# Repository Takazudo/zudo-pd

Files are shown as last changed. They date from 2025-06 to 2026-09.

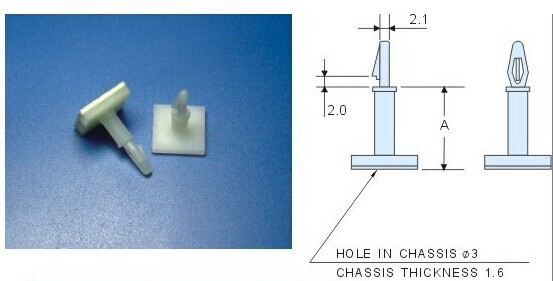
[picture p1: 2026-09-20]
manufacturing/releases/corner-support-review/mechanical/supports/hc11-tayda-drawing.jpg

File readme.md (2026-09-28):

# zudo-pd

A USB-C PD power-supply design for modular synthesizers, with a separate input board
and a synth conversion board for +12 V, −12 V and +5 V.

This is development hardware. The rail budgets are +12 V / 1.2 A, −12 V / 0.8 A and
+5 V / 0.5 A; they are targets, not measured capabilities. The renewed conversion
circuit uses AP63201, LT1963A and adjustable LT3015 parts with explicit headroom and thermal
qualification conditions.

Board B's screw-terminal revision is 110 × 85 mm, with two copper layers and
2 oz copper. Two top-side WJ500V-5.08-2P / C8465 blocks replace the four Fastons;
the wire entries face left. The board returns to a plain left edge and needs no
printed terminal guard. In the installed device, Board B stands on legs with its
front/component face downward. J5 is on that same front face, mating to the
face-down 27 × 40 mm Board P above B in CAD coordinates and below B when installed.
Front voltage labels remain, with normally readable duplicates on the back.
The PD module moves down to free an independent top-left support hole. All four
Ø3.0 mm corner-hole centers are 4 mm from the adjacent edges; the three Ø3.2 mm
PD mounting holes remain separate. P1 and TP3/TP4/TP5 move right together,
retaining seven top-edge contacts on 2.54 mm pitch.

See the [manufacturing guide](manufacturing/README.md) and
[corner-support review destination](manufacturing/releases/corner-support-review/) for prototype
fabrication and assembly review. The PCB is implemented and its native layout
and power-path checks pass; use the package reports for CAD and export status.
The previous front-stack package records the earlier geometry.

**HC-11's 11 mm support height does not clear this front-down assembly over a flat
floor:** the PD substrate reaches 12.7 mm and the terminal drawing maximum is
14.2 mm. The [printed adhesive leg](3dp-files/adhesive-leg/README.md) provides an
18 mm support height, a straight Ø7 mm pole and a 4.5 mm blind screw hole for
M3 × 5 mm screws through the nominal 1.6 mm PCB. See the
[support evidence](boards/board-b/supports/README.md). Physical wire fit, tightening
torque, adhesive retention, connector seating and full-load performance remain unmeasured.

**Board P requires verified 15 V-only operation.** Its new SMAJ16A / C74561
TVS has a 16 V standoff; factory 20 V negotiation is unsafe. First power and program
P from a current-limited 5 V-only source with B disconnected. Read back the NVM,
confirm all 20 V requests are disabled, and verify the configuration after a power
cycle before 15 V use. See the [Board P procedure](doc/src/content/docs/architecture/board-p.md).
The 26 V clamp test point and new 60 V D3 improve the conditioned stress screen;
actual surge, hot behavior and overshoot still require qualification.

## Start with the current design

- [Project brief](doc/src/content/docs/project/project-brief.md)
- [Board roles and interface](doc/src/content/docs/architecture/board-contract.md)
- [Component catalog](doc/src/content/docs/components/catalog/index.mdx)
- [Component-first workflow](doc/src/content/docs/project/component-first-design.md)
- [Release readiness](doc/src/content/docs/architecture/release-readiness.md)
- [Historical design archive](doc/src/content/docs/archive/index.mdx)

The renewal reuses a separate Board P input module and replaces the previous synth
headers and custom printed guards with DEALON DW254P-2X8-L0 / C4749189. Exact part
records, pin maps and source evidence live in `.claude/skills/` and generate the
human-readable component catalog.

## Documentation

The [documentation site](https://pd.takazudomodular.com) uses zudo-doc, MDX and Preact.

Run from the repository root after a frozen workspace install:

```sh
pnpm install --frozen-lockfile
pnpm dev
```

Open `http://localhost:4321`. `pnpm build` prepares the selected models and
component pages before the site build; `pnpm b4push` runs the complete guarded
repository check.

## Design files

`boards/` holds independent board projects. `scripts/schgen/` owns generated schematic
specs and checks. `symbols/` and `footprints/kicad/` hold canonical KiCad assets.
Read [boards/README.md](boards/README.md) before editing or regenerating a board.
The [portable assembly preview](boards/board-b/assembly-preview/preview.kicad_pcb)
opens the P/B stack in KiCad for mechanical review.

**Never use Git LFS.** Large assembled STEP previews are ignored local generated
files. Their [path and hash inventory](manufacturing/local-only-assembly-previews.json)
records exactly what is omitted from Git. The combined KiCad preview, individual
component models, standalone leg STEP, printable STLs and fabrication files remain
in ordinary Git.

A fresh clone does not contain those large review assemblies. Full prototype
checksum checks and the leg's whole-assembly verification require the original
local STEP bytes; they must fail if those bytes are missing or different. See the
[manufacturing guide](manufacturing/README.md#local-assembly-previews) for generating
a new assembly review with its own source and output hashes.

The root `zudo-pd.kicad_*` project and `jlcpcb-order-snapshots/` preserve the old
combined-board orders and their evidence. The [printed accessories](3dp-files/README.md)
contain the current adhesive legs. Only the latest renewal PCB, prototype outputs
and leg design are maintained; no renewal hardware has been released or ordered.

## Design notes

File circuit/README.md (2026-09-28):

# Circuit documentation runtime

This directory holds the zudo-pd-specific configuration, publication choices,
generation checks and project tests for the installed
`@takazudo/zudo-circuit-doc` package. Read [ARCHITECTURE.md](./ARCHITECTURE.md)
before changing the evidence-to-documentation contract.

The root `circuit.config.ts` maps the real evidence bundles, the three schematic
generator specs, KiCad assets and generated site paths into the package. The
package owns the generic validator, projection, renderer, UI and CLI. Project
publication policy and project-specific regressions stay here. Canonical hardware
and evidence rules remain in root [`CLAUDE.md`](../CLAUDE.md) and
[`WORKFLOW.md`](./WORKFLOW.md).

Run commands from the repository root. `pnpm circuit:check` validates the strict
project evidence and the package contract. `pnpm circuit:generate` regenerates the
component pages and preflight report. `pnpm check` checks output, CAD/model parity
and site types. After a build, `pnpm check:site` checks publication, links and
built output. The complete local gate is `pnpm b4push`; it uses one outer heavy
guard and leaves browser smoke as a separately guarded run.

The generated catalog is committed under `doc/src/content/docs/components/` and
must never be hand-edited. The package preflight report is
`circuit/generated/preflight.json`; selected preview assets are generated under
`doc/public/assets/component-previews/`.

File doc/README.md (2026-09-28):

# zudo-pd documentation

A component-first zudo-doc site built with zfb, MDX and Preact. Layout and navigation
come from the framework; this directory owns project content and the reviewed
component publication pipeline.

Install dependencies from the repository root with `pnpm install --frozen-lockfile`.
From the root, `pnpm dev` starts the site on port 4321, history on 4322, and the
package-owned component watcher. `pnpm build` prepares selected models and pages
before building the site. `pnpm b4push` runs the complete guarded repository gate.

The current reading path is **Getting Started → Architecture → Components → How-To**.
The Archive groups previous overview, diagnosis and learning pages at their stable
URLs. Old claims never override the current inventory or schematic.

`src/content/docs/components/` is generated by the installed circuit documentation
package from repo-root `.claude/skills/` evidence and `circuit.config.ts`. Edit exact
records, schematic bindings or publication policy, then prepare from the repository
root; do not hand-edit generated pages, SVG previews or model manifests. See
[CLAUDE.md](CLAUDE.md) and the root [circuit workflow](../circuit/WORKFLOW.md) for
authoring and validation details.

`zfb.config.ts` owns site settings and navigation. `pages/` contains package route
stubs. `src/chrome-bindings.tsx` registers the component previews. `public/` contains
reviewed static assets; deployment configuration remains in `wrangler.toml`.

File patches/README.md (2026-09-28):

# Circuit-doc 0.1.0 compatibility

Removal tracker: [zudo-pd #210](https://github.com/Takazudo/zudo-pd/issues/210).
The runtime request is `^0.1.0`; the root lock resolves the npm 0.1.0 tarball with
its registry integrity and its circuit-package patch hash. This patch edits the **shipped**
`lib/*.js`, their matching `.d.ts`, Python modules and packaged contract schema.
It does not import the upstream TypeScript source or the project validator.
Source review pin: `Takazudo/zudo-circuit-doc@5d0e2b630776489d394be341586b889dfe0d1cb8`.

Every hunk belongs to these linked contract groups (also linked in module headers):

| Upstream report | Shipped modules and changes |
| --- | --- |
| [#103](https://github.com/Takazudo/zudo-circuit-doc/issues/103) | `config/{define,schema,resolve,map}`, `validate/resolved-config`, Python `inventory/{common,led_generator_v1}`, `provider/v1/{evidence,index}`, `core/view-model`, `core/render/{shared,catalog,record}`: contained board/spec declarations; finite value-field MPN configuration; placement DNP and mixed state, with legacy line clients retained. |
| [#104](https://github.com/Takazudo/zudo-circuit-doc/issues/104) | `contract/schema.json`, config and resolved transport, Python `aggregate/orchestrator`, `provider/v1/{paths,evidence,index,canaries}`: candidate identity/owner validation, all owner bundles, unique global evidence IDs, explicit cross-partition rejection, and publication of inventory records only. |
| [#105](https://github.com/Takazudo/zudo-circuit-doc/issues/105) | `config/map`, `core/{publication,reference-descriptor,view-model}`, `provider/v1/{references,index,model-assets}`, `core/render/record`, `ui/component-references`, `scan/built-references`: disjoint selections/exceptions, independently unavailable cards, strict declared local files, nullable types and built-site assertions. |
| [#106](https://github.com/Takazudo/zudo-circuit-doc/issues/106) | `provider/v1/{index,integration,canaries}`, `core/view-model`, scanner positive controls and CLI scanner: nullable denied owners/package membership and matrix-aware denied owner canaries. |
| [#107](https://github.com/Takazudo/zudo-circuit-doc/issues/107) | `scan/artifacts`: configured generated-root exclusion; extra public files scanned; only reviewed canonical footprint hash fields excused in SITE manifests after recomputation and full path/symlink proof. OWNED canaries and other manifest fields remain strict. |

`circuit/publication/` retains the complete selection (59 documents and one honest
exception), 99 field decisions, the unchanged dated document audit and project
glosses. `assets.json` is the scaffold bootstrap allowlist; final site publication
and deliberate existing public assets are reconciled in #207.

`pnpm circuit:prepare` and `pnpm circuit:check` run the project's strict validator
and strict forward tests before invoking package operations. The installed CLI's
validator remains an additional contract gate. `circuit:doctor` is diagnostic.
The root workspace lock resolves both the repository and `doc/` to the same
patched installed modules. The circuit runtime patch and scaffold heading-extractor
patch are separate package boundaries; the old `doc/component-docs/` implementation
was retired in [zudo-pd #208](https://github.com/Takazudo/zudo-pd/issues/208). Root
runtime peers remain pinned to the scaffold versions for meaningful SSR tests.

## Zudo-doc 5.27.0 heading parity

The separate `@takazudo/zudo-doc` 5.27.0 patch is tracked for removal by
[zudo-pd #211](https://github.com/Takazudo/zudo-pd/issues/211). Its source behavior
is reviewed in [zudolab/zudo-doc #4428](https://github.com/zudolab/zudo-doc/issues/4428).
It aligns the built heading extractor with the zfb/CommonMark headings used by this
site, including inline code, character references and the depth window. The retained
strict source-link, built-fragment and redirect checks exercise the installed
scaffold behavior. Do not replace these checks with an allowlist or a looser link
warning rule.

The circuit package patch is temporary compatibility work tracked by
[zudo-pd #210](https://github.com/Takazudo/zudo-pd/issues/210). The scaffold removal
tracker is #211. Follow-up package work covers foreground Chrome scheduling
([#108](https://github.com/Takazudo/zudo-circuit-doc/issues/108)) and responsive
reference-card layout ([#109](https://github.com/Takazudo/zudo-circuit-doc/issues/109)).
The package's enlarged-media contract deliberately uses an empty image alt when the
dialog supplies the full accessible label; the project browser smoke asserts that
contract under [#110](https://github.com/Takazudo/zudo-circuit-doc/issues/110). This
is not a local #110 patch. Keep the project regressions enabled until released
upstream versions supply the contracts owned by each package.

`pnpm test:compatibility` exercises installed package files, never a source clone:
real CLI doctor/validate/generate/check/models/footprints, idempotency, exact corpus
identities/counts, 313 canonical evidence/spec file hashes, negative candidate
source/fact/pin-map mutations, mixed DNP, both finite MPN exceptions, old explicit
evidence anchors, independent SSR/descriptor cards, nullable-model CLI workflow,
missing/corrupt/ambiguous local models, denied owners, generated-root subtraction,
planted MDX/search/dist/public leaks and malformed/unproved/symlinked hash proofs.
The TypeScript consumer smoke checks the shipped declarations in strict mode;
`skipLibCheck` avoids checking unrelated dependency implementation declarations.

The canonical hash fixture is a closed migration baseline, **not** a regeneration
workflow. Changes require an independently reviewed evidence diff with every
changed field identified. Its `files` map is the exact list of hash-covered paths.
The candidate-only evidence stays on disk and under both validators; it is never
silently treated as inventory or as an independent reason to suppress a leak.

The root command surface owns strict project checks, generation, CAD/model parity,
site publication/link checks and guarded b4push. The retained project browser smoke
covers the document-gap record, resolved cards, model and footprint dialogs,
keyboard/focus/no-JS states, the illustrative inductor note and all 12 named
representatives. The PR workflow keeps the Cloudflare preview alias; the production
workflow keeps its guarded domain deployment. Neither workflow deploys from a local
build. Canonical evidence, hardware designs and generated component pages remain
owned by their existing project workflows and contracts.

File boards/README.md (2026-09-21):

# Board projects

The renewed design separates the USB-PD input module from synth conversion.

| Project | Role | Source ownership |
| --- | --- | --- |
| `board-p/` | Reusable USB-PD input module | Schematic generated from `scripts/schgen/board_p_spec.py`; routed PCB and `mechanical.json` own the geometry |
| `board-a/` | Previous USB-PD input-board design | Generated from `scripts/schgen/board_a_spec.py` |
| `board-b/` | Synth conversion, protection and output connectors | Schematic generated from `scripts/schgen/board_b_spec.py`; PCB has separate layout ownership |

The root combined-board KiCad files remain the historical v0.4.0 reference.
Use the [current architecture](../doc/src/content/docs/architecture/board-contract.md)
for interface roles and the [release gates](../doc/src/content/docs/architecture/release-readiness.md)
before exporting an order package.

Board B's screw-terminal revision is 110 × 85 mm with two copper layers,
2 oz outer copper and 76 schematic components. Two top-side WJ500V-5.08-2P / C8465 blocks have wire entries
facing left. J6 carries GND/−12 V and J7 carries +5 V/+12 V. J8/J9 are retired.
The active board has a plain left edge and requires no printed terminal guard.

Board B is installed on legs with its front/component face down. J5 now sits on
F.Cu with the other components. Board P faces that front surface: its component
face points down in CAD, with its front plane nominally at Z=+11.1 mm relative to
B's front plane. This places P physically below B in the installed orientation.
The mapping `pd_to_board_b(x, y) = (y−0.5, x+12)` transforms P's three mounting holes and
all six J5 mating pads together. Board P's own PCB is unchanged. Placement and
transform ownership is `scripts/pcb/board_b_layout.py`.
The P projection is x=−0.5–39.5 mm, y=12–39 mm, leaving B's top-left corner free.
J5 is at (37.2,24.9), 270°. PD holes H1/H2/H3 are Ø3.2 mm at (3.5,16),
(3.5,35) and (32.1,24.8).

The independent HC-11 corner holes H4/H5/H6/H7 are Ø3.0 mm NPTH at (106,4),
(4,81), (106,81) and (4,4), respectively. All four centers are 4 mm from the
adjacent edges. These are board-only holes; supports are separately procured
mechanical accessories, excluded from the electrical BOM and placement output.
The [support evidence](board-b/supports/README.md) retains the exact drawing and
its missing head/base envelopes. HC-11's 11 mm support height does not clear the
front-down assembly above a flat floor: P's substrate reaches 12.7 mm and the
terminal drawing maximum is 14.2 mm. The selected
[18 mm printed-leg prototype](../3dp-files/adhesive-leg/README.md) addresses that
nominal height conflict with separate CAD verification. It leaves the PCB and
JLCPCB package unchanged. Check actual M3 passage through the existing Ø3.0 mm
holes, printed fit, screw retention and adhesive loading. Its four bases require
a 116 × 91 mm adhesive footprint. The HC-11 evidence describes that earlier
support option, not physical testing of the printed leg.

Both front and back carry the screw-terminal voltage labels. Back labels use
B.SilkS mirroring so they read normally when viewed from the back. Validate them
against the same four electrical pins; changing the viewing side does not change
the pin assignments. Select leg and stack spacing from the populated assembly.

P1 plus TP3/TP4/TP5 retains a seven-contact top-edge row on 2.54 mm pitch at y=1.8 mm,
shifted 20 mm right to x=56.19–71.43 mm. Its voltage legend is centered at (88,2).
P1.3 is the shared probe ground; P1.4 remains NC. See the
[board contract](../doc/src/content/docs/architecture/board-contract.md) for exact pins.
The [corner-support review destination](../manufacturing/releases/corner-support-review/)
and [manufacturing guide](../manufacturing/README.md) track the current prototype.
The PCB is implemented and native layout and power-path checks pass; package
reports determine CAD and export status. Physical wire fit, tightening
torque, support clearance and retention, connector seating and full-load behavior
remain unmeasured. Active board files are authoritative; maintain only the latest
renewal PCB and prototype outputs. No renewal hardware has been released or ordered.
The current [printed accessory](../3dp-files/README.md) is the adhesive leg;
the plain-edge screw-terminal board requires no printed connector guard.

Board P D5 is now Littelfuse SMAJ16A / C74561, with a 16 V standoff. **20 V
negotiation is unsafe.** First power and program P at 5 V only with B disconnected;
read back the NVM, disable every 20 V request and verify the 15 V-only policy after
a power cycle before connecting a higher-voltage-capable PD source. Follow the
[Board P procedure](../doc/src/content/docs/architecture/board-p.md).
Board B D3 is SDT5A60SA-13 / C3024223, rated 60 V reverse. The conditioned 26 V / 25 °C
clamp screen clears the former table-point mismatch; installed surge and thermal
performance remain open.

## Generated schematics

Edit the spec, then regenerate the schematic; do not hand-edit generated output:

```sh
python3 scripts/schgen/gen_schematic.py board_p_spec
python3 scripts/schgen/gen_schematic.py board_a_spec
python3 scripts/schgen/gen_schematic.py board_b_spec
```

See `scripts/schgen/README.md` for baseline, decision and ERC verification. The
component audit must remain in parity with the exact generated MPN/LCSC/footprint
placements. A PCB change must be checked against that final schematic.

## Libraries resolve from each board directory

For projects two levels below the repository root, shared library references use:

```text
${KIPRJMOD}/../../symbols/zudo-pd.kicad_sym
${KIPRJMOD}/../../footprints/kicad/zudo-power.pretty
```

Open the paired `.kicad_pro` project in its board directory. Active 3D model paths
use `${KIPRJMOD}/../../footprints/kicad/zudo-pd.3dshapes/`; no global KiCad model
path setup is required. Export snapshots use rebased paths for their deeper
`source/` directory, which must not be copied back into the active board. Verify
both active boards with `scripts/pcb/check-model-paths.py` before exporting.
The [STEP datum audit](../footprints/kicad/step-datum-verification.json) checks
the reviewed active STEP/WRL pairs. Re-run it with `uv run scripts/pcb/verify-step-datums.py`;
its sampled surface comparison establishes model consistency, not physical fit.
L1's visible model is an illustrative maximum-body envelope, not an exact
manufacturer model; see the [manufacturing guide](../manufacturing/README.md).
The [portable P/B assembly preview](board-b/assembly-preview/preview.kicad_pcb)
shows the complete stack with local model files. It is a review copy, not the
manufacturing PCB; retain its verification report when sharing it.

Check a project's own library tables when importing a reusable module. Package names,
pad numbers, model paths and connector pin assignments must resolve in this repository.

## Connector and mounting changes

Board B J10/J11 use DEALON DW254P-2X8-L0 / C4749189 with the conventional synth power
pin map (pins 1–2 = −12 V). The shroud replaces custom printed guards. Derive edge
clearances from the actual connector body and mating cable; do not inherit the old
printed-part contour. Board P's mounting geometry belongs to its PCB source and
mechanical record, not to assumptions about the previous Board A design.

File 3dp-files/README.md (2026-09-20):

# Printed accessories

The current [adhesive-leg prototype](adhesive-leg/README.md) supports Board B at
its four existing corner holes. Each leg has an 18 mm PCB seating height, a
14 × 14 × 2 mm adhesive base and a straight Ø7 mm pole. A screw
enters from the PCB back into the user's proven, untapped M3 aperture: the exact
27-vertex profile forms a 4.5 mm blind bore. There is no taper or larger lower
cavity. Start with an M3 × 5 mm screw: through the 1.6 mm PCB it inserts 3.4 mm,
leaving a nominal 1.1 mm gap to the blind floor. The previous M3 × 8 mm
recommendation does not apply to this shorter bore.

This taller prototype addresses the nominal height conflict of the earlier 11 mm
HC-11 support. Printing, adhesive strength, M3 passage and retention still require
physical checks. The existing PCB corner holes remain nominally 3.0 mm, giving
zero nominal diametral clearance for an M3 screw. The accessory does not change
the PCB or the current JLCPCB prototype package. See its README and verification artifacts
for the prototype's scope and limits.

The current 110 × 85 mm Board B uses two top-side WJ500V-5.08-2P / C8465 screw-terminal
blocks and shrouded DEALON synth headers. It requires no printed connector guard.
Only the current adhesive-leg design is maintained here. Current prototype
manufacturing outputs are in `manufacturing/releases/corner-support-review/`;
no renewal hardware has been released or ordered.

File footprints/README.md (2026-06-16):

# PCB Footprints and Package Specifications

This directory contains PCB footprint diagrams and package specifications for all components used in the USB-PD modular synthesizer power supply project.

## Footprint Images

| Component | File | Package | JLCPCB Part | Mount Type |
|---|---|---|---|---|
| **CH224D** | `CH224D.png` | QFN-20 (3×3mm) | C347423 | SMD |
| **LM2596S-ADJ** | `LM2596S-ADJ.png` | TO-263-5 | C347423 | SMD |
| **L7812CV** | `L7812CV.png` | TO-220 | C86206 | Through-hole |
| **L7805ABD2T** | `L7805ABD2T.png` | TO-263-2 (D2PAK) | C2914 | SMD |
| **CJ7912** | `CJ7912.png` | TO-252-2L (DPAK) | C94173 | SMD |
| **SMAJ15A** | `SMAJ15A.png` | SMA (DO-214AC) | C571368 | SMD |
| **PRTR5V0U2X** | `PRTR5V0U2X.png` | SOT-143 | C5199240 | SMD |
| **USB-TYPE-C-009** | `USB-TYPE-C-009.png` | 6-pin Type-C | C456012 | SMD |

## Package Documentation (PDFs)

Reference documents for standard package types:

### Component-Specific Datasheets
- `CH224D-datasheet.pdf` - WCH CH224D USB PD controller full datasheet
- `LM2596S-datasheet.pdf` - LM2596S-ADJ DC-DC converter datasheet
- `SMAJ-datasheet.pdf` - SMAJ series TVS diode specifications

### Generic Package Specifications
- `D2PAK-package.pdf` - TO-263-2 package dimensions (L7805ABD2T)
- `DPAK-package.pdf` - TO-252 package dimensions (CJ7912)
- `SMA-package.pdf` - DO-214AC package dimensions (SMAJ15A)
- `SMA-DO214AC.pdf` - Alternate SMA package specification
- `SOT143-package.pdf` - SOT-143 package dimensions (PRTR5V0U2X)
- `TO-220-package.pdf` - TO-220 package dimensions (L7812CV)

## Usage Notes

### For PCB Layout Design
1. **Footprint images** (`.png` files) show:
   - Package outline dimensions
   - Pin/pad layout and numbering
   - Recommended PCB land pattern
   - Thermal pad requirements (where applicable)

2. **Package PDFs** provide detailed specifications:
   - Precise mechanical dimensions
   - Tolerances and variations
   - Soldering recommendations
   - 3D package profiles

### Thermal Considerations
- **QFN-20 (CH224D)**: Requires exposed pad connection with thermal vias
- **TO-263/D2PAK (LM2596S-ADJ, L7805ABD2T)**: Metal tab for heat dissipation
- **TO-252/DPAK (CJ7912)**: Metal tab soldered to PCB copper pour
- **TO-220 (L7812CV)**: Through-hole with optional heatsink mounting

### SMD vs Through-Hole
- **7 SMD components**: CH224D, LM2596S-ADJ, L7805ABD2T, CJ7912, SMAJ15A, PRTR5V0U2X, USB-C connector
- **1 Through-hole**: L7812CV (TO-220) - can use heatsink if needed

## Sources

Footprint images and datasheets obtained from:
- Manufacturer official websites (WCH, STMicroelectronics, Diodes Inc., Nexperia, etc.)
- JLCPCB component library
- Industry-standard package specification documents
- SnapEDA and similar PCB design resources

All footprints extracted at 200-300 DPI resolution for PCB design clarity.

---

*Last updated: 2025-12-28*

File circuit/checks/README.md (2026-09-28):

# Checks

What each project check establishes, and what it does not. Report a check's actual output, including its `SCOPE:`, `SKIP:` and `WARN:` lines; never summarize a skipped check as passed.

| Command | Establishes | Does not establish |
| --- | --- | --- |
| `pnpm circuit:check` | The evidence bundles, inventory, routing, integration rules and (when CAD is enabled) pin assets satisfy the v1 contract; the package's seeded self-test still detects known mutations | That any electrical claim is correct for the design, that a source was read correctly, or that declared placements match a schematic (see the `SCOPE:` line) |
| `pnpm circuit:generate` | Generated component pages and `circuit/generated/preflight.json` reflect the current evidence and selection | That the evidence is current with its remote sources |
| `pnpm check` | Validation passes, committed generated output matches a dry-run generation (drift and ownership conflicts), selected models and footprint previews match their inputs, the doc site type-checks | Anything about the built HTML |
| `pnpm build` then `pnpm check:site` | The built site references only files that exist, publishes nothing outside the selection and the assets allowlist, and has no broken links or anchors | Visual rendering or island behavior in a browser |
| `pnpm b4push` | Retained circuit tests, strict project Python gates, host types and CAD/model checks, build, site checks and generated output drift/idempotency under one outer heavy guard | Browser behavior; run a browser suite separately |
| `pnpm test:model-viewer:browser` | The project's 12 named component representatives render at two widths and two themes, with viewer, dialog, no-JS, navigation and illustrative-model assertions | Anything about electrical performance or hardware fit; it requires a built site and Chrome |
| `pnpm exec zudo-circuit-doc check-browser` | Additional scaffold browser coverage for configured representatives or up to 3 derived representatives | Anything about a representative it never resolved (reported `SKIP`), and anything at all when it exits `4` |
| `pnpm exec zudo-circuit-doc validate --online` | Retained non-volatile source hashes still match the bytes the URLs serve today | That the documents support the recorded claims; it never alters retained evidence |
| `pnpm previews:generate`, `pnpm exec zudo-circuit-doc footprints check` | Footprint SVG previews are rendered from, and match, the selected footprints | Dimensional correctness or pin correspondence; a preview is a rendering |
| `pnpm circuit:doctor` | Which required and optional tools are present | That any check passes |

### `check-browser` representative pages

The scaffold `check-browser` resolves which pages to exercise in this order:

1. `--representatives <json>` on the command line.
2. `browserSmoke.representatives` in `circuit.config.ts`, used exactly as configured — even an explicit empty list.
3. Otherwise, up to 3 representatives **derived** from the preflight report: published record slugs, sorted, filtered to the ones whose generated page has a decodable component-references section (a reviewed PDF, a footprint and a WRL model), and, once the site is built, whose built output carries the matching marker and assets. A derived run prints `INFO: using derived representatives: ...`.

A declared-zero project (nothing published) is a `SKIP`, not a failure. If records are published but derivation finds none that qualifies, the command exits `4` rather than silently checking nothing — set `browserSmoke.representatives` in `circuit.config.ts` to name pages explicitly.

The project smoke is separate because its 12 representative list also covers the `rec-c335982` document gap and the illustrative inductor model note. For a local browser run, serialize both the heavy process and browser launch:

```sh
bash "$HOME/.codex/scripts/heavy-guard.sh" -- bash "$HOME/.claude/scripts/playwright-guard.sh" --wait 300 -- pnpm test:model-viewer:browser
```

Exit 75 from `heavy-guard` means the suite did not run; read its `verdict=` line first, retry `ENV_SUSPECT` once, and defer a persistent environment failure. Exit 75 from `playwright-guard` means another browser session owns the slot; wait and retry. Exit 4 for a missing optional browser is `not run`, never a pass, and does not satisfy a mandatory issue or PR browser gate.

## Exit codes

| Code | Meaning |
| --- | --- |
| `0` | Pass |
| `1` | Check failed |
| `2` | Usage or configuration error |
| `4` | Not run: an optional tool (Docker, Chrome) is missing, or (`check-browser` only) records are published but none qualifies for a default representative and none was configured |

## What no check establishes

`COVERED` coverage, a clean validation and a green build are not hardware sign-off. Physical fit, assembled state, programmed state and bench behavior are established only by recorded observations (Workflow F in [WORKFLOW.md](../WORKFLOW.md)).

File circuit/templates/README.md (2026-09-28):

# Authoring templates

These templates are **not published**. Copy one into the documentation tree when the activity it describes actually happens; do not publish empty copies to fill the navigation.

## Project documentation templates

The `project-docs/` tree mirrors the site's sections. To use a template, copy it to the same relative path under `doc/src/content/docs/`, give the copy a topic-specific filename, `title`, `description` and `sidebar_position`, and replace the "Not entered" prompts as facts become known. Links inside a template point at the sibling template locations; after copying, keep a link only if its target page exists in the site.

| Template | Use it when | What to enter |
| --- | --- | --- |
| [project/index.mdx](./project-docs/project/index.mdx) | The brief must be rebuilt from scratch (the live brief is already published at `project/index.mdx`) | Purpose, user behavior, constraints, current design revision |
| [project/next-actions.mdx](./project-docs/project/next-actions.mdx) | Resetting the handoff page (the live page is already published) | Current open questions, the next bounded task, blocked work |
| [project/task-request.mdx](./project-docs/project/task-request.mdx) | Delegating a bounded research or implementation task to an agent | Goal, scope, references, outputs and a definition of done |
| [project/change-impact.mdx](./project-docs/project/change-impact.mdx) | Before applying a change with downstream effects (Workflow G) | Affected components, interfaces, generated assets and tests |
| [architecture/overview.mdx](./project-docs/architecture/overview.mdx) | Resetting the architecture overview (the live page is already published) | Functional blocks, operating states, unconfirmed boundaries |
| [architecture/interfaces.mdx](./project-docs/architecture/interfaces.mdx) | Once blocks or connectors are proposed | Power, signal, mechanical and programming boundaries |
| [research/component-candidate.mdx](./project-docs/research/component-candidate.mdx) | Comparing or researching a component (Workflow A) | Research question, criteria, linked evidence, missing proof |
| [decisions/decision.mdx](./project-docs/decisions/decision.mdx) | Making a consequential choice | Alternatives, chosen direction, tradeoffs, evidence and conditions |
| [decisions/sourcing.mdx](./project-docs/decisions/sourcing.mdx) | Assembly or procurement becomes relevant | Population policy, cost reasoning, dated sourcing observations |
| [verification/bring-up.mdx](./project-docs/verification/bring-up.mdx) | Planning or recording one verification run (Workflow F) | Revision, setup, planned checks, results and limits |

For repeated records, duplicate the relevant template with a topic-specific filename. A decision ID identifies a decision across edits; a verification report identifies one execution against one revision, so never overwrite a failed run with a later successful one.

These pages explain intent, rationale and decisions. Exact component identity, sources, facts, pin maps and coverage belong to the owner evidence bundles under `.claude/skills/component-*/`; the component pages under `/docs/components/` are generated from them. Do not maintain a second rating table, pin table or catalog by hand. When an argument needs a number, cite the canonical fact ID and keep its qualifier and conditions.

## CAD asset receipt

| Template | Use it when |
| --- | --- |
| [cad-asset-receipt.json](./cad-asset-receipt.json) | Recording an acquired symbol, footprint or 3D model (Workflow D); save the copy as `circuit/cad-receipts/ASSET_ID.receipt.json` |
| [cad-asset-receipt.md](./cad-asset-receipt.md) | Explains every receipt field and the fidelity classes; copy it beside the JSON only when a longer explanation is needed |

See [WORKFLOW.md](../WORKFLOW.md) for the workflows that use each template and [agent-task-examples.md](../agent-task-examples.md) for short requests that lead to them.

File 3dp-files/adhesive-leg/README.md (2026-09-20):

# Adhesive PCB leg with M3 screw grip

Print **four legs** for the current Board B. The leg has an **18 mm seating height**,
a broad flat adhesive base and a screw hole copied from the user's repeatedly
tested `bar-30hp.stl`. No modeled thread, tap or threaded insert is required by this
design; the screw engages the same printed aperture as the reference rail.

- [Single leg STL](generated/adhesive-leg-18mm-m3.stl)
- [Four separate legs on one print plate](generated/adhesive-leg-18mm-m3-4x.stl)
- [Preview](generated/preview.png) and [section view](generated/section.png)
- [Editable STEP](generated/adhesive-leg-18mm-m3.step)
- [Installed assembly](generated/installed.png) and [fit report](generated/fit-check.json)

All dimensions are millimetres. Print at **100% scale**, with the flat base on the
bed and the screw opening upward. Use the material and hole-compensation settings
that worked for the tested rail. The straight vertical bore needs no supports.

| Feature | Dimension |
|---|---|
| Adhesive face to PCB seating face | 18 mm |
| Base | 14 × 14 × 2 mm, rounded corners R2 |
| Pole and PCB seating face | Straight Ø7 mm; no top taper |
| Pole-to-base reinforcement | R2 fillet |
| M3 gripping section | Exact reference polygon, 4.5 mm deep |
| Total blind depth | 4.5 mm; no lower cavity |
| Solid material below blind hole | 13.5 mm |

The measured reference hole is slightly lobed, with 27 straight edges and a
2.8928 × 2.9149 mm bounding box. Those dimensions are not a circular drill size.
[reference-bore.json](reference-bore.json) retains the exact polygon from source
hole 12, its original coordinates and source hash. The upper 4.5 mm gripping
section preserves that profile without taper, smoothing or an entrance chamfer.
The hole ends after that 4.5 mm section; everything below it is solid.
The original rail STL is unchanged.

Use an **M3 × 5 mm non-countersunk screw**, inserted from the visible PCB back
into the leg. Through the 1.6 mm board it enters 3.4 mm, leaving 1.1 mm to the
blind floor. An M3 × 6 mm screw with a washer at least 0.5 mm thick enters at
most 3.9 mm, leaving at least 0.6 mm. These are nominal dimensions; verify the
actual hardware stack. **The earlier M3 × 8 mm screw is too long for this revision.**
Fit the legs and screws before applying adhesive to the flat undersides.

The existing PCB corner holes are nominally **3.0 mm**, so a nominal Ø3 mm screw
has zero designed passage clearance. Check that the actual screw passes freely
through the finished PCB hole; this STL task does not enlarge the PCB holes or
change the JLCPCB package. The copied plastic gripping aperture and the PCB
passage hole serve different purposes.

The four feet sit at H4 (106,4), H5 (4,81), H6 (106,81) and H7 (4,4). Their bases
extend 3 mm beyond the PCB edges, requiring a **116 × 91 mm** adhesive footprint.
The PCB remains 110 × 85 mm. The 7 mm seating diameter keeps the leg clear of the
nearby top-right fuse. The earlier taper served this clearance; a straight
7 mm pole maintains it throughout the post. With an 18 mm seating
height, the 14.2 mm terminal envelope has 3.8 mm nominal floor clearance. Adhesive
tape adds its compressed thickness; no tape allowance is needed to obtain the
18 mm geometry.

The [fit report](generated/fit-check.json) records checks against the current
populated B+P assembly, including the four whole legs and conservative component
envelopes. Printed fit, screw retention/torque, adhesive grip and temperature
performance remain physical checks. The user's proven rail geometry is the screw
fit reference; it is not a new load or material qualification for these legs.

Regenerate and verify:

```sh
uv run 3dp-files/adhesive-leg/generate.py
uv run 3dp-files/adhesive-leg/verify.py
```

[spec.json](spec.json) holds the editable dimensions. The generator emits the
single STL, four-part plate, STEP and rendered views for the current design. The verifier checks the
actual exported geometry and assembly; its optional reference-STL argument can
also recheck the user-supplied rail. Existing PCB and manufacturing files are
read-only inputs.

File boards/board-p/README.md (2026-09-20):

# Board P — reusable USB-PD core

Board P is the current routed power-input module. It supplies the downstream Board B
through the six-position XFCN header pair. Board A remains historical schematic
evidence; its gate network and connector are different and must not be treated as
Board P's as-built circuit.

`../../scripts/schgen/board_p_spec.py` is the schematic source of truth. Regenerate:

```sh
python3 scripts/schgen/gen_schematic.py scripts/schgen/board_p_spec.py
```

The PCB retains the routed module's pad/copper geometry. Shared exact parts use the
current project's canonical library names, while the PCB embeds its retained physical
footprints. Updating all PCB footprints from the shared library would change that
geometry and requires a fresh layout review. `layout-verification.json` records the
import comparison; `mechanical.json` records dimensions and mating coordinates.

## Interface and mechanical contract

| JOUT1 pin | Net | Function |
| --- | --- | --- |
| 1, 2 | VBUS_OUT | Switched nominal 15 V; paired power contacts |
| 3 | ATT | Active-low open-drain attach indication |
| 4 | PDOK | Open-drain contract indication; depends on programmed configuration |
| 5, 6 | GND | Paired return contacts |

JOUT1 is PZ254V-11-06P (C492405); Board B J5 is PM254V-11-06-H85
(C2832269). The pair is unkeyed. Verify pin-1-to-pin-1 orientation and every net
before mating. The old Board A JST XH connector has a different pitch and does not
mate directly. Both XFCN parts have a manufacturer 3 A contact rating; paired contacts
do not raise the USB-PD source's 3 A contract limit.

The board is 27 × 40 mm, two layers, 1.6 mm thick. Its mounting holes are 3.2 mm
NPTH for M3 hardware at (4, 4), (23, 4), and (12.8, 32.6) mm, measured from the
upper-left outline corner in KiCad coordinates. JOUT1 pin 1 is at (6.55, 37.7) mm;
subsequent pins advance 2.54 mm along X. The USB opening is at the y=0 edge.
The female body is 8.5 mm tall; actual board spacing and mating engagement require
a stack fit check rather than assuming that body height equals the standoff length.

## Circuit and configuration state

The intended configuration is two sink PDOs, PDO2 = 15 V / 3 A, and
`POWER_ONLY_ABOVE_5V = 1`. **No retained programmed NVM image, persistent readback,
or bench-qualified 3 A output accompanies this PCB.** The design intention does not
establish the factory or installed state. First provision with a current-limited
5 V-only source and the downstream board disconnected. Retain the received image,
40-byte programmed image, byte-for-byte readback, reset reload and full power-cycle
readback before connecting a PD source and load.

Board P's 100 kΩ/150 kΩ gate divider gives ideal steady VGS = −6 V at 15 V and
−8 V at 20 V. C35 connects gate to source; R21 is a 10 kΩ reset pull-down with
RESET available on J2.4. These are Board P facts. The retained Board A records describe
its older 56 kΩ gate resistor, ground-referenced C35, and grounded reset.

Open electrical gates remain: VREG_2V7 feeds 4.7 kΩ I2C pull-ups even though retained
controller documentation only authorizes decoupling; confirm manufacturer approval
or revise this circuit and verify programming-jig logic levels. The SMAJ20A's 32.4 V
clamp table point exceeds Q1's 30 V VDS and the controller's retained 28 V absolute
maximum; actual source/rail/gate transient waveforms and duration remain unmeasured.
NVM policy, switch inrush, steady full-load temperature, and connector temperature
must be checked with the actual downstream load. The nominal 45 W contract alone
cannot establish those results.

## Checks and manufacturing state

The renewal check passed native KiCad netlist comparison (23 nets, 91 nodes), ERC
with zero errors, and PCB DRC with zero errors and zero unconnected items. The
strict component registry and its 53 contract tests passed. The order exporter
accepted 19 fitted components in 14 BOM lines, all on the top side. R17/R18 and
D6/D7 remain intentionally DNP; J2/J3 and MH1/MH2/MH3 are bare copper/mechanical
features excluded from assembly.

Retained warnings are explicit: 29 ERC pin-type warnings; 50 PCB DRC warnings
(23 shared-library footprint mismatches, 19 small-text, 3 silk-over-copper,
2 silk-to-edge, 1 silk overlap, 1 duplicate SCL via, 1 dangling gate-track stub);
three schematic-parity warnings identify the PCB-only mounting holes. No ERC/DRC
error was disabled to obtain these results. Warnings do not establish an assembled
or bench-qualified product.

The XFCN male and female drawings were downloaded on 2026-09-20, confirmed as
PDF drawings for the specified connector families and six-position dimension
rows, and matched their retained SHA-256 values. The current HRO drawing request
returned HTTP 403, so its earlier retained manufacturer extract remains the evidence
and the current retrieval was not represented as a new successful verification.
Yageo and UNI-ROYAL primary documents were readable during the renewal audit.

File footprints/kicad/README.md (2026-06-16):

# KiCad Footprints

This directory contains KiCad footprint files (.kicad_mod) for components used in this USB-PD power supply project. All footprints were downloaded from LCSC/EasyEDA using the [easyeda2kicad.py](https://github.com/uPesy/easyeda2kicad.py) tool.

## Key Component Footprints

### USB-PD Stage
- **QFN-20_L3.0-W3.0-P0.40-BL-EP1.7.kicad_mod** - CH224D USB PD Controller (C3975094)
- **TYPE-C-SMD_TYPE-C-6P.kicad_mod** - USB Type-C 6P Female Connector (C456012)

### DC-DC Converter Stage
- **TO-263-5_L10.2-W8.9-P1.70-BR.kicad_mod** - LM2596S-ADJ Buck Converter (C347423) — also used for U4 in inverting buck-boost config

### Linear Regulator Stage
- **TO-220-3_L10.0-W4.5-P2.54-L.kicad_mod** - LM7812CV +12V Regulator (C2914)
- **TO-263-2_L10.0-W9.2-P5.08-LS15.3-TL-CW.kicad_mod** - L7805ABD2T +5V Regulator (C86206)
- **TO-252-3_L6.5-W5.8-P4.58-BL.kicad_mod** - CJ7912 -12V Regulator (C94173)

### Passive Components
- **C0603.kicad_mod** - 0603 Capacitor
- **R0603.kicad_mod** - 0603 Resistor
- **CAP-SMD_BD4.0-L4.3-W4.3-LS5.0-FD.kicad_mod** - SMD Electrolytic Capacitor (small)
- **CAP-SMD_BD18.0-L19.0-W19.0-LS20.4-FD.kicad_mod** - SMD Electrolytic Capacitor (large)

### Protection & Indicators
- **SMA_L4.4-W2.8-LS5.4-RD.kicad_mod** - SMA Diode Package (TVS, Schottky)
- **SOD-123FL_L2.8-W1.8-LS3.7-RD.kicad_mod** - SOD-123FL Diode Package
- **LED0603-RD.kicad_mod** - 0603 LED (Red)
- **LED0603-R-RD_WHITE.kicad_mod** - 0603 LED (White)

### Connectors
- **HDR-TH_16P-P2.54-H-M-R2-C8-S2.54.kicad_mod** - 16-pin 2.54mm Through-hole Header (Eurorack Power)
- **HDR-TH_3P-P2.54-V-M.kicad_mod** - 3-pin 2.54mm Through-hole Header
- **HDR-SMD_6P-P2.00-V-M_XBK_R2.kicad_mod** - 6-pin 2.00mm SMD Header
- **HDR-SMD_8P-P2.54-V-M-LS4.8_R2.kicad_mod** - 8-pin 2.54mm SMD Header
- **DC-IN-TH_DC550250-0366-2H.kicad_mod** - DC Input Jack (Through-hole)

## Usage

### In KiCad
1. Add this directory to your KiCad footprint library list
2. Select footprints when assigning components in your schematic

### Downloading Additional Footprints

To download footprints for other components:

```bash
easyeda2kicad --lcsc_id <LCSC_ID> --footprint
```

The footprints will be saved to `~/Documents/Kicad/easyeda2kicad/easyeda2kicad.pretty/` and can be copied to this directory.

Example:
```bash
# Download CH224D footprint
easyeda2kicad --lcsc_id C3975094 --footprint

# Copy to project
cp ~/Documents/Kicad/easyeda2kicad/easyeda2kicad.pretty/*.kicad_mod ./
```

## Notes

- All LCSC part numbers are referenced in `/doc/docs/inbox/parts-list.md`
- Footprints include pads, silkscreen, and courtyard layers
- Some footprints may include 3D model references (if available from EasyEDA)

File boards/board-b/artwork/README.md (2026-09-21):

# Board B back silkscreen

The current PCB uses the two SVGs supplied for the back artwork:

- `pattern.svg`: unchanged copy of `Asset 6.svg`.
- `logo.svg`: unchanged copy of `Asset 5.svg`.

The pattern fills the back-view left area, with an unprinted strip on the right
for branding, terminal labels and the four-line specification block:

```text
zudo-pd v1
+12V : 1.2A
-12V : 0.8A
+5V : 0.5A
```

The current values are shared whole-board design targets, with physical full-load
and temperature qualification still open. The SVG
pattern is heavier than the thin-line rough mockup. Its proportions are preserved
and its top/bottom are cropped to the board. The supplied mirrored logo is split
into emblem and lettering and rotated 90 degrees. In the portrait back view
shown by the user, the emblem sits on the left and the two-line brand name on the
right; both read normally. Fine feather and fish details may merge or disappear
in physical printing.

`back-preview.png` is a native KiCad render of the actual PCB;
`back-portrait-preview.png` shows the rotated view used for the branding layout. Open
`../board-b.kicad_pcb` and view its bottom side to inspect the editable artwork.
It consists of filled `B.SilkS` polygons and four mirrored text items in the
`Board B back artwork` group. Copper, mask layers, holes, component placement,
front silkscreen and existing back voltage labels are unchanged.

The pattern has a 0.8 mm outline inset. Artwork is clipped at least 0.3 mm outside
conservative pad/mask bounding boxes, with another 0.3 mm around the complete
J5, J10 and J11 solder rows. No graphics are added to copper or solder mask.
This is decorative artwork, not an insulation or thermal treatment.

Regenerate into an ignored staging path with:

```sh
uv run scripts/pcb/apply-back-silkscreen.py \
  --branding-only \
  --output tmp/back-silk/candidate.kicad_pcb \
  --report tmp/back-silk/verification.json
```

`--branding-only` preserves the existing native pattern polygons byte-for-byte,
including manual edits. Omit it when generating the complete artwork for a fresh
layout. Existing user-edited rail-label positions and styling are always retained.

The script uses the retained SVGs, resolves nonzero SVG fills and their holes,
flattens curves, clips artwork around board pads, and uses KiCad polygon fracture
to retain internal openings. It replaces its previous generated group and the
old one-line title. It refuses any change to the remaining PCB structure.
`verification.json` records that structural check and the source/result hashes.

Inspect a bottom render and run native DRC before promoting a candidate. Refresh
PCB-dependent reports and the sole current prototype package afterward; do not
keep superseded output packages. The original local KiCad project-settings edit
is separate from this artwork change.

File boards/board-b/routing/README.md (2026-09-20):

# Corner-support routing

The active PCB is 110 × 85 mm. J5 is on the front at (37.2,24.9), 270 degrees.
Board P faces Board B with P(x,y) mapping to B(y−0.5,x+12); its nominal CAD face plane is
11.1 mm above B. In the installed orientation B faces down on legs and its back
silkscreen is visible from above. Nominal CAD spacing is not a qualified spacer.

P projects to x=−0.5–39.5 mm, y=12–39 mm, freeing the independent top-left support.
Its three Ø3.2 mm holes are H1(3.5,16), H2(3.5,35) and H3(32.1,24.8).
The four independent HC-11 Ø3.0 mm corner holes are H4(106,4), H5(4,81),
H6(106,81) and H7(4,4). Keep those interfaces separate.

C5 moves to (18,6), 0°; C46 to (28,6.5), 180°; C32 to (26,22), 0°;
R3 to (26,29), 180°; R4 to (26,26), 90°; and D2 to (33.75,35), 90°.
The complete seven-contact pogo row moves 20 mm right: P1 center (60,1.8),
TP3/TP4/TP5 at (66.35,1.8)/(68.89,1.8)/(71.43,1.8). Its voltage legend is
centered at (88,2). Preserve all electrical assignments and both-side terminal labels.

The active `../board-b.kicad_pcb` is the layout source. Current placement rules
are in `scripts/pcb/board_b_layout.py`; do not reconstruct the PCB from a
superseded migration input or route session.
Input paths use 1.5 mm traces; measurement and status branches use 0.25 mm.
Load outputs retain the 1 mm screen. Measurement branches are excluded from
current-path proofs. Existing ground pours remain; affected old ground branches
are removed so the filled planes reconnect their pads. All existing ground,
thermal, connectivity and current-path checks still apply.

Copy the active `.kicad_pro` beside a temporary PCB after generation, because a
native pcbnew save can reset project defaults. Refill and check the candidate,
then promote only after native DRC and mechanical/power checks pass. Run parity
against the actual matching schematic and project. Use `configure-board-b.py`
after native project changes to restore the reviewed routing/manufacturing rules.

For a fresh route, `place-board-b.py` generates current placement,
`prepare-routing.py` applies explicit net classes, and `finish-board-b.py`
imports the new session and adds pours. Do not apply a prior session's special
completion paths. Every new route requires native and geometry checks.

Only the latest PCB and its current workflow are maintained. The PCB is implemented and native layout
and power-path checks pass. Package reports determine CAD and export status; the
destination is `manufacturing/releases/corner-support-review/`. This is a prototype
review package, not a released product or submitted order.

HC-11's 11 mm height does not clear the front-down assembly over a flat floor.
P's back substrate reaches 12.7 mm and the terminal drawing maximum is 14.2 mm.
The [support evidence](../supports/README.md) records that earlier option's height
and head/base envelope limits. The separately developed
[18 mm printed leg](../../../3dp-files/adhesive-leg/README.md) addresses the nominal
height conflict without changing the PCB or routing. Its own CAD verification and
physical fit checks are separate from the HC-11 support-option evidence.

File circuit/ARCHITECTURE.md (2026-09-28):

# Component evidence and documentation architecture

The component catalog is a reviewed projection of the project's structured
evidence. It does not replace the evidence, electrical review, or hardware
qualification. Root `CLAUDE.md` remains the authority for current hardware state,
measured limits and repository storage rules; `circuit/WORKFLOW.md` defines the
agent workflow.

## Ownership and data flow

The installed `@takazudo/zudo-circuit-doc` package owns generic validation,
provider adaptation, publication policy machinery, rendering, UI islands and the
CLI. Its project inputs come from root `circuit.config.ts`. This repository owns
the component evidence, the exact publication matrix and selection, CAD assets,
authored rationale, root scripts and project-specific checks.

| Path | Owner | Contract |
| --- | --- | --- |
| `.claude/skills/component-*/` | Evidence owners | Exact part facts, provenance, coverage, routing, interactions and pin maps |
| `.claude/skills/component-spec-audit/references/inventory.json` | Project | Orderable identities and placements, checked against the three board generator specs |
| `.claude/skills/component-spec-audit/references/candidates.json` | Project | Validated alternatives that are not inventory records or published parts |
| `.claude/skills/circuit-spec-integration/references/rules.json` | Project | Eleven current cross-component rules, their inputs, conditions and open evidence stages |
| `circuit.config.ts` | Project | Provider (`led-generator-v1`), Board A/B/P bindings, package paths, Python floor and preview configuration |
| `circuit/publication/` | Project | Reviewed field matrix, selected records/sources, asset allowlist, document audit and integration gloss |
| `@takazudo/zudo-circuit-doc` | Package | Generic validator, projection, renderers, islands and CLI |
| `patches/@takazudo__zudo-circuit-doc@0.1.0.patch` | Temporary component-package bridge | Reviewed compatibility until the released package supplies the same contracts |
| `patches/@takazudo__zudo-doc@5.27.0.patch` | Temporary scaffold bridge | Project heading-ID parity until the pinned scaffold release includes the reviewed behavior |
| `doc/src/content/docs/components/**` | Generator | Generated catalog, record and integration pages; never edit by hand |
| `circuit/generated/preflight.json` | Generator | Deterministic publication report; never edit by hand |
| `doc/public/assets/component-previews/**` | Generator | Selected footprint SVGs and WRL models; never edit by hand |
| `circuit/tests/` and `circuit/scripts/` | Project | Corpus, publication, host, workflow, links, model and hardware-specific checks; no alternate generator |

The evidence flow is:

```mermaid
flowchart LR
  E[Owner bundles and inventory] --> V[Strict project validators]
  C[circuit.config.ts] --> P[Installed package]
  S[circuit/publication/] --> P
  V --> P
  P --> G[Generated pages and preflight]
  P --> A[Selected CAD preview assets]
  G --> D[Built documentation site]
  A --> D
  D --> Q[Publication, link, fragment and leak checks]
```

The configured provider is `led-generator-v1`. It binds placement identity and
placement-level DNP state to `scripts/schgen/board_a_spec.py`,
`board_b_spec.py` and `board_p_spec.py`. The two finite value-field MPN exceptions
are `C144397` and `C591344`; the setting is in `circuit.config.ts`. The canonical
direct-routing fixture is
`.claude/skills/component-spec-audit/fixtures/direct-routing.json`.

## Published contract

Current corpus locks cover 60 inventory records, 154 selected sources, 622 facts,
175 coverage domains, 41 interactions, 60 pin maps, 196 pins and 11 integration
rules. The project validates 30 owner bundles, including 12 candidate records;
25 inventory owners are published. There are 34 package references. These counts
are review locks, not measurements or evidence of suitability.

The custom 99-field publication matrix preserves the earlier decisions and adds
only reviewed footprint/model preview publication. Eleven fields remain denied,
including raw evidence extracts, identity owner routes and binary content.
Publication selection separates 59 curated document selections from the one
honest `rec-c335982` document exception. Its distributor identity stays visible
with distributor authority; no manufacturer PDF is invented. The retained
`document-verification.json` records its dated source audit, mirrors and
referer-gated retrieval history. It is provenance, not a claim of a new live URL
check.

The package projects claims without rewriting them. A source link, generated
preview, complete evidence contract or clean site check does not establish
physical fit, measured performance, assembly state or hardware sign-off. Keep
`NEEDS BENCH`, `UNSOURCED`, `OPEN` coverage and explicit refusal reasons visible.

## Package and patch provenance

The root workspace installs `@takazudo/zudo-circuit-doc` 0.1.0 and
`@takazudo/zudo-doc` 5.27.0 from one root lockfile. Each package has its own
temporary pnpm patch in `patches/`; root and `doc/` resolve those same patched
installed modules. The circuit patch edits the shipped npm package, not a copied
source checkout; `pnpm test:compatibility` checks installed behavior and the
declaration consumer. The scaffold patch is limited to heading extraction parity
and carries its own removal tracker.

Patch groups bridge the project's existing contracts: configured board/spec
bindings and placement DNP ([circuit-doc #103](https://github.com/Takazudo/zudo-circuit-doc/issues/103)); candidate ownership and evidence partition
([#104](https://github.com/Takazudo/zudo-circuit-doc/issues/104)); independent
document, footprint and model resolution ([#105](https://github.com/Takazudo/zudo-circuit-doc/issues/105)); nullable denied owner fields and canary harvesting
([#106](https://github.com/Takazudo/zudo-circuit-doc/issues/106)); and safe
artifact scanning of published footprint hashes and generated output
([#107](https://github.com/Takazudo/zudo-circuit-doc/issues/107)). The narrow
generic asset-viewer exclusion is project host configuration, not a scanner
exception. Browser launcher scheduling and responsive reference layout remain
covered by project regressions while their upstream work proceeds
([#108](https://github.com/Takazudo/zudo-circuit-doc/issues/108),
[#109](https://github.com/Takazudo/zudo-circuit-doc/issues/109)). Dialog
accessibility follows the package's media-label contract and is checked by the
project browser smoke ([#110](https://github.com/Takazudo/zudo-circuit-doc/issues/110));
it is not a separate patch hunk. The scaffold patch aligns built heading IDs
with the reviewed native extractor behavior
([zudo-doc #4428](https://github.com/zudolab/zudo-doc/issues/4428)). The upstream
removal trackers are [zudo-pd #210](https://github.com/Takazudo/zudo-pd/issues/210)
for the circuit package patch and [zudo-pd #211](https://github.com/Takazudo/zudo-pd/issues/211)
for the scaffold patch. See [`patches/README.md`](../patches/README.md) for the
patch map.

The package's current generic view model is version 2. The renderer owns the
`zcd-*` components and stylesheet; the host registers
`circuitDocMdxExtras` in `doc/src/chrome-bindings.tsx` and imports the package
stylesheet from `doc/src/styles/global.css`. The project retains the 12-record
browser smoke because its named cases include the c335982 document gap and the
illustrative inductor model note that scaffold auto-selection cannot guarantee.

## Commands and gates

Run these from the repository root:

| Command | Purpose |
| --- | --- |
| `pnpm circuit:check` | Strict project validator and forward checks, followed by package validation |
| `pnpm circuit:generate` | Generate pages and preflight report from the installed package |
| `pnpm check` | Generated-output, preview/model parity, CAD pairs and host type checks |
| `pnpm build` | Strict project preparation, selected model publication, generation and static site build |
| `pnpm check:site` | Built-reference, publication/leak, strict link, authored-fragment and source-warning checks |
| `pnpm circuit:check-generated` | Re-run project preparation twice; catch drift, untracked output, deletion and non-idempotence |
| `pnpm test:circuit` | Project corpus, evidence, publication, workflow, link and package regressions |
| `pnpm test:compatibility` | Installed-package CLI, mutation regressions and TypeScript declaration consumer |
| `pnpm b4push` | Complete heavy local gate behind one outer `heavy-guard.sh` call |
| `pnpm test:model-viewer:browser` | Separate project browser gate over 12 representatives × two widths × two themes |

PR and production workflows install from the frozen root lock. They retain
`--intent-to-add` drift checks for generated pages, preflight and previews so
new or deleted files are visible. The second preparation proves idempotency.
Production deployment remains secret/domain guarded; the PR workflow retains its
preview alias. Local builds never deploy.

The full b4push command uses the machine-wide heavy guard once around all local
steps. Browser runs use both guards, for example:

```sh
bash "$HOME/.codex/scripts/heavy-guard.sh" -- bash "$HOME/.claude/scripts/playwright-guard.sh" --wait 300 -- pnpm test:model-viewer:browser
```

Exit 75 from the heavy guard means contention and no suite result. Read its
`verdict=` line first, retry `ENV_SUSPECT` once, and defer a persistent
environmental failure. Browser contention also exits 75 and must be retried
through the guard. Exit 4 for missing Chrome is `not run`, not a pass, and does
not satisfy mandatory browser acceptance.

## Historical path references

No active imports, production callers, CI commands or tests load code from the
retired `doc/component-docs/` directory. The remaining literal mentions are
historical or package compatibility provenance:

- `doc/src/content/docs/inbox/wave-7-3d-model-coverage.md` retains its original
  stable historical account of the model work.
- `circuit/tests/runtime.test.mjs` verifies that the installed package still
  accepts the old generated marker during safe ownership takeover.
- `circuit/tests/workflow-contract.test.ts` uses negative assertions to keep
  retired `doc/` command aliases out of the host manifest.
- `patches/README.md`, `doc/SCAFFOLD.md` and this architecture record the
  migration and imported-package provenance.

These references do not call or import the retired implementation. Keep archived
pages and their established URLs intact.

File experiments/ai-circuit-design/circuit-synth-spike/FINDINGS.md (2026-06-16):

# circuit-synth spike — FINDINGS

**Issue:** #75 (Approach B of epic #68 — "does the AI → schematic handoff actually work?")
**Sheet modeled:** `linear-regulation` (the three LDO output stages).
**Date:** 2026-06-17 · **Host:** macOS arm64 · **KiCad:** 10.0.0 · **python3:** 3.14.4

> **Verdict in one line:** circuit-synth **works end-to-end on Python 3.14** and
> produces a **structurally valid, KiCad-v10-parseable hierarchical project** —
> but the output has **no drawn wires** (connectivity is 100% hierarchical-label
> stubs) and an **older file-format token (v9)**, so for this repo it is a
> **net-correctness generator, not a drop-in schematic**. Useful as a
> connectivity/netlist authoring aid; **not** worth adopting to replace
> hand-drawing these ~27 parts.

---

## 1. Did install work? (on py3.14)

**Yes — clean install on Python 3.14.4, first try, no rabbit-hole.**

- Only `python3.14` was on PATH (no 3.11/3.12/3.13). The issue warned 3.14 might
  be unsupported, but `pip install circuit-synth` into a fresh venv **succeeded**:
  `circuit-synth 0.12.1` + `kicad-sch-api 0.5.6` + ~120 deps.
- Every dependency (numpy 2.4.6, scipy 1.17.1, lxml 6.1.1, matplotlib, fastmcp,
  openai, pydantic, sexpdata, …) shipped a **cp314 or pure-python wheel**, so
  **nothing compiled from source**. Install took ~1 minute. No pyenv, no
  Homebrew Python, no compile. Timebox never threatened.
- venv lives in repo-root `__inbox/cs-venv` (gitignored) — never committed.

## 2. Did it generate a valid `.kicad_sch`? (kicad-cli parsed it?)

**Yes.** `generate_kicad_project()` returned without raising and wrote a full
**hierarchical** project:

| File | Role |
|---|---|
| `linear_regulation.kicad_sch` | root sheet (3 sub-sheet refs) |
| `pos_12v_stage.kicad_sch` | U6 L7812 stage — 9 parts |
| `pos_5v_stage.kicad_sch` | U7 L7805 stage — 9 parts |
| `neg_12v_stage.kicad_sch` | U8 7912 stage — 9 parts |
| `linear_regulation.net` / `.json` / `.kicad_pro` | netlist / IR / project |

Headless validation (no GUI), **`kicad-cli` v10**:

```
kicad-cli sch export netlist --output … linear_regulation.kicad_sch   → exit 0
kicad-cli sch export netlist --output … pos_12v_stage.kicad_sch        → parsed
   unique refs: C1 C2 C3 C4 D1 F1 LED1 R1 U6   (the 9-part +12V stage)
```

KiCad v10 read the circuit-synth s-expressions cleanly. (One cosmetic
`Fontconfig error` line on stderr — does not affect the parse; exit 0.)

> One caveat: `kicad-cli sch export netlist` on the **root** sheet emitted an
> empty component list (it did not auto-descend the hierarchy in this invocation);
> exporting each **sub-sheet** directly yields the full 9-part netlist. So
> "valid" = each sheet parses and the parts/nets are correct; full-project
> netlist flattening would be done inside Eeschema, which we deliberately did not open.

## 3. File-format version — compatible with the repo's KiCad v10?

- **Generated:** `(version 20250114)`, `(generator "circuit_synth")` — a
  **KiCad v9-era** token (circuit-synth targets v8/v9).
- **Repo production:** `(version 20260306)`, `(generator_version "10.0")` — **v10**.

There **is a version gap (v9 → v10)**, but it is **forward-compatible on read**:
KiCad v10 / `kicad-cli` v10 parsed the v9-token files without error. KiCad
silently upgrades older formats on open. So you *can* import circuit-synth output
into this v10 project; it would be re-saved in the v10 format the moment Eeschema
touches it. No GUI was opened to confirm the re-save (per guardrails) — the
compatibility claim rests on the clean `kicad-cli` v10 parse, not a GUI open.

## 4. How good is the auto-placement?

**Mechanically valid, logically poor.** From the s-expr coordinates + the
generator's own log:

- circuit-synth ran a **"TEXT-FLOW PLACEMENT"** pass: it sorts parts largest-first
  and lays them out in a **left-to-right row** ("All components fit on A4"). In the
  +12V sheet every symbol sits at y ≈ 25–36 mm with x marching 38 → 262 mm.
- **There are ZERO drawn wires and ZERO junctions.** Connectivity is expressed
  **entirely through 22 `hierarchical_label` stubs per sheet** — one attached at
  each pin — *including auto-promoted internal nets* (`U6_OUT_LOCAL`, `U6_LED`).
  `grep -c '(wire'` = 0, `'(label'` = 0, `'(hierarchical_label'` = 22.
- Result: each sheet is a **flat row of symbols surrounded by net-name labels** —
  a "label rats-nest." It is netlist-correct but conveys **no signal flow**:
  no IN→reg→OUT left-to-right story, no GND rail, no grouped decoupling.
  A human opening it learns the connections only by reading label text, not by
  following lines.

(Side note: it also promotes every internal net I named — `U6_OUT_LOCAL` — to a
visible hierarchical label, which clutters the sheet further. Naming internal
nets in the Python is a footgun for the visual output.)

## 5. Tidy-up time vs. hand-drawing ~27 parts

The three stages are **27 parts total** (9 × 3), nearly identical topology.

- **Hand-drawing from scratch in Eeschema:** these are textbook LDO stages and
  highly repeatable (draw one, copy ×3, swap values/symbols). Estimate
  **~1.5–3 h** for a tidy, readable sheet by someone who knows the parts.
- **Tidy-up of the circuit-synth output to repo quality:** because there are **no
  wires at all**, "tidy-up" means **drawing essentially all the wiring by hand**,
  deleting/hiding the auto-promoted internal labels, re-laying the row into a
  signal-flow layout, and swapping the generic `Regulator_Linear:*` / `Device:*`
  symbols for the repo's real `zudo-pd:` library parts (correct footprints,
  LCSC part numbers, pin maps). That is **roughly the same effort as hand-drawing
  (~2–3 h), plus the re-symbol/footprint chore** — so **no net time saving** on
  the schematic, and the placement/wiring (the slow part) isn't actually done for you.

  What you *do* get for free is a **correct netlist / connectivity spec** — which
  has value as a checklist or for an ERC cross-check, but not as a finished drawing.

## 6. Verdict for this repo

**Do not adopt circuit-synth to author/replace these schematics.**

- Install + generation + headless validation all work on the current toolchain
  (py3.14, KiCad v10) — the *pipeline* is real and low-friction.
- Output is electrically correct and v10-parseable; good as a **netlist /
  connectivity generator** or an ERC sanity reference.
- The drawing itself is unusable as-is: **no wires**, internal nets leaked as
  labels, flat text-flow placement, generic symbols (not the repo's `zudo-pd:`
  library with the real LCSC parts/footprints), and an older format token.
- For ~27 highly-repetitive LDO parts, the human still draws all the wiring and
  re-symbols everything, so there is **no time win** over hand-drawing — and the
  result would be lower quality than the existing hand-drawn sheet.

**Where it *could* pay off** (not this task): large, irregular, copy-pasta-heavy
nets where getting the *connectivity* right by hand is the bottleneck and the
visual layout matters less — or as a programmatic ERC/netlist double-check against
a hand-drawn sheet. For zudo-pd's small, tidy, custom-symbol boards, hand-drawing
in Eeschema remains the better path.

---

### Reproduce

```bash
python3 -m venv __inbox/cs-venv                       # repo-root, gitignored
__inbox/cs-venv/bin/pip install circuit-synth
__inbox/cs-venv/bin/python experiments/ai-circuit-design/circuit-synth-spike/linear_regulation.py
/Applications/KiCad/KiCad.app/Contents/MacOS/kicad-cli sch export netlist \
  --output /tmp/n.net \
  experiments/ai-circuit-design/circuit-synth-spike/generated_linear_regulation/pos_12v_stage.kicad_sch
```

See `command-log.txt` for the exact commands and their output.

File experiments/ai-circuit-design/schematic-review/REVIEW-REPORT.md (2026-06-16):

# PD Schematic Review Report

**Skill:** `pd-schematic-review` (Approach C, sub-issue #76 of epic #68)
**Board:** zudo-pd USB-PD modular-synth power supply, version 0.4.0 (4th JLCPCB order)
**Date:** 2026-06-17
**Method:** read-only KiCad netlist export → pin→net map → datasheet-checklist review.
**Inputs:**

- `zudo-pd.kicad_sch` (root) → exported with KiCad CLI 10.0.0:
  `kicad-cli sch export netlist --format kicadxml -o __inbox/zudo-pd-netlist.xml zudo-pd.kicad_sch`
  (also `--format kicadsexpr -o __inbox/zudo-pd-netlist.net`). Exports kept in `__inbox/`
  (gitignored), not committed.
- 87 components parsed; pin→net topology read from the **actual nets**, not symbol positions.

> **READ THIS FIRST — findings are leads, not verdicts.** Every item below is a *lead to
> verify against the datasheet*, never ground truth. This is a static net-topology pass: it
> can confirm what connects to what and recompute divider math, but it cannot measure
> voltages, simulate loops, judge thermals, or check the PCB. Sources are cited per finding so
> you can confirm each one. See "What this pass can and cannot catch" at the end.

---

## Part map (from the export — confirm each run, the BOM can change)

| Ref | Part | Role | Source for review |
| --- | --- | --- | --- |
| U1 | STUSB4500QTR | USB-PD sink controller, negotiates 15 V | repo docs + ST DS12499 (web) |
| Q1 | AO3401A | P-ch VBUS load switch | `components/ao3401a.md` |
| U2 | LM2596S-ADJ | DC-DC +15 V → +13.5 V (for +12 V rail) | `datasheets/LM2596S-datasheet.pdf` + `components/lm2596s-adj.mdx` |
| U3 | LM2596S-ADJ | DC-DC +15 V → +7.5 V (for +5 V rail) | same |
| U4 | LM2596S-ADJ | DC-DC **inverting** → −13.5 V (for −12 V rail) | same |
| U6 | L7812CD2T | LDO +13.5 V → +12 V | `datasheets/L7812CD2T-datasheet.pdf` + `components/l7812cv.md` |
| U7 | L7805ABD2T | LDO +7.5 V → +5 V | `datasheets/L7805ABD2T-datasheet.pdf` + `components/l7805abd2t.md` |
| U8 | CJ7912 | LDO −13.5 V → −12 V | `datasheets/CJ7912-datasheet.pdf` + `components/cj7912.md` |

> **Designator note:** the issue text calls the STUSB4500 "U0"; the actual netlist uses **U1**.
> Reviewed as U1.

---

## USB-PD stage — STUSB4500 (U1)

**Datasheet source for this stage:** primary = repo docs
`doc/src/content/docs/inbox/stusb4500-pinout.md`, `doc/src/content/docs/inbox/v3-pd-failure-diagnosis.md`,
`doc/src/content/docs/components/stusb4500.md` (these distill the ST datasheet and the v3 root
cause). External = **ST DS12499** — the direct PDF fetch timed out, but a web search returned
ST's authoritative pin-18 description (below). **There is no local STUSB4500 PDF**, so every
electrical *value* below is flagged "verify against ST DS12499."

### F-1 — VBUS sense path (the v3 fix) — CONFIRMED PRESENT ✅ (blocker-class check)

**Net evidence (from export):**

```
VBUS_VS_DISCH net = { U1.18 (VBUS_VS_DISCH), R14.2, TP6.1 }
VBUS_IN net       = { U1.24 (VDD), Q1.2 (S), R14.1, R11.2, C1.2, C2.2, D4.5, J1.A9/B9, J3.4 }
  ⇒ U1.18 ── R14 (470 Ω) ── VBUS_IN     (NO GND on the pin-18 net)
```

The pin-18 net reaches **VBUS_IN through R14 (470 Ω)** and touches a test point (TP6); it does
**not** touch GND anywhere. This is exactly the 0.4.0 fix for the v3 blocker (v3 had
`pin 18 → R14 → GND`, so the chip never saw VBUS and never asserted the sink path).

- **Lead to verify:** ST DS12499 confirms VBUS_VS_DISCH is the VBUS-monitoring input that
  checks VBUS is in a valid window before enabling the power path via VBUS_EN_SNK, and requires
  a **current-limiting series resistor** (max discharge current 50 mA). 470 Ω is the value the
  repo's v1-debug intent and `stusb4500-pinout.md` specify. **Verify against ST DS12499 Fig. 10
  whether a bare series R or a divider is the recommended topology**, and that 470 Ω keeps
  discharge ≤ 50 mA (15 V / 470 Ω ≈ 32 mA — within spec, OK).
- **Source:** net export (ground truth for topology) + `stusb4500-pinout.md` (pin 18 row) +
  `v3-pd-failure-diagnosis.md` (root-cause + fix) + ST DS12499 via WebSearch
  ("STUSB4500 ... VBUS monitoring block supervises VBUS ... from VBUS_VS_DISCH input pin ...
  current limiting serial resistor recommended, max discharge 50 mA").
- **Severity:** OK-confirmed. This was the whole v3 story; it is now correct in the schematic.

### F-2 — VBUS_EN_SNK → Q1 load switch — CONFIRMED ✅

**Net evidence:** `U1.16 (VBUS_EN_SNK) → VBEN → R12.1`; `R12.2 → Q1.1 (G)`; `R11 (100 k) from
VBUS_IN to Q1 gate`; `Q1.2 (S) → VBUS_IN`, `Q1.3 (D) → "+15V -> +13.5V gen"` (the VBUS_OUT
rail, oddly net-named). AO3401A is a P-channel MOSFET: source at VBUS_IN, gate pulled up to
VBUS_IN by R11 (off by default), pulled low by the chip via VBEN/R12 to turn on. Correct
high-side load-switch topology.

- **Lead to verify:** R12 gate series + R11 pull-up values vs AO3401A gate charge / turn-on
  time — fine for a slow enable. **Source:** export + `components/ao3401a.md`. **Severity:** OK.

### F-3 — VDD supply + decoupling — CONFIRMED ✅

`U1.24 (VDD) → VBUS_IN`, decoupled by **C1 (10 µF) + C2 (100 nF)** on that net.

- **Lead to verify:** VBUS can be 15 V; STUSB4500 VDD operating range is ~4.1–22 V per repo
  doc (`components/stusb4500.md`: "VDD 4.1–22 V"). 15 V is comfortably inside. **Verify the
  22 V abs-max against ST DS12499** (repo doc value, not from a local PDF). C1/C2 voltage
  ratings (25 V) exceed 15 V. **Source:** export + `components/stusb4500.md`. **Severity:** OK.

### F-4 — VREG_2V7 / VREG_1V2 / VSYS / EP — CONFIRMED ✅

`U1.23 (VREG_2V7) → C30 (1 µF) decap`; `U1.21 (VREG_1V2) → C34 (1 µF) decap`;
`U1.22 (VSYS) → GND`; `U1.25 (EP) → GND`; `U1.10 (GND) → GND`.

- **Lead to verify:** the two internal-regulator outputs each have a 1 µF decap (repo doc
  recommends this). VSYS-to-GND is correct for a VBUS-only (non-battery) board. EP grounded.
  **Verify the 1 µF VREG decap values against ST DS12499.** **Source:** export +
  `stusb4500-pinout.md` + `components/stusb4500.md`. **Severity:** OK.

### F-5 — CC pins, ADDR straps, RESET — CONFIRMED ✅

`U1.2 (CC1)` and `U1.4 (CC2)` each have a 5.1 kΩ Rd to GND (R17, R18) — correct sink Rd.
`U1.1 (CC1DB)`/`U1.5 (CC2DB)` to GND via 0 Ω (R19/R20). `U1.12 (ADDR0)`+`U1.13 (ADDR1)` → GND
⇒ I²C addr 0x28. `U1.6 (RESET) → GND` (held low = run). `U1.7/8 (SCL/SDA)` to pull-ups.

- **Lead to verify:** 5.1 kΩ Rd is the USB-C spec value for a sink advertising default current;
  the actual current is set by the NVM PDO (15 V). **Source:** export + `stusb4500-pinout.md`
  (CC rows) + `v3-pd-failure-diagnosis.md` (addr 0x28 matches programmer). **Severity:** OK.

### F-6 — DISCH (pin 9) — VERIFY ⚠️ (minor)

`U1.9 (DISCH) → Net-(U1-DISCH) → R13 (470 Ω) → "+15V -> +13.5V gen"` (VBUS_OUT side).

- **Lead to verify:** DISCH is a discharge-path pin distinct from VBUS_VS_DISCH. `components/
  stusb4500.md` documents `DISCH → R13 (470 Ω) → VBUS_OUT` as intended. `v3-pd-failure-diagnosis.md`
  marks pin 9 "check (minor, not a blocker)." **Confirm against ST DS12499 whether DISCH should
  tie to the VBUS rail via R or be left to internal handling.** **Source:** export +
  `components/stusb4500.md`. **Severity:** verify (minor).

---

## DC-DC stage — LM2596S-ADJ (U2 / U3 / U4)

**Datasheet source:** `doc/public/datasheets/LM2596S-datasheet.pdf` +
`doc/src/content/docs/components/lm2596s-adj.mdx`. Vref = **1.23 V**; ON/OFF (pin 5):
**Low/Float = ON, High = shutdown**; Vin range 4.5–40 V (abs-max 45 V).

### F-7 — Feedback dividers recomputed — CONFIRMED ✅

`Vout = 1.23 V × (1 + Rtop/Rbottom)`, recomputed from the **actual** divider resistors in the
export:

| Rail | Top R (to Vout) | Bottom R (to GND ref) | Computed Vout | Target | Verdict |
| --- | --- | --- | --- | --- | --- |
| +13.5 V (U2) | R1 = 10 k | R2 = 1 k | 1.23·(1+10) = **13.53 V** | 13.5 V | ✅ |
| +7.5 V (U3) | R3 = 5.1 k | R4 = 1 k | 1.23·(1+5.1) = **7.50 V** | 7.5 V | ✅ |
| −13.5 V (U4) | R6 = 1 k (to −13.5 OUT) | R5 = 10 k (to GND) | inverting: see F-9 | −13.5 V | ✅ topology |

Net evidence: `U2.4 (FB) = {R1.1, R2.2}`, `R1.2 → +13.5 OUT`, `R2.1 → GND`. Same shape for U3.
C31/C32/C33 (22 nF) are FB-compensation caps in parallel with the top resistor.

- **Lead to verify:** the divider math matches the `lm2596s-adj.mdx` worked examples exactly
  (13.53 V, 7.50 V). **Source:** export + `lm2596s-adj.mdx`. **Severity:** OK-confirmed.

### F-8 — ON/OFF (enable) pins — CONFIRMED ✅

`U2.5 → GND`, `U3.5 → GND` (Low = ON, correct). `U4.5 → −13.5 V OUT` (U4's local "GND",
i.e. its enable is tied to its own reference = ON; see F-9).

- **Lead to verify:** LM2596 ON/OFF Low/Float = ON per `lm2596s-adj.mdx`. **Source:** export +
  `lm2596s-adj.mdx`. **Severity:** OK.

### F-9 — U4 is an INVERTING LM2596 (not a SEPIC / not a LM2586) — DOC DISCREPANCY ⚠️

**Net evidence:** `U4.3 (Gnd)`, `U4.5 (ON/OFF)`, `U4.6 (TAB)` **all tie to `−13.5 V OUT`**, and
`U4.1 (Vin) → +15 V gen`, `U4.2 (Output) → D3.K + L3.1`, `D3.2 (A) → −13.5 V OUT`,
`L3.2 → GND`. This is the **classic LM2596 inverting buck-boost** configuration: the
regulator's ground reference sits at the negative output, the catch diode points to the
negative rail, and the inductor returns to system GND.

- **Discrepancy to resolve:** the repo `CLAUDE.md` / architecture text describes the negative
  rail as "−15 V (LM2586SX-ADJ **inverted SEPIC**) → −13.5 V". The **actual schematic uses a
  third LM2596S-ADJ (U4) in an inverting topology**, not an LM2586 SEPIC. The
  `lm2596s-adj.mdx` doc's U4 section ("−15 V → −13.5 V, same as U2") also doesn't describe the
  inverting wiring explicitly. **Lead to verify:** confirm the input-voltage stress on an
  inverting LM2596 — in this topology the switch sees roughly `|Vin| + |Vout|` ≈ 15 + 13.5 ≈
  **28.5 V** across the part, well under the 40 V/45 V max but worth confirming against the
  LM2596 datasheet's inverting-application note and the inductor/diode current ratings for
  buck-boost (peak current is higher than a simple buck).
- **Source:** export (topology) + `LM2596S-datasheet.pdf` (inverting app note) vs repo
  `CLAUDE.md` text. **Severity:** verify — likely a stale doc, but the abs-max stress on an
  inverting converter is a real lead to check.

### F-10 — Catch diodes / inductors / input caps — CONFIRMED ✅ (values to verify under load)

D1/D2/D3 = SS34 (3 A/40 V Schottky); L1/L2/L3 = 100 µH; bulk input/output electrolytics
(C3/C4/C5/C7/C9/C11/C14/C20/C21/C24/C25, 100–470 µF) present on each rail.

- **Lead to verify:** SS34 3 A and L = 100 µH ratings vs the **peak** inductor current at each
  rail's load — buck-boost (U4) peak current is notably higher than buck. Recompute peak
  current and ripple against the LM2596 datasheet design equations. Confirm electrolytic
  voltage ratings exceed each rail (25 V parts on 13.5 V rails = OK; check the 16 V parts).
  **Source:** export + `LM2596S-datasheet.pdf` + `lm2596s-adj.mdx`. **Severity:** verify (this
  static pass cannot compute currents under load).

---

## Linear-regulator stage — LDOs (U6 / U7 / U8)

**Datasheet source:** local PDFs `L7812CD2T-`, `L7805ABD2T-`, `CJ7912-datasheet.pdf` + the
matching `components/*.md`. All three: ~2 V typical dropout, 1.5 A max, ±4 % output.

### F-11 — +12 V LDO (U6 L7812): DROPOUT MARGIN THIN — VERIFY ⚠️ (the flagged thin-rail case)

**Net evidence:** `U6.1 (IN) → +13.5 V OUT`, `U6.3 (OUT) → Net-(U6-OUT)`, `U6.4 → GND`.
Input bulk: C3/C20 (470 µF) + C14 (470 nF) + C17 on output side; output → PTC1 → +12 V rail.

- **Headroom:** `13.5 − 12 = 1.5 V` against a **~2 V typical dropout**. The local doc
  `components/l7812cv.md` itself flags this: **"⚠️ Marginal — operates near minimum dropout
  voltage,"** and recommends raising the DC-DC to 14.0 V for production.
- **Lead to verify:** dropout is current- and temperature-dependent; at 1.2 A and worst-case
  hot/low-line, 1.5 V may be insufficient → +12 V could droop / lose regulation. **Verify the
  dropout-vs-current curve in `L7812CD2T-datasheet.pdf`** at 1.2 A. Also note the DC-DC actually
  regulates to ~13.53 V (F-7), giving a hair more, but still under 2 V. **Source:**
  `components/l7812cv.md` (explicit ⚠️) + `L7812CD2T-datasheet.pdf`. **Severity:** marginal —
  the strongest "thin intermediate-rail margin" lead on the board.

### F-12 — +5 V LDO (U7 L7805): dropout OK ✅

**Net evidence:** `U7.1 (IN) → +7.5 V OUT`, `U7.2 → GND`, `U7.3 (OUT) → Net-(U7-OUT) → PTC2 →
+5 V rail`. Headroom `7.5 − 5 = 2.5 V` ≥ ~2 V dropout.

- **Lead to verify:** 2.5 V margin is comfortable at 0.5 A; `components/l7805abd2t.md` marks it
  "✅ Excellent." Confirm thermals: `P = (7.5−5)·0.5 = 1.25 W` (doc: Tj ≈ 69 °C). **Source:**
  `components/l7805abd2t.md` + `L7805ABD2T-datasheet.pdf`. **Severity:** OK.

### F-13 — −12 V LDO (U8 CJ7912): polarity + thin margin — VERIFY ⚠️

**Net evidence:** `U8.1 (GND) → GND`, `U8.2 (VIN) → −13.5 V OUT`, `U8.3 (OUT) → Net-(U8-OUT) →
PTC3 → −12 V rail`. Note the negative-regulator pinout (GND/IN/OUT = pins 1/2/3) differs from
the positive parts — the export confirms IN is on pin 2, OUT on pin 3, GND on pin 1, matching
`components/cj7912.md`.

- **Headroom:** `|−13.5| − |−12| = 1.5 V` against ~2 V dropout — **same marginal case as the
  +12 V rail (F-11)**, at 0.8 A.
- **Lead to verify:** (a) dropout-vs-current for CJ7912 at 0.8 A in `CJ7912-datasheet.pdf`;
  (b) **electrolytic polarity** on the negative rail — `components/cj7912.md` is explicit that
  C21 (input) and C22 (output) have their **negative terminal toward the −13.5 V / −12 V node
  and positive terminal to GND**. Verify the symbol polarity in the schematic matches (a flipped
  electrolytic on a negative rail is a classic failure). **Source:** export +
  `components/cj7912.md` + `CJ7912-datasheet.pdf`. **Severity:** marginal (dropout) + verify
  (polarity).

### F-14 — Output protection (PTC fuses + TVS) — CONFIRMED present ✅

Each LDO output passes through a PTC resettable fuse (PTC1/PTC2/PTC3) before the rail, and each
rail has a TVS (TVS1 SMAJ15A on +12, TVS2 SD05 on +5, TVS3 SMAJ15A on −12) and a status LED via
1 k series (R7/R8/R9).

- **Lead to verify:** PTC hold/trip currents vs each rail's rated load (1.2 / 0.5 / 0.8 A); TVS
  standoff voltage vs rail (SMAJ15A standoff 15 V is fine for a 12 V rail; SD05 for 5 V).
  **Source:** export + `components/ptc-12v.md`, `ptc-5v.md`, `ptc-12v-neg.md`, `smaj15a.md`,
  `sd05.md`. **Severity:** verify (ratings under fault).

---

## Summary of leads (by severity)

| # | Finding | Severity | Source |
| --- | --- | --- | --- |
| F-1 | VBUS_VS_DISCH (U1.18) ← R14 ← VBUS_IN — v3 fix present, no GND | OK ✅ | export + repo docs + ST DS12499 (web) |
| F-11 | +12 V LDO dropout only 1.5 V (< ~2 V typ) | **MARGINAL ⚠️** | `l7812cv.md` (explicit) + L7812 PDF |
| F-13 | −12 V LDO dropout 1.5 V + check electrolytic polarity | **MARGINAL/VERIFY ⚠️** | `cj7912.md` + CJ7912 PDF |
| F-9 | U4 is an inverting LM2596 (docs say LM2586 SEPIC) — abs-max stress ~28.5 V | VERIFY ⚠️ | export + LM2596 PDF vs CLAUDE.md |
| F-10 | Inductor/diode peak current under load (esp. buck-boost U4) | VERIFY ⚠️ | export + LM2596 PDF |
| F-6 | DISCH (U1.9) → R13 → VBUS_OUT — confirm intended | VERIFY (minor) | `stusb4500.md` + ST DS12499 |
| F-14 | PTC trip / TVS standoff vs rated load & fault | VERIFY | export + protection docs |
| F-2..F-5, F-7, F-8, F-12 | load switch, VDD decap, VREG decaps, CC/ADDR/RESET, FB math, EN pins, +5 V dropout | OK ✅ | export + cited docs |

**Top takeaways:**

1. **The v3 blocker is fixed (F-1).** A datasheet-aware net review of v3 would have caught the
   pin-18→GND bug — that is the standing safety net this skill provides.
2. **Two LDOs run at ~1.5 V dropout (F-11, F-13)** — the thin intermediate-rail margins the
   checklist targets. The repo doc already flags +12 V; raising the +13.5 V / −13.5 V DC-DC
   setpoints toward 14 V (per the doc's own recommendation) is the obvious mitigation. Verify
   the dropout-vs-current curves at the rated 1.2 A / 0.8 A.
3. **Doc-vs-schematic drift (F-9):** the negative rail is a third inverting LM2596, not an
   LM2586 SEPIC. Update the architecture docs and verify the inverting-mode abs-max stress.

---

## What this pass CAN and CANNOT catch

**Datasheet source for STUSB4500 — disclosure:** there is **no local STUSB4500 PDF**. STUSB4500
findings rest on repo docs (`stusb4500-pinout.md`, `components/stusb4500.md`,
`v3-pd-failure-diagnosis.md`) cross-checked against **ST DS12499** obtained via WebSearch (the
direct `st.com/.../stusb4500.pdf` fetch timed out). Treat every STUSB4500 *value* as
"verify against ST DS12499." Regulator/LM2596 findings rest on local PDFs in
`doc/public/datasheets/` + their `components/*.md`.

**CAN catch (static net topology):**

- Wrong-net / missing-connection errors — e.g. the v3 pin-18→GND bug (a pure topology fault).
- Missing components on a net (decap absent, divider half-missing, EN floating).
- Feedback-divider math from the *actual* resistors (recomputed, not trusted).
- Pin-function vs net mismatches (the export carries `pinfunction`, so IN/OUT/GND/FB/EN are
  checked by function, not by symbol position — which is what produced false v3 findings).
- Polarity *by pin assignment* (which net is IN vs OUT vs GND on a negative regulator).
- Nominal dropout headroom (Vin − Vout vs datasheet typ) as a flag.

**CANNOT catch (out of scope for this pass — require bench / sim / PCB review):**

- Actual voltages/currents **under load** — dropout-vs-current, regulation droop, ripple,
  inductor peak/saturation, PTC trip behavior. (F-10, F-11, F-13, F-14 are flags, not proof.)
- **Thermals** — junction temperature, copper-area heatsinking, derating.
- **Loop stability / transient response** — compensation, ESR-dependent stability of the LDOs
  and DC-DC loops.
- **Layout / parasitics** — `*.kicad_pcb` is not reviewed here (read-only, untouched); trace
  width, current loops, ground bounce, decap placement.
- **Footprint ↔ symbol pin-number mismatch** — the netlist uses symbol pins; a wrong footprint
  pinout (the kind of error that bit a prior order) is invisible to a schematic-netlist pass.
- **Electrolytic polarity in the physical part** — flagged by net (F-13) but the actual symbol
  +/- orientation and the footprint polarity mark must be eyeballed in KiCad.
- **NVM / firmware** — the STUSB4500 PDO programming (15 V/3 A) is data, not schematic.

---

*Generated by the `pd-schematic-review` skill. Re-run after any schematic change. Raw exports:
`__inbox/zudo-pd-netlist.xml` / `.net` (gitignored).*

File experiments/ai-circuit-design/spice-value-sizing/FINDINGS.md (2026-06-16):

# SPICE value-sizing loop — LM2596-ADJ feedback divider

**Approach D** of the AI-circuit-design experiment (epic #68, sub-issue #77).
Goal: demonstrate a **repeatable SPICE-in-the-loop value-sizing workflow** on a
real part of the `zudo-pd` design and produce a worked result.

## Scope (read this first)

This is a **value-sizing demo**: a DC operating-point / resistor-divider
calculation that verifies the **feedback divider selects the intended rail
voltage**.

It is **NOT** a full buck-converter simulation. There is **no** modelling of:

- switching transient / start-up behaviour,
- control-loop stability (phase/gain margin, compensation),
- output ripple or noise,
- inductor / catch-diode / Cout dynamics.

Those belong to a separate transient/AC study (see "How this extends" below).
The value-sizing question — _"do R3/R4 set the rail I want?"_ — is exactly the
kind of parameter tuning the research flagged as the 14% -> 90% lever, and it is
what this deck answers.

## The part under study

From the real schematic (`dc-dc-conversion.kicad_sch`, read-only):

- **U = LM2596S-ADJ** adjustable buck regulator.
- Feedback divider: **R3 = 5.1 kOhm** (top, Vout->FB), **R4 = 1.0 kOhm**
  (bottom, FB->GND).
- The LM2596-ADJ servos its output until **FB = Vref ~= 1.23 V** (datasheet typ).
- Governing equation: **Vout = Vref * (1 + R3/R4)**.

With the as-designed values this is the **+7.5 V intermediate rail** that feeds
the LM7805 -> +5 V output (4-stage architecture in the project README).

## The loop (generate -> simulate -> read-back -> adjust -> re-check)

This is the repeatable procedure. It is deliberately mechanical so an agent (or
a human) can run it without re-deriving algebra each time.

1. **Target.** State the rail you want, e.g. `Vout_target = 7.5 V`.
2. **Generate (compute the divider).** Hold one resistor (here R4 = 1 kOhm, a
   convenient round value) and solve for the other:
   `R3 = R4 * (Vout_target / Vref - 1)`.
   For 7.5 V -> R3 = 1k * (7.5/1.23 - 1) = **5.28 k** -> nearest E24 = **5.1 k**.
3. **Encode in the deck.** Put the chosen R3/R4/Vref into `lm2596-divider.cir`
   as `.param`s. The deck has two cross-checks:
   - **(A) forward** — apply `Vout_target`, confirm the FB node lands on Vref
     (proves the divider ratio is right);
   - **(B) loop-closed** — model the regulator's error amp as a **high-gain
     behavioural source** that drives Vout until FB = Vref, feeding the **real**
     divider, and **read back the Vout the divider demands** (proves which rail
     the part will actually servo to). Vout must be loop-driven, not pinned: an
     ideal FB pin would float Vout (KCL forces Vout = FB ≈ Vref), so the
     high-gain feedback is the correct minimal model.
4. **Simulate.** `ngspice -b lm2596-divider.cir` runs the `.op` and prints
   `v(vout_*)`, `v(fb_*)`, and the ratio.
5. **Read back.** Compare the printed `v(vout_b)` to the target.
6. **Adjust & re-check.** If it's off, bump R3 to the next E24 value and re-run
   — or use `lm2596-divider-sweep.cir`, which sweeps R3 and prints the resulting
   rail for a range of E24 values in one shot, so you pick the closest fit
   directly from the table.

The deck _is_ the artifact of the loop: changing the target means editing two
`.param` lines and re-running, not rewriting equations.

## Worked result

Simulator status: **no command-line SPICE was available** on this host (details
below), so the read-back values are **hand-computed** and the deck is left
**ready to run**. The algebra is the same arithmetic the `.op` performs, so the
numbers below are exactly what the deck would print.

### As-designed +7.5 V rail (the loop's "verify" pass)

| Quantity | Value |
| --- | --- |
| R3 (top), R4 (bottom) | 5.1 kOhm, 1.0 kOhm |
| **Vout = 1.23 * (1 + 5.1/1)** | **7.503 V** (target 7.5 V) |
| FB node at Vout = 7.5 V | 7.5 * 1/(5.1+1) = 1.2295 V ~= Vref |
| ratio v(vout)/Vref | 6.1 = (1 + 5.1/1) |

Error vs target: **+0.04 %** — the as-designed divider is correct.

### Loop "adjust & re-check" pass — retarget to +13.5 V

To show the loop doing real work, retarget the same topology to **+13.5 V** (the
voltage the +12 V rail's pre-regulator would need), holding R4 = 1 kOhm:

- Solve: R3 = 1k * (13.5/1.23 - 1) = **9.976 k**.
- Candidates read back from the sweep deck:

| R3 (E24)  | Vout = 1.23 * (1 + R3/1) | error vs 13.5 V |
| --- | --- | --- |
| 9.1 kOhm  | 12.423 V | -7.98 % |
| **10 kOhm** | **13.530 V** | **+0.22 %** |
| 11 kOhm | 14.760 V | +9.33 % |

-> pick **R3 = 10 kOhm**. That is the full loop: target -> compute -> read back
-> the first E24 guess (9.976k ~= 10k) is confirmed within 0.22 %.

## Simulator availability (honest notes)

- `ngspice` is **not on PATH**.
- KiCad is installed, but its bundle ships ngspice **only as a shared library**
  (`libngspice.0.dylib`) plus code-model `.cm` files — usable from KiCad's GUI
  simulator, but there is **no command-line `ngspice` executable** and
  `kicad-cli` has **no batch sim subcommand**.
- One non-interactive, timeout-limited install was attempted
  (`gtimeout 180 brew install ngspice`); it was **killed by the 180 s timeout
  mid-download** and, per the run guardrails, was **not retried**.

To run the decks for real:

```sh
brew install ngspice            # one-time, ~1-2 min
ngspice -b lm2596-divider.cir         # .op: prints vout/fb/ratio
ngspice -b lm2596-divider-sweep.cir   # R3 sweep -> rail-vs-R3 table
```

The expected output is documented in `command-log.txt` and matches the
hand-computed table above (a documented blocker with the concrete deck + worked
result intact, as the issue permits).

## How this extends (beyond value-sizing)

The same generate -> simulate -> read-back -> adjust loop scales up once a real
simulator is in place, by swapping the analysis (not the methodology):

- **Ripple / regulation on the rails** — replace the divider-only error-amp
  model with a buck behavioural model (or the actual LM2596 SPICE subckt + L, catch diode, Cout),
  run a `.tran`, and read back peak-to-peak output ripple; adjust **Cout / L**
  and re-check against the `<1 mVp-p` target. Value-sizing the **output cap**
  instead of the divider, same loop.
- **Line/load regulation** — `.dc` sweep of Vin (or a load step in `.tran`) and
  read back delta-Vout; size the feedforward / compensation.
- **Linear post-regulator headroom** — `.op` across the LM7805/LM7812/LM7912
  with worst-case Vin to confirm dropout margin; size the pre-reg rail.

In every case the loop is identical; only the measured node and the knob change.

## Files

- `lm2596-divider.cir` — `.op` deck: forward + loop-closed divider check.
- `lm2596-divider-sweep.cir` — R3 sweep deck (the "adjust & re-check" step).
- `command-log.txt` — exact discovery/install commands + expected sim output.
- `FINDINGS.md` — this document.

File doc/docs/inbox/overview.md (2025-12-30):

---
sidebar_position: 2
---

# Project Overview

A compact power supply module that provides ±12V/+5V power for modular synthesizers using USB-C PD 15V as input.

## Design Goals

### Output Specifications

- **+12V**: 1200mA (design margin 1.2A)
- **-12V**: 800mA (design margin 1.0A)
- **+5V**: 500mA (design margin 1.2A)

### Input

- **USB-C PD 15V 3A** (max 45W)

### Performance Characteristics

- **Efficiency**: Approx. 75-80% (overall)
- **Ripple Noise**: &lt;1mVp-p (final output)
- **Regulation**: ±1% (line & load variation)
- **Response Speed**: Excellent (due to linear stage)
- **Safety Margin**: 150%+ across all circuits

## Architecture

### 4-Stage Design

This project adopts a 4-stage architecture to achieve efficient power conversion while minimizing noise.

```
USB-C 15V ──┬─→ +13.5V (DC-DC) ──→ +12V (LDO) ──→ +12V OUT
            │
            ├─→ +7.5V  (DC-DC) ──→ +5V  (LDO) ──→ +5V OUT
            │
            └─→ -15V (Inverter) ──→ -13.5V (DC-DC) ──→ -12V (LDO) ──→ -12V OUT
```

#### Stage 1: USB-PD Power Delivery

- **CH224D IC**: USB-C PD protocol negotiation
- **15V Output**: Obtains stable 15V through PD negotiation
- **Status Display**: LED1 (red) indicates power status

#### Stage 2: DC-DC Converter

- **LM2596S-ADJ × 3**: High-efficiency buck converter
  - +15V → +13.5V (for +12V rail)
  - +15V → +7.5V (for +5V rail)
  - -15V → -13.5V (for -12V rail)
- **ICL7660**: Voltage inverter IC (+15V → -15V)
- **Efficiency**: Approx. 85-90%

#### Stage 3: Linear Regulator

- **LM7812**: +13.5V → +12V (noise reduction)
- **LM7805**: +7.5V → +5V (noise reduction)
- **LM7912**: -13.5V → -12V (noise reduction)
- **Ripple**: &lt;1mVp-p

#### Stage 4: Protection Circuit (Beginner-Friendly, 2-Level Protection)

- **PTC Resettable Fuse**: Auto-recovery during overload
- **SMD Fuse**: Backup protection during short circuit
- **TVS Diode**: Surge voltage protection
- **LED Indicator**: Status display for each voltage line

## Design Features

### 1. All Parts Available from JLCPCB

- **Extensive Basic Parts Usage**: No additional costs
- **Rich Inventory**: From minimum 2,763 to maximum 21 million units
- **Stable Sourcing**: Stable supply chain

### 2. High-Performance Design

- **2-Stage Filter**: DC-DC + Linear for low noise
- **Sufficient Margin**: 150%+ safety margin across all circuits
- **Modular Synth Optimized**: Low noise, high stability

### 3. Beginner-Friendly Protection Circuit

- **PTC Auto-Recovery**: Recovers in 30 seconds even with excessive module connections
- **Staged Protection**: Overload → PTC, Short circuit → Fuse
- **Visual Feedback**: Instantly recognize overload by LED extinguishing
- **No Repair Needed**: Users can resolve normal overloads themselves

### 4. Manufacturability

- **All SMD Components**: Compatible with automated assembly
- **TO-220 Package**: Easy heatsink mounting
- **Separated Design**: Physical separation of DC-DC and linear stages

## Protection Circuit Operation

### Normal Operation

- PTC has zero resistance
- LED lights brightly ✅

### Overload (1.2-2A)

- PTC becomes high resistance
- LED extinguishes
- Reduce modules and wait 30 seconds
- Auto-recovery 🔄

### Short Circuit (>2A)

- Fuse blows
- Repair required ❌

## Next Steps

1. **Finalize Unsearched Components**:
   - PTC Resettable Fuse (1.1A, 0.75A, 0.9A @ 16V)
   - 2A SMD Fuse (+12V backup)

2. **PCB Design**:
   - 4-layer PCB (power plane separation)
   - Thermal via placement
   - EMI countermeasure layout

3. **Prototype Manufacturing**:
   - Use JLCPCB SMT service
   - Initial lot of approximately 10 units

4. **Performance Verification**:
   - Ripple noise measurement
   - Load response characteristics
   - Thermal design verification

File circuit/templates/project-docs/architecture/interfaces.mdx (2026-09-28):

---
title: "Interfaces and connections"
description: "Explicit boundaries between circuit blocks, external devices, firmware, and mechanical parts."
sidebar_position: 20
---

This page explains interface contracts for the [architecture](./overview.mdx). Populate only interfaces that exist or are actively proposed. It is not a generated pin catalog.

## Interface inventory

| Interface ID | Endpoint A | Endpoint B | Purpose | Intended representation | Current status |
|---|---|---|---|---|---|
| Not entered | Not entered | Not entered | Not entered | Schematic, cable drawing, firmware API, or mechanical drawing | Unspecified |

Identify whether each connection is internal, external, removable, accessible during service, or part of a test fixture. State its direction from a named endpoint so “input” and “output” are unambiguous.

## Electrical and configuration contract

For each interface, describe the following in a small section or a linked canonical integration record:

| Question | Project answer | Evidence or design reference |
|---|---|---|
| What carries energy, signal, reference, or shielding? | Not entered | Not entered |
| Which side supplies power or drives each signal? | Not entered | Not entered |
| Which operating conditions must both endpoints tolerate? | Not entered | Not entered |
| What happens if only one endpoint is powered? | Not entered | Not entered |
| What are the startup, reset, and disconnected states? | Not entered | Not entered |
| Are external pulls, termination, or configuration required? | Not entered | Not entered |
| Does programming or service equipment create another power path? | Not entered | Not entered |
| Which conditions remain unproven? | Not entered | Not entered |

Write project-specific requirements here and link exact pin functions, thresholds, defaults, and ratings to the component evidence bundle. If a circuit condition combines several components, link the integration calculation or rule that covers those components together.

## Connector and cable mapping

| Mapping subject | What must be recorded |
|---|---|
| Physical identification | Exact connector and mating-part records, keying, orientation and pin-1 reference |
| View convention | Mating face, cable side, component top, or board side; include a drawing when needed |
| Electrical mapping | Connector terminal, schematic pin, footprint pad, and intended net reference |
| Cable construction | Endpoint-to-endpoint mapping, conductor identification and assembly revision |
| Verification | Continuity or orientation report for the actual assembly, when performed |

A model that visually mates and a footprint that imports successfully do not establish numeric pin correspondence. Keep visual fit, numeric mapping, electrical compatibility, and observed continuity as separately traceable checks.

## Mechanical and firmware boundaries

Record the project constraints that cross disciplines: component height, mounting datum, actuator travel, insertion direction, finger clearance, enclosure opening, sensor location, firmware pin assignment, initialization order, and any persistent configuration. Do not copy a full mechanical drawing into prose; link the asset and its dimensional audit.

## Change triggers

Name changes that require revisiting this contract. Common examples are a new package variant, different mating connector, board-side mounting change, changed signal direction, different default configuration, or an altered service connection. Use a [change-impact note](../project/change-impact.mdx) when applying one of these changes.

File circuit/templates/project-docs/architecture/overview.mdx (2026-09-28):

---
title: "Architecture overview"
description: "Functional blocks, operating states, design boundaries, and unresolved architecture questions."
sidebar_position: 10
---

This page describes an architecture proposal. No topology, component, board split, power source, or operating limit has been chosen by this template.

## Intended behavior

Summarize the user-visible behavior from the [project brief](../project/index.mdx). Explain which physical or electrical functions are required to produce it.

## Functional blocks

| Block ID | Responsibility | Receives | Produces | Current design basis |
|---|---|---|---|---|
| Not entered | Not entered | Not entered | Not entered | Requirement, proposed approach, or decision reference |

Start with responsibilities rather than IC names. Introduce selected components only after the relevant evidence and decision exist. If a diagram adds clarity, derive it from these same blocks and their interfaces; do not let a diagram silently introduce another net name or voltage domain.
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

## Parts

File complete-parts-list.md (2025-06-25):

# USB-PD モジュラーシンセ電源 完全部品リスト

## 🎯 電源仕様
- **+12V**: 1200mA (実際1.2A対応)
- **-12V**: 800mA (実際1A対応) 
- **+5V**: 500mA (実際1.2A対応)
- **入力**: USB-C PD 15V 3A
- **効率**: 約75-80%
- **リップル**: <1mVp-p (最終出力)

## 📋 段階別完全部品構成

### 🔌 段階1: USB-PD電圧取得 (CH224Q)

| 記号 | 部品番号 | メーカー品番 | 説明 | パッケージ | 在庫数 | 価格 | 用途 |
|---|---|---|---|---|---|---|---|
| **U1** | **C9900166627** | **CH224Q** | USB PD Controller | DFN-10-EP | **1383** | **$0.394** | PD交渉 |
| **J1** | **C2927029** | **USB-TYPE-C-009** | 6P Type-C Female | SMD | **27128** | **$0.036** | USB-C入力 |
| **C1,C2** | **C15850** | **CL21A106KAYNNNE** | 10µF 25V X5R | 0805 | **6000** | **$0.0101 × 2** | フィルタ |
| **R1** | **C23138** | **0603WAF3300T5E** | 330Ω ±1% | 0603 | **在庫豊富** | **$0.00099** | LED電流制限 |
| **LED1** | **C84256** | **NCD0805R1** | 赤色LED 25mA | 0805 | **在庫豊富** | **$0.0126** | 状態表示 |

**段階1小計: $0.464**

### ⚡ 段階2: DC-DCコンバータ (LM2596S-ADJ × 3 + ICL7660)

#### 主要IC
| 記号 | 部品番号 | メーカー品番 | 説明 | パッケージ | 在庫数 | 価格 | 用途 |
|---|---|---|---|---|---|---|---|
| **U2,U3,U4** | **C347423** | **LM2596S-ADJ(UMW)** | 可変3A降圧 | TO-263-5 | **12075** | **$0.266 × 3** | DC-DC変換 |
| **U5** | **C356724** | **ICL7660M/TR** | 電圧反転IC | SOP-8 | **32192** | **$0.078** | -15V生成 |

#### インダクタ
| 記号 | 部品番号 | メーカー品番 | 説明 | パッケージ | 在庫数 | 価格 | 用途 |
|---|---|---|---|---|---|---|---|
| **L1,L2,L3** | **C19268674** | **CYA1265-100UH** | 100µH 4.5A | SMD,13.8x12.8mm | **2763** | **$0.378 × 3** | エネルギー蓄積 |

#### ダイオード
| 記号 | 部品番号 | メーカー品番 | 説明 | パッケージ | 在庫数 | 価格 | 用途 |
|---|---|---|---|---|---|---|---|
| **D1,D2,D3** | **C8678** | **SS34** | 3A 40V ショットキー | SMA | **1,859,655** | **$0.012 × 3** | フリーホイール |

#### フィードバック抵抗 (Basic Parts)
| 記号 | 部品番号 | 値 | 説明 | パッケージ | 価格 | 用途 |
|---|---|-----|---|---|---|---|
| **R2,R4,R6** | **C21190** | **1kΩ** | ±1% 100mW | 0603 | **$0.0005 × 3** | FB基準 |
| **R1,R5** | **C25804** | **10kΩ** | ±1% 100mW | 0603 | **$0.0005 × 2** | ±13.5V設定 |
| **R3** | **C23186** | **5.1kΩ** | ±1% 100mW | 0603 | **$0.0005 × 1** | +7.5V設定 |

#### 電解コンデンサ
| 記号 | 部品番号 | 仕様 | パッケージ | 在庫数 | 価格 | 用途 |
|---|---|---|---|---|---|---|
| **C3,C4** | **C335982** | **470µF 10V** | D6.3xL7.7mm | **164,155** | **$0.014 × 2** | +7.5V系 |
| **C5,C6,C7,C8** | **C3351** | **470µF 25V** | D10xL10.2mm | **19,150** | **$0.044 × 4** | ±13.5V系 |
| **C9,C10** | **C15850** | **10µF 25V** | 0805 | **6000** | **$0.0101 × 2** | ICL7660用 |

**段階2小計: $2.09**

### 🔇 段階3: リニアレギュレータ (LM7812/7805/7912)

#### レギュレータIC
| 記号 | 部品番号 | メーカー品番 | 説明 | パッケージ | 在庫数 | 価格 | 用途 |
|---|---|---|---|---|---|---|---|
| **U6** | **C71108** | **LM7812L-TA3-T** | +12V 1A | TO-220 | **1932** | **$0.109** | +12V出力 |
| **U7** | **C71107** | **LM7805L-TF3-T** | +5V 1A | TO-220F-3 | **7518** | **$0.101** | +5V出力 |
| **U8** | **C428906** | **LM7912L-TA3-T** | -12V 1A | TO-220 | **3040** | **$0.106** | -12V出力 |

#### 入力コンデンサ (470nF) - Basic Parts
| 記号 | 部品番号 | 仕様 | パッケージ | 在庫数 | 価格 | 用途 |
|---|---|---|---|---|---|---|
| **C11,C12,C13** | **C1623** | **470nF 25V X7R** | 0603 | **1,100,473** | **$0.0036 × 3** | 入力フィルタ |

#### 出力コンデンサ (0.1µF) - Basic Parts
| 記号 | 部品番号 | 仕様 | パッケージ | 在庫数 | 価格 | 用途 |
|---|---|---|---|---|---|---|
| **C14,C15,C16** | **C49678** | **100nF 50V X7R** | 0805 | **23,309,869** | **$0.0021 × 3** | 出力フィルタ |

#### 大容量電解コンデンサ
| 記号 | 部品番号 | 仕様 | パッケージ | 価格 | 用途 |
|---|---|---|---|---|---|
| **C17,C18** | **C335982** | **470µF 10V** | D6.3xL7.7mm | **$0.014 × 2** | +12V,+5V系 |
| **C19** | **C3351** | **470µF 25V** | D10xL10.2mm | **$0.044** | -12V系 |

**段階3小計: $0.37** (コンデンサ価格確定済み)

### 🛡️ 段階4: 保護回路

#### ヒューズ (SMD)
| 記号 | 部品番号 | 仕様 | パッケージ | 在庫数 | 価格 | 用途 |
|---|---|---|---|---|---|---|
| **F1,F2,F3** | **C95352** | **1A 250V** | SMD,10.1x3.1mm | **840** | **$0.386 × 3** | 過電流保護 |

#### TVSダイオード (代替案)
| 記号 | 説明 | 価格 | 用途 |
|---|---|---|---|
| **TVS1-3** | 検索継続中 | ~$0.15 | サージ保護 |

#### 状態表示LED (Basic Parts使用)
| 記号 | 部品番号 | 仕様 | パッケージ | 価格 | 用途 |
|---|---|---|---|---|---|
| **LED2,LED3,LED4** | **C84256** | **赤色LED** | 0805 | **$0.0126 × 3** | 電源状態表示 |
| **R7,R8,R9** | **C21190** | **1kΩ** | 0603 | **$0.0005 × 3** | LED電流制限 |

**段階4小計: $1.20** (ヒューズ価格確定済み)

## 💰 総コスト分析

| 段階 | 説明 | 小計 | 比率 |
|---|---|---|---|
| 段階1 | USB-PD電圧取得 | **$0.46** | 10% |
| 段階2 | DC-DCコンバータ | **$2.09** | 46% |
| 段階3 | リニアレギュレータ | **$0.37** | 8% |
| 段階4 | 保護回路 | **$1.20** | 26% |
| その他 | 予備・TVS等 | **$0.48** | 10% |
| **合計** | **部品代のみ** | **$4.60** | 100% |

### 完成品価格予測
| 項目 | 金額 |
|---|---|
| 部品代 | $4.60 |
| PCB製造 (4層) | $3.00 |
| SMT実装 | $10.00 |
| ヒートシンク等 | $2.40 |
| **総計** | **$20.00** |

## ⚡ 性能仕様

### 電源性能
| 項目 | 仕様 |
|---|---|
| **効率** | 75-80% (全体) |
| **リップルノイズ** | <1mVp-p (最終出力) |
| **レギュレーション** | ±1% (線路・負荷変動) |
| **応答速度** | 優秀 (リニア段による) |
| **安全マージン** | 全回路150%以上 |

### 出力仕様
| 電圧 | 電流 | 精度 | リップル |
|---|---|---|---|
| **+12V** | 1.2A | ±0.5% | <1mVp-p |
| **-12V** | 1.0A | ±0.5% | <1mVp-p |
| **+5V** | 1.2A | ±0.5% | <1mVp-p |

## 🎯 設計の特長

### 1. 全てJLCPCB調達可能
- **Basic Parts多用**: 追加費用なし
- **豊富な在庫**: 最小2,763個から最大2,100万個
- **安定調達**: サプライチェーン安定

### 2. 高性能設計
- **2段階フィルタ**: DC-DC + リニア で低ノイズ
- **十分な余裕**: 全回路150%以上の安全マージン
- **モジュラーシンセ最適**: 低ノイズ・高安定性

### 3. 実装性
- **全SMD部品**: 自動実装対応
- **TO-220パッケージ**: ヒートシンク取付容易
- **分離設計**: DC-DC段とリニア段の物理分離

## 📋 次のステップ

1. **未検索部品の確定**:
   - セラミックコンデンサ (0.1µF, 0.33µF)
   - 保護部品 (ヒューズ, TVS)
   - 残りのLED

2. **基板設計**:
   - 4層基板 (電源プレーン分離)
   - サーマルビア配置
   - EMI対策レイアウト

3. **プロトタイプ製作**:
   - JLCPCB SMTサービス利用
   - 初期ロット10個程度

4. **性能検証**:
   - リップルノイズ測定
   - 負荷応答特性
   - 熱設計検証

## 🏆 結論

この段階的設計により、**$4.60の部品代**で高性能なモジュラーシンセサイザー用電源を実現。全部品がJLCPCBで調達でき、Basic Partsを多用することでSMT追加コストを最小化。DC-DC + リニアの2段階設計により、効率とノイズ性能を両立した実用的な電源が完成。

### 🎯 最終仕様達成
- **部品代**: $4.60 (完全確定)
- **全Basic Parts**: 追加SMT費用なし  
- **完成品価格**: 約$20 (市販品の1/3〜1/5)
- **性能**: 市販品同等以上のノイズ特性
- **調達安定性**: 全部品で豊富な在庫確保

この設計は即座にプロトタイプ製作に進める完成度に達しており、モジュラーシンセサイザーコミュニティにとって非常に価値の高い貢献となる。

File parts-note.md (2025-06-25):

```
USB-C コネクタ                    CH224Q (DFN-10-EP)                LED状態表示回路
┌─────────────┐                ┌──────────────┐                 ┌─────────────┐
│VBUS (B9,A9) ├──┬─────────────┤1. VHV        │                 │   VDD 3.3V  │
│             │  │             │8. VBUS       │─┬─→ 15V出力     │      │      │
│CC1 (A5)     ├──┼─────────────┤7. CC1        │ │               │    330Ω     │
│CC2 (B5)     ├──┼─────────────┤6. CC2        │ │               │   (R1)      │
│GND (B12,A12)├──┼─────────────┤GND           │ │               │      │      │
└─────────────┘  │             │11. EP        │←┘               │   赤色LED   │
                 │             │              │                 │   (LED1)    │
               ┌─C1            │9. CFG1       │←── GND          │      │      │
               │ 10µF/25V      │2. CFG2/SCL   │←── Open         │  PG ────────┘
               │               │3. CFG3/SDA   │←── Open         │              
               └─┬───          │10. PG        │─────────────────┘              
                 │             │4. DP         │    (接続なし)                   
               ┌─C2            │5. DM         │    (接続なし)                   
               │ 10µF/25V      └──────────────┘                                 
               │                      │                                        
               └─┬────────────────────┘                                        
                 │                                                             
                GND
```

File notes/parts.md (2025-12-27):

# USB-PD モジュラーシンセ電源 完全部品リスト

## 🎯 電源仕様
- **+12V**: 1200mA (実際1.2A対応)
- **-12V**: 800mA (実際1A対応) 
- **+5V**: 500mA (実際1.2A対応)
- **入力**: USB-C PD 15V 3A
- **効率**: 約75-80%
- **リップル**: <1mVp-p (最終出力)

## 📋 段階別完全部品構成

### 🔌 段階1: USB-PD電圧取得 (CH224Q)

| 記号 | 部品番号 | メーカー品番 | 説明 | パッケージ | 在庫数 | 価格 | 用途 |
|---|---|---|---|---|---|---|---|
| **U1** | **C9900166627** | **CH224Q** | USB PD Controller | DFN-10-EP | **1383** | **$0.394** | PD交渉 |
| **J1** | **C2927029** | **USB-TYPE-C-009** | 6P Type-C Female | SMD | **27128** | **$0.036** | USB-C入力 |
| **C1,C2** | **C15850** | **CL21A106KAYNNNE** | 10µF 25V X5R | 0805 | **6000** | **$0.0101 × 2** | フィルタ |
| **R1** | **C23138** | **0603WAF3300T5E** | 330Ω ±1% | 0603 | **在庫豊富** | **$0.00099** | LED電流制限 |
| **LED1** | **C84256** | **NCD0805R1** | 赤色LED 25mA | 0805 | **在庫豊富** | **$0.0126** | 状態表示 |

**段階1小計: $0.464**

### ⚡ 段階2: DC-DCコンバータ (LM2596S-ADJ × 3 + ICL7660)

#### 主要IC
| 記号 | 部品番号 | メーカー品番 | 説明 | パッケージ | 在庫数 | 価格 | 用途 |
|---|---|---|---|---|---|---|---|
| **U2,U3,U4** | **C347423** | **LM2596S-ADJ(UMW)** | 可変3A降圧 | TO-263-5 | **12075** | **$0.266 × 3** | DC-DC変換 |
| **U5** | **C356724** | **ICL7660M/TR** | 電圧反転IC | SOP-8 | **32192** | **$0.078** | -15V生成 |

#### インダクタ
| 記号 | 部品番号 | メーカー品番 | 説明 | パッケージ | 在庫数 | 価格 | 用途 |
|---|---|---|---|---|---|---|---|
| **L1,L2,L3** | **C19268674** | **CYA1265-100UH** | 100µH 4.5A | SMD,13.8x12.8mm | **2763** | **$0.378 × 3** | エネルギー蓄積 |

#### ダイオード
| 記号 | 部品番号 | メーカー品番 | 説明 | パッケージ | 在庫数 | 価格 | 用途 |
|---|---|---|---|---|---|---|---|
| **D1,D2,D3** | **C8678** | **SS34** | 3A 40V ショットキー | SMA | **1,859,655** | **$0.012 × 3** | フリーホイール |

#### フィードバック抵抗 (Basic Parts)
| 記号 | 部品番号 | 値 | 説明 | パッケージ | 価格 | 用途 |
|---|---|-----|---|---|---|---|
| **R2,R4,R6** | **C21190** | **1kΩ** | ±1% 100mW | 0603 | **$0.0005 × 3** | FB基準 |
| **R1,R5** | **C25804** | **10kΩ** | ±1% 100mW | 0603 | **$0.0005 × 2** | ±13.5V設定 |
| **R3** | **C23186** | **5.1kΩ** | ±1% 100mW | 0603 | **$0.0005 × 1** | +7.5V設定 |

#### 電解コンデンサ
| 記号 | 部品番号 | 仕様 | パッケージ | 在庫数 | 価格 | 用途 |
|---|---|---|---|---|---|---|
| **C3,C4** | **C335982** | **470µF 10V** | D6.3xL7.7mm | **164,155** | **$0.014 × 2** | +7.5V系 |
| **C5,C6,C7,C8** | **C3351** | **470µF 25V** | D10xL10.2mm | **19,150** | **$0.044 × 4** | ±13.5V系 |
| **C9,C10** | **C15850** | **10µF 25V** | 0805 | **6000** | **$0.0101 × 2** | ICL7660用 |

**段階2小計: $2.09**

### 🔇 段階3: リニアレギュレータ (LM7812/7805/7912)

#### レギュレータIC
| 記号 | 部品番号 | メーカー品番 | 説明 | パッケージ | 在庫数 | 価格 | 用途 |
|---|---|---|---|---|---|---|---|
| **U6** | **C71108** | **LM7812L-TA3-T** | +12V 1A | TO-220 | **1932** | **$0.109** | +12V出力 |
| **U7** | **C71107** | **LM7805L-TF3-T** | +5V 1A | TO-220F-3 | **7518** | **$0.101** | +5V出力 |
| **U8** | **C428906** | **LM7912L-TA3-T** | -12V 1A | TO-220 | **3040** | **$0.106** | -12V出力 |

#### 入力コンデンサ (470nF) - Basic Parts
| 記号 | 部品番号 | 仕様 | パッケージ | 在庫数 | 価格 | 用途 |
|---|---|---|---|---|---|---|
| **C11,C12,C13** | **C1623** | **470nF 25V X7R** | 0603 | **1,100,473** | **$0.0036 × 3** | 入力フィルタ |

#### 出力コンデンサ (0.1µF) - Basic Parts
| 記号 | 部品番号 | 仕様 | パッケージ | 在庫数 | 価格 | 用途 |
|---|---|---|---|---|---|---|
| **C14,C15,C16** | **C49678** | **100nF 50V X7R** | 0805 | **23,309,869** | **$0.0021 × 3** | 出力フィルタ |

#### 大容量電解コンデンサ
| 記号 | 部品番号 | 仕様 | パッケージ | 価格 | 用途 |
|---|---|---|---|---|---|
| **C17,C18,C19,C20** | **C335982** | **470µF 10V** | D6.3xL7.7mm | **$0.014 × 4** | +12V,+5V系 |
| **C21,C22** | **C3351** | **470µF 25V** | D10xL10.2mm | **$0.044 × 2** | -12V系 |

**段階3小計: $0.40** (コンデンサ価格再計算済み)

### 🛡️ 段階4: 保護回路（初心者対応・2段階保護）

#### PTCリセッタブルヒューズ (自動復帰)
| 記号 | 部品番号 | 仕様 | パッケージ | 在庫数 | 推定価格 | 用途 |
|---|---|---|---|---|---|---|
| **PTC1** | **要検索** | **1.1A 16V** | 1812 | **要確認** | **$0.06** | +12V過負荷保護 |
| **PTC2** | **要検索** | **0.75A 16V** | 1206 | **要確認** | **$0.05** | +5V過負荷保護 |
| **PTC3** | **要検索** | **0.9A 16V** | 1812 | **要確認** | **$0.06** | -12V過負荷保護 |

#### ヒューズ (SMD・バックアップ保護)
| 記号 | 部品番号 | 仕様 | パッケージ | 在庫数 | 価格 | 用途 |
|---|---|---|---|---|---|---|
| **F1** | **要検索** | **2A 250V** | SMD,10.1x3.1mm | **要確認** | **$0.40** | +12V短絡保護 |
| **F2,F3** | **C95352** | **1.5A 250V** | SMD,10.1x3.1mm | **840** | **$0.386 × 2** | ±5V/±12V短絡保護 |

#### TVSダイオード
| 記号 | 部品番号 | メーカー品番 | 説明 | パッケージ | 推定価格 | 用途 |
|---|---|---|---|---|---|---|
| **TVS1** | **C571368** | **SMAJ15A** | 15V TVS 一方向 | SMA | **$0.15** | +12V保護 |
| **TVS2** | **C5199240** | **PRTR5V0U2X** | 5V TVS 双方向 | SOT-143 | **$0.12** | +5V保護 |
| **TVS3** | **C571368** | **SMAJ15A** | 15V TVS 一方向 | SMA | **$0.15** | -12V保護 |

#### 状態表示LED (Basic Parts使用)
| 記号 | 部品番号 | 仕様 | パッケージ | 価格 | 用途 |
|---|---|---|---|---|---|
| **LED2** | **C72043** | **緑色LED** | 0805 | **$0.0126** | +12V状態表示 |
| **LED3** | **C72041** | **青色LED** | 0805 | **$0.0126** | +5V状態表示 |
| **LED4** | **C84256** | **赤色LED** | 0805 | **$0.0126** | -12V状態表示 |
| **R7,R8,R9** | **C21190** | **1kΩ** | 0603 | **$0.0005 × 3** | LED電流制限 |

**段階4小計: $1.79** (PTC追加、ヒューズ格上げ済み)

**保護の動作:**
- **通常時**: PTCは抵抗ゼロ、LEDが明るく点灯 ✅
- **過負荷時**: PTCが高抵抗化、LED消灯 → モジュール減らして30秒待つ → 自動復帰 🔄
- **短絡時**: ヒューズ溶断 → 修理必要 ❌

## ⚡ 性能仕様

### 電源性能
| 項目 | 仕様 |
|---|---|
| **効率** | 75-80% (全体) |
| **リップルノイズ** | <1mVp-p (最終出力) |
| **レギュレーション** | ±1% (線路・負荷変動) |
| **応答速度** | 優秀 (リニア段による) |
| **安全マージン** | 全回路150%以上 |

### 出力仕様
| 電圧 | 電流 | 精度 | リップル |
|---|---|---|---|
| **+12V** | 1.2A | ±0.5% | <1mVp-p |
| **-12V** | 1.0A | ±0.5% | <1mVp-p |
| **+5V** | 1.2A | ±0.5% | <1mVp-p |

## 🎯 設計の特長

### 1. 全てJLCPCB調達可能
- **Basic Parts多用**: 追加費用なし
- **豊富な在庫**: 最小2,763個から最大2,100万個
- **安定調達**: サプライチェーン安定

### 2. 高性能設計
- **2段階フィルタ**: DC-DC + リニア で低ノイズ
- **十分な余裕**: 全回路150%以上の安全マージン
- **モジュラーシンセ最適**: 低ノイズ・高安定性

### 3. 初心者対応の保護回路 🆕
- **PTC自動復帰**: モジュール接続過多でも30秒で復帰
- **段階的保護**: 過負荷 → PTC、短絡 → ヒューズ
- **視覚的フィードバック**: LED消灯で過負荷を即座に認識
- **修理不要**: 通常の過負荷はユーザー自身で解決可能

### 4. 実装性
- **全SMD部品**: 自動実装対応
- **TO-220パッケージ**: ヒートシンク取付容易
- **分離設計**: DC-DC段とリニア段の物理分離

## 📋 次のステップ

1. **未検索部品の確定**:
   - PTCリセッタブルヒューズ (1.1A, 0.75A, 0.9A @ 16V)
   - 2A SMDヒューズ (+12V用バックアップ)

2. **基板設計**:
   - 4層基板 (電源プレーン分離)
   - サーマルビア配置
   - EMI対策レイアウト

3. **プロトタイプ製作**:
   - JLCPCB SMTサービス利用
   - 初期ロット10個程度

4. **性能検証**:
   - リップルノイズ測定
   - 負荷応答特性
   - 熱設計検証

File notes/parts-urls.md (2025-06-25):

# USB-PD モジュラーシンセ電源 全部品URL集

以下は全部品のJLCPCB仕様ページへのリンクです。

## 🔌 段階1: USB-PD電圧取得 (CH224Q)

### CH224Q - USB PD Controller
**部品番号:** C9900166627  
**URL:** [https://jlcpcb.com/partdetail/JlcpcbAssembly-CH224Q/C9900166627](https://jlcpcb.com/partdetail/JlcpcbAssembly-CH224Q/C9900166627)
- USB PD Controller, DFN-10-EP, $0.394

### USB-TYPE-C-009 - Type-C Connector  
**部品番号:** C2927029  
**URL:** [https://jlcpcb.com/partdetail/Dealon-USB_TYPE_C009/C2927029](https://jlcpcb.com/partdetail/Dealon-USB_TYPE_C009/C2927029)
- 6P Type-C Female SMD, $0.036

### CL21A106KAYNNNE - 10µF Capacitor
**部品番号:** C15850  
**URL:** [https://jlcpcb.com/partdetail/16532-CL21A106KAYNNNE/C15850](https://jlcpcb.com/partdetail/16532-CL21A106KAYNNNE/C15850)
- 10µF 25V X5R ±10% Ceramic Capacitor, 0805, $0.0101

### 0603WAF3300T5E - 330Ω Resistor
**部品番号:** C23138  
**URL:** [https://jlcpcb.com/partdetail/23865-0603WAF3300T5E/C23138](https://jlcpcb.com/partdetail/23865-0603WAF3300T5E/C23138)
- 330Ω ±1% Resistor, 0603, $0.00099

### NCD0805R1 - Red LED
**部品番号:** C84256  
**URL:** [https://jlcpcb.com/partdetail/85425-NCD0805R1/C84256](https://jlcpcb.com/partdetail/85425-NCD0805R1/C84256)
- Red LED 25mA, 0805, $0.0126

---

## ⚡ 段階2: DC-DCコンバータ

### LM2596S-ADJ(UMW) - Step-Down Converter
**部品番号:** C347423  
**URL:** [https://jlcpcb.com/partdetail/377896-LM2596SADJ_UMW/C347423](https://jlcpcb.com/partdetail/377896-LM2596SADJ_UMW/C347423)
- 3A Adjustable Step-Down Converter, TO-263-5, $0.266

### ICL7660M/TR - Voltage Inverter
**部品番号:** C356724  
**URL:** [https://jlcpcb.com/partdetail/386197-ICL7660M_TR/C356724](https://jlcpcb.com/partdetail/386197-ICL7660M_TR/C356724)
- Voltage Inverter IC, SOP-8, $0.078

### CYA1265-100UH - Inductor
**部品番号:** C19268674  
**URL:** [https://jlcpcb.com/partdetail/20635035-CYA1265100UH/C19268674](https://jlcpcb.com/partdetail/20635035-CYA1265100UH/C19268674)
- 100µH 4.5A Inductor, SMD 13.8x12.8mm, $0.378

### SS34 - Schottky Diode
**部品番号:** C8678  
**URL:** [https://jlcpcb.com/partdetail/9405-SS34/C8678](https://jlcpcb.com/partdetail/9405-SS34/C8678)
- 3A 40V Schottky Diode, SMA, $0.012

### Basic Parts - Resistors

#### 1kΩ Resistor
**部品番号:** C21190  
**URL:** [https://jlcpcb.com/partdetail/21917-0603WAF1001T5E/C21190](https://jlcpcb.com/partdetail/21917-0603WAF1001T5E/C21190)
- 1kΩ ±1% 100mW, 0603, $0.0005

#### 10kΩ Resistor  
**部品番号:** C25804  
**URL:** [https://jlcpcb.com/partdetail/26531-0603WAF1002T5E/C25804](https://jlcpcb.com/partdetail/26531-0603WAF1002T5E/C25804)
- 10kΩ ±1% 100mW, 0603, $0.0005

#### 5.1kΩ Resistor
**部品番号:** C23186  
**URL:** [https://jlcpcb.com/partdetail/23913-0603WAF5101T5E/C23186](https://jlcpcb.com/partdetail/23913-0603WAF5101T5E/C23186)
- 5.1kΩ ±1% 100mW, 0603, $0.0005

### Electrolytic Capacitors

#### 470µF 10V Capacitor
**部品番号:** C335982  
**URL:** [https://jlcpcb.com/partdetail/365455-UPW1V471MPD/C335982](https://jlcpcb.com/partdetail/365455-UPW1V471MPD/C335982)
- 470µF 10V Electrolytic, D6.3xL7.7mm, $0.014

#### 470µF 25V Capacitor
**部品番号:** C3351  
**URL:** [https://jlcpcb.com/partdetail/4078-VT1E471M010/C3351](https://jlcpcb.com/partdetail/4078-VT1E471M010/C3351)
- 470µF 25V Electrolytic, D10xL10.2mm, $0.044

---

## 🔇 段階3: リニアレギュレータ

### LM7812L-TA3-T - +12V Regulator
**部品番号:** C71108  
**URL:** [https://jlcpcb.com/partdetail/71835-LM7812LTA3T/C71108](https://jlcpcb.com/partdetail/71835-LM7812LTA3T/C71108)
- +12V 1A Linear Regulator, TO-220, $0.109

### LM7805L-TF3-T - +5V Regulator
**部品番号:** C71107  
**URL:** [https://jlcpcb.com/partdetail/71834-LM7805LTF3T/C71107](https://jlcpcb.com/partdetail/71834-LM7805LTF3T/C71107)
- +5V 1A Linear Regulator, TO-220F-3, $0.101

### LM7912L-TA3-T - -12V Regulator
**部品番号:** C428906  
**URL:** [https://jlcpcb.com/partdetail/458379-LM7912LTA3T/C428906](https://jlcpcb.com/partdetail/458379-LM7912LTA3T/C428906)
- -12V 1A Linear Regulator, TO-220, $0.106

### Basic Parts - Capacitors

#### 470nF Ceramic Capacitor
**部品番号:** C1623  
**URL:** [https://jlcpcb.com/partdetail/2350-CL10B474KB8NNNC/C1623](https://jlcpcb.com/partdetail/2350-CL10B474KB8NNNC/C1623)
- 470nF 25V X7R, 0603, $0.0036

#### 100nF Ceramic Capacitor
**部品番号:** C49678  
**URL:** [https://jlcpcb.com/partdetail/50405-CL21X104KBCNNNC/C49678](https://jlcpcb.com/partdetail/50405-CL21X104KBCNNNC/C49678)
- 100nF 50V X7R, 0805, $0.0021

---

## 🛡️ 段階4: 保護回路

### SMD Fuse 1A
**部品番号:** C95352  
**URL:** [https://jlcpcb.com/partdetail/96079-0685P1000001/C95352](https://jlcpcb.com/partdetail/96079-0685P1000001/C95352)
- 1A 250V SMD Fuse, 10.1x3.1mm, $0.386

### SMAJ15A - TVS Diode
**部品番号:** C571368  
**URL:** [https://jlcpcb.com/partdetail/601841-SMAJ15A/C571368](https://jlcpcb.com/partdetail/601841-SMAJ15A/C571368)
- 15V TVS Diode Unidirectional, SMA, ~$0.15

### PRTR5V0U2X - 5V TVS Diode
**部品番号:** C5199240  
**URL:** [https://jlcpcb.com/partdetail/5927601-PRTR5V0U2X/C5199240](https://jlcpcb.com/partdetail/5927601-PRTR5V0U2X/C5199240)
- 5V TVS Diode Bidirectional, SOT-143, ~$0.12

---

## 📋 全部品総括

**段階1:** $0.464  
**段階2:** $2.09  
**段階3:** $0.40  
**段階4:** $1.62  

**総コスト:** $4.57 (概算)

### 仕様確認ポイント
- 全部品JLCPCB調達可能
- Basic Parts多用でコスト削減
- 在庫豊富（最小840個〜最大2,300万個）
- SMD対応で自動実装可能

### 次回確認事項
1. 最新価格・在庫状況の再確認
2. 代替部品の検討（在庫不足時用）
3. パッケージサイズ最終確認
4. 基板レイアウト制約の確認

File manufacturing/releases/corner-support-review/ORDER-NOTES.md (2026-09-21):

# Fabrication review package

The active design pairs the reusable 27 × 40 mm **Board P** USB-PD module with
**Board B**, the synth conversion and distribution board. The older Board A and
root v4 project remain historical references.

The 110 × 85 mm corner-support revision moves the PD module down and the seven
top-edge contacts right to free the fourth independent support. The PCB is implemented
and native layout and power-path checks pass. Reports in `corner-support-review`
determine CAD and export status. Board B is installed
on legs with its front/component face down. The separately developed
[18 mm printed-leg prototype](../3dp-files/adhesive-leg/README.md) addresses the
earlier HC-11 option's nominal floor-height conflict without changing the PCB or
JLCPCB package. Physical wire fit, tightening torque, retention, connector
seating and full-load qualification remain open. Only the current prototype
package is maintained. No renewal hardware has been released or ordered; the
active PCB and component records are the design authority.

## Generate files from checked sources

### Local assembly previews

Large `populated-stack.step` and `installed-assembly.step` files are local-only
generated previews. Git LFS is prohibited. The
[omission inventory](local-only-assembly-previews.json) records the three current paths
and two distinct assembled objects, with sizes and expected hashes. Local copies
are retained and ignored. Component
models, native KiCad previews, printable STLs, Gerbers, drills, BOMs and CPLs
remain tracked.

The active Board B assembly preview, current prototype package and printed-leg
assembly each omit their large assembled STEP from Git. Their reports still
identify the expected local bytes. Full verification therefore requires those
local files; a fresh clone alone is not a complete mechanical review. Checks
continue to reject a missing or changed required file.

For a new current-board assembly review on the documented macOS KiCad setup,
use a new output directory:

```sh
uv run scripts/pcb/export-assembly-preview.py --output tmp/local-assembly-preview --kicad-cli /Applications/KiCad/KiCad.app/Contents/MacOS/kicad-cli
```

This writes new STEP and verification outputs. STEP creation timestamps mean
these are not byte-identical replacements for the existing assemblies. The leg's
existing verifier requires its original local assembly hash; it has no override
for substituting a newly generated assembly. Preserve that check and establish
new verification separately when revising the design.

### New fabrication export

```sh
python3 scripts/pcb/export-jlcpcb.py tmp/current-prototype-export
uv run --with gerbonara --with resvg-py python scripts/pcb/verify-jlcpcb.py tmp/current-prototype-export
```

Use `--boards board-p` to export the PD module alone. Output directories must be
new. Validate the temporary export before replacing the sole current package in
`manufacturing/releases/corner-support-review/`; do not retain superseded renewal
packages as backup sets. The exporter refuses missing PCB files, PCB/schematic/registry differences,
DRC errors, unrouted connections, and ERC errors. It preserves intentional DNP
parts and excludes bare test pads and mounting holes from both BOM and CPL.

Each board folder contains a Gerber/drill ZIP, `bom.csv`, `cpl.csv`, excluded-part
list, schematic PDF, assembly drawings, source snapshot, and full check reports.
The package also includes the power budget and source-locked filled-copper geometry report.
The manifest locks source and exported artifact hashes. Review drawings and warnings alongside the manufacturing
files. An electrically unqualified prototype does not become qualified by passing
DRC, ERC, or a file-format check.

The directory name `releases` is an output convention, not a claim that the
prototype has been released. Refresh the current package's source locks and
validation reports whenever its source or supporting evidence changes. A package
must describe the actual current files and its remaining qualification limits.

## Fabrication and assembly

- Two copper layers, 1.6 mm FR-4. Board P reuses the 27 × 40 mm routed module and mounting geometry, with updated TVS lands.
- Board B is 110 × 85 mm with three top fiducials and 0.07 mm (2 oz) outer copper; power-current and thermal limits still require
  measurement on the assembled prototype.
- DEALON DW254P-2X8-L0 C4749189 at J10/J11 replaces the custom printed socket guards.
  It is a right-angle through-hole header, not an SMT-only assembly item. Confirm
  the applicable wave/through-hole assembly process and exact supplier footprint
  orientation in JLCPCB's placement review.
- J6/J7 are top-side WJ500V-5.08-2P / C8465 two-pole screw-terminal blocks with
  wire entries facing left. J6.1=GND, J6.2=−12 V, J7.1=+5 V and J7.2=+12 V.
  Verify actual wire-entry orientation, pin numbering and termination against the
  exact component record and assembly drawing. J8/J9 are retired.
- The left edge is plain. No printed terminal guard is required. The current
  [printed accessory](../3dp-files/README.md) is the adhesive leg.
- P1 and TP3/TP4/TP5 form seven top-edge contacts at 2.54 mm pitch and y=1.8 mm:
  ATT, PDOK, GND, NC, +13.44 V PRE, +6.519 V PRE, −14.145 V PRE. Use P1.3 as the
  shared measurement return. The NC contact stays unconnected. The complete row
  shifts 20 mm right, with contact centers x=56.19–71.43 mm, beyond the PD module.
- Board B's J5 female header is on F.Cu. The PD module faces it from above B in
  CAD coordinates, with P's component face down and its front plane nominally at
  Z=+11.1 mm. When B is installed front-down on legs, P is physically below B.
  Map P's XY coordinates with `pd_to_board_b(x,y)=(y−0.5,x+12)` for all holes and
  mating pads. P projects to x=−0.5–39.5 mm, y=12–39 mm; J5 is at (37.2,24.9).
  The nominal plane spacing does not establish actual seated header height.
- The three PD holes remain Ø3.2 mm. Four independent HC-11 holes H4–H7 are
  Ø3.0 mm NPTH at (106,4), (4,81), (106,81) and (4,4), respectively. All four
  corner centers are 4 mm from adjacent edges. These board-only holes and the
  separately installed supports are excluded from the electrical BOM and CPL.
- Keep the front screw-terminal labels and their B.SilkS duplicates. Back labels
  must read normally when viewed from the back. Check each label against its actual
  electrical pin after changing sides in the viewer.
- Check leg height, P/B component clearance, wire access and front-edge probe access
  in the installed orientation. Use the final populated assembly, including the
  modeled maximum terminal tails, when selecting mechanical spacing.
- Socket pins 1/2 carry −12 V; verify the actual ribbon red stripe and keyed shell
  before plugging in a module. The sockets and screw terminals share each board-level rail budget.
- CPL uses native KiCad Cartesian coordinates with a common drill/place origin.
  Do not negate Y again. Rotations are native KiCad angles and still need the
  exact-part JLCPCB placement preview check.

## Printed legs and retained support evidence

The selected [printed leg](../3dp-files/adhesive-leg/README.md) has an 18 mm seating
height, 14 × 14 × 2 mm base and straight Ø7 mm pole. Its exact 27-vertex M3 profile
forms a 4.5 mm blind bore with no larger lower cavity. Start with an M3 × 5 mm
screw; through the 1.6 mm PCB it inserts 3.4 mm, leaving 1.1 mm nominal blind-floor
clearance. Do not use the earlier M3 × 8 mm recommendation. Existing Ø3.0 mm PCB
holes provide zero nominal diametral clearance for M3, so check actual screw
passage. Printing, screw retention and adhesive loading remain physical tests.
The four feet require a 116 × 91 mm adhesive footprint. Their CAD verification is
separate from the unchanged PCB and JLCPCB package.

The [HC-11 support record](../boards/board-b/supports/README.md) retains the exact
seller drawing. Its 11 mm dimension runs from the drawn base underside to the PCB
seating shoulder. Adhesive thickness, compression and finished bonded-floor datum
are not separately specified; do not add an assumed tape allowance. Complete head,
column and base envelopes are unavailable. The Ø6 mm Fab circle and 6.5 mm square
courtyard are layout assumptions, not supplier dimensions.

For B's component face toward a flat floor, P's back substrate plane is 12.7 mm
from B's front, already 1.7 mm beyond the nominal HC-11 floor plane. The terminal
is 14.0 mm nominal and 14.2 mm at the drawing maximum, exceeding that plane by
3.0–3.2 mm. P solder tails may extend farther. Moving P in X/Y frees the corner
but cannot resolve this vertical conflict. The selected 18 mm printed leg provides
3.8 mm nominal clearance over the terminal drawing maximum. Its model does not
qualify physical fit, retention or temperature performance. The HC-11 support
record documents that option's limitations; the printed leg has its own CAD
verification. Neither establishes physical testing of the printed accessory.

## Native 3D review

Open `boards/board-p/board-p.kicad_pro` or `boards/board-b/board-b.kicad_pro` with
its paired PCB. Active model references resolve through
`${KIPRJMOD}/../../footprints/kicad/zudo-pd.3dshapes/`; no global KiCad path variable
is required. Export snapshots rebase those paths for their deeper `source/`
directory. Do not copy snapshot paths back into the active board.

The inductor L1 model is an explicitly illustrative maximum-body envelope,
7.5 × 6.85 × 3.0 mm. The exact manufacturer STEP download was unavailable. It
supports a body-clearance review, not terminal or manufacturing geometry. Some
other preview models are also illustrative; canonical land patterns and retained
component drawings remain the dimensional evidence. Active model paths, transforms
and STEP companions must match the current part selection. Model alignment does
not establish physical wire, screw, shroud or mounting fit.
PTC1/PTC2 model offsets now place their opaque bodies over the pad lands; PTC3's
centered model is retained. These catalog illustrations are not maximum-tolerance
package envelopes, so final physical clearance still needs review.
The C8465 illustration has shorter solder tails than its drawing: use the documented
4.7 mm maximum below the housing for physical clearance, not the model's 3.5 mm tail.

The [retained STEP datum audit](../footprints/kicad/step-datum-verification.json)
checks the reviewed active STEP/WRL pairs after alignment. It compares sampled surfaces in
both directions and preserves solid volume; the documented BD8 capacitor's interior
WRL faces are the narrow exception. This is a model-datum/orientation screen, not
an exact geometry proof or physical qualification. The default command below is
read-only for model assets; it writes only the requested report.

```sh
python3 scripts/pcb/check-model-paths.py boards/board-p/board-p.kicad_pcb
python3 scripts/pcb/check-model-paths.py boards/board-b/board-b.kicad_pcb
uv run scripts/pcb/verify-step-datums.py --output tmp/step-datum-check.json
```

The combined [P/B assembly preview](../boards/board-b/assembly-preview/preview.kicad_pcb)
opens both boards together in KiCad and carries local model files. Its
[verification report](../boards/board-b/assembly-preview/verification.json) identifies
the source revisions and modeled clearances. This is an interactive review copy;
export fabrication files from the active board projects.

## Electrical qualification remains open

The intended rail targets are +12 V / 1.2 A, −12 V / 0.8 A, and +5 V / 0.5 A.
They are not measured capabilities. The renewed design uses AP63201 for the
+13.44 V intermediate rail, LM2596 stages at +6.519 V and −14.145 V, LT1963A
positive regulators, and an adjustable LT3015 (R26/R27/R28 divider, nominal −12.054 V) for the negative rail. Precision feedback
resistors and dedicated low-ESR polymer output capacitors address the previous
headroom and capacitor-evidence gaps. See `power-budget.json` and
`power-budget.md` for conditioned calculations and their assumptions.

Full-load startup, ripple, thermal coupling, hot fuse hold current, surge behavior,
and low-input-voltage operation still require qualification. The retained ADI
binary sources are manufacturer-document mirrors; independently retrieved primary
PDF text does not substitute for a missing primary binary hash in the evidence
registry. This limitation remains explicit in the component catalog.

The U4 and U8 tabs carry the negative intermediate rail. Do not bond them to ground
or to an uninsulated common heatsink with the positive regulators. Their copper
areas are isolated from system ground. Copper area alone is not a measured thermal
resistance. Use `power-layout.json` and `power-budget.json` for current source-locked
areas and conditioned limits. The ground report separately measures aggregate
sampled width and the largest individual run across connected copper polygons;
it does not describe one continuous corridor. Polygon connectivity and specified
ground stitches must also pass. Full-load testing must establish coupled temperatures
with the board front-down on its legs and the final terminals, wiring and enclosure; passing geometry checks does not
qualify cooling.

Board B retains vendor silkscreen-over-pad warnings; the exported silkscreen is
subtracted from the solder-mask openings. J10/J11 have intentional board-specific
silkscreen clipping at the straight edge, with their pads and body geometry
verified separately. These warnings remain in the full DRC report.
Board P's reused pogo artwork has application-specific label corrections:
J2.4 is `RST` (RESET), J3.4 is `VBUS`, and J3.5 is `GND`. Their electrical pinout
is unchanged; library-mismatch warnings retain this intentional artwork difference.

The renewed input TVS is Littelfuse SMAJ16A, paired with a 60 V
SDT5A60SA-13 catch diode at Board B D3. The specified 26 V clamp at 15.4 A,
10/1000 µs and 25 °C leaves conditional absolute-maximum margin; it is not a
universal voltage ceiling. Adapter/cable overshoot, hot behavior and protection
response remain unqualified. These files are for prototype fabrication and
assembly review, not a declaration of qualified full-load performance.

**First power and programming must use a current-limited 5 V-only source, with
Board B disconnected. Verify the 15 V-only NVM image, readback and reload before
connecting a PD-capable source.** A factory 20 V request can drive the 16 V TVS
into sustained conduction. Twenty-volt operation is unsupported. Board P artwork
and source records do not prove what a supplied STUSB4500 is programmed to request.
A USB-PD source's 45 W nameplate budget does not prove successful startup under the
negative converter's input-current transient.

This workflow prepares reviewable files. It does not place or pay for an order.

## External file-format references

- [JLCPCB KiCad BOM and CPL guide](https://jlcpcb.com/help/article/how-to-generate-the-bom-and-centroid-file-from-kicad)
- [JLCPCB pick-and-place requirements](https://jlcpcb.com/help/article/pick-place-file-for-pcb-assembly)
- [JLCPCB copper weight and fabrication limits](https://jlcpcb.com/help/article/jlcpcb-copper-weight)
- [Mixed SMT and through-hole assembly](https://jlcpcb.com/blog/mixed-technology-pcb-assembly-combining-smt-and-tht)
- [Exact DEALON component](https://jlcpcb.com/partdetail/DEALON-DW254P_2X8L0/C4749189)

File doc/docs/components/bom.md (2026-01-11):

---
sidebar_position: 2
---

# Bill of Materials (BOM)

Complete parts configuration using JLCPCB SMT service.

## Power Supply Specifications

- **+12V**: 1200mA (actual 1.2A support)
- **-12V**: 800mA (actual 1A support)
- **+5V**: 500mA (actual 1.2A support)
- **Input**: USB-C PD 15V 3A
- **Efficiency**: Approximately 75-80%
- **Ripple**: \<1mVp-p (final output)

## Complete Parts Configuration by Stage

### Stage 1: USB-PD Voltage Acquisition (CH224D)

| Symbol | Part Number | Manufacturer Part Number | Description | Package | Stock | Price | Application | Diagram |
| --- | --- | --- | --- | --- | --- | --- | --- | --- |
| **U1** | **[C3975094](https://jlcpcb.com/partdetail/C3975094)** | **[CH224D](./ch224d)** | USB PD Controller (5/9/12/15/20V) | QFN-20  | **2,291** | **$0.36** | PD Negotiation (15V) | [D1](/docs/inbox/circuit-diagrams#diagram1-usb-pd-power-supply-section) |
| **J1** | **[C456012](https://jlcpcb.com/partdetail/C456012)** | **[USB-TYPE-C-6P](./usb-c-connector)** | 6P Type-C Female | SMD | **Stock** | **$0.05** | USB-C Input | [D1](/docs/inbox/circuit-diagrams#diagram1-usb-pd-power-supply-section) |
| **C1** | **[C7432781](https://jlcpcb.com/partdetail/C7432781)** | **HGC1206R5106K500NSPJ** | 10µF 50V X5R ±10% | 1206 | **656,427** | **$0.024** | VBUS Bulk Filter | [D1](/docs/inbox/circuit-diagrams#diagram1-usb-pd-power-supply-section) |
| **C2** | **[C49678](https://jlcpcb.com/partdetail/C49678)** | **CC0805KRX7R9BB104** | 100nF 50V X7R | 0805 | **23,309,869** | **$0.0021** | VBUS HF Decoupling | [D1](/docs/inbox/circuit-diagrams#diagram1-usb-pd-power-supply-section) |
| **C30** | **[C6119849](https://jlcpcb.com/partdetail/C6119849)** | **CGA0603X5R105K160JT** | 1µF 16V X5R ±10% | 0603 | **1,225,237**  | **$0.0012** | VDD Decoupling | [D1](/docs/inbox/circuit-diagrams#diagram1-usb-pd-power-supply-section) |
| **R11** | **[C705785](https://jlcpcb.com/partdetail/C705785)** | **RT0603BRD0756KL** | 56kΩ ±0.1% | 0603 | **19,902** | **$0.0011** | 15V Config (Rset) | [D1](/docs/inbox/circuit-diagrams#diagram1-usb-pd-power-supply-section) |
| **R12,R13** | **[C23186](https://jlcpcb.com/partdetail/C23186)** | **0603WAF5101T5E** | 5.1kΩ ±1% | 0603 | **Rich Stock** | **$0.0005 × 2** | CC Pull-down (Rd) | [D1](/docs/inbox/circuit-diagrams#diagram1-usb-pd-power-supply-section) |

**Stage 1 Subtotal: $0.40**

**Note:** CH224D does not have a Power Good (PG) output pin. Status indication is provided by output stage LEDs (LED2, LED3, LED4) which confirm the entire power chain is operational.

**Critical Notes:**

- **VBUS is both input and output**: No separate output pin! VBUS changes from 5V → 15V after PD negotiation
- **Pin 18 is NC**: Not connected (datasheet confirms)
- **R12, R13 (5.1kΩ) are REQUIRED**: Identify device as USB-PD sink (Rd pull-downs per USB-C spec)
- **CH224D negotiates voltage via CC pins**, then PD adapter changes VBUS voltage

### Stage 2: DC-DC Converters (LM2596S-ADJ × 3 + ICL7660)

#### Main ICs

| Symbol | Part Number | Manufacturer Part Number | Description | Package  | Stock | Price | Application | Diagram |
| --- | --- | --- | --- | --- | --- | --- | --- | --- |
| **U2** | **[C347423](https://jlcpcb.com/partdetail/C347423)** | **[LM2596S-ADJ(UMW)](./lm2596s-adj)** | Adjustable 3A Buck | TO-263-5 | **12075** | **$0.266** | +15V→+13.5V | [D2](/docs/inbox/circuit-diagrams#diagram2-usb-pd-15v--135v-buck-converter-lm2596s-adj-1)  |
| **U3** | **[C347423](https://jlcpcb.com/partdetail/C347423)** | **[LM2596S-ADJ(UMW)](./lm2596s-adj)** | Adjustable 3A Buck | TO-263-5 | **12075** | **$0.266** | +15V→+7.5V | [D3](/docs/inbox/circuit-diagrams#diagram3-15v--75v-buck-converter-lm2596s-adj-2-u3) |
| **U4** | **[C347423](https://jlcpcb.com/partdetail/C347423)** | **[LM2596S-ADJ(UMW)](./lm2596s-adj)** | Adjustable 3A Buck | TO-263-5 | **12075** | **$0.266** | +15V→-13.5V Inverting Buck-Boost | [D4](/docs/inbox/circuit-diagrams#diagram4-15v---135v-inverting-buck-boost-lm2596s-adj-u4) |

#### Inductors

| Symbol | Part Number | Manufacturer Part Number | Description | Package | Stock | Price | Application | Diagram |
| --- | --- | --- | --- | --- | --- | --- | --- | --- |
| **L1** | **[C19268674](https://jlcpcb.com/partdetail/C19268674)** | **CYA1265-100UH** | 100µH 4.5A  | SMD,13.8x12.8mm | **2763** | **$0.378** | U2 Energy Storage | [D2](/docs/inbox/circuit-diagrams#diagram2-usb-pd-15v--135v-buck-converter-lm2596s-adj-1)  |
| **L2** | **[C19268674](https://jlcpcb.com/partdetail/C19268674)** | **CYA1265-100UH** | 100µH 4.5A  | SMD,13.8x12.8mm | **2763** | **$0.378** | U3 Energy Storage | [D3](/docs/inbox/circuit-diagrams#diagram3-15v--75v-buck-converter-lm2596s-adj-2-u3) |
| **L3** | **[C19268674](https://jlcpcb.com/partdetail/C19268674)** | **CYA1265-100UH** | 100µH 4.5A  | SMD,13.8x12.8mm | **2763** | **$0.378** | U4 Energy Storage | [D4](/docs/inbox/circuit-diagrams#diagram4-15v---135v-inverting-buck-boost-lm2596s-adj-u4) |

#### Diodes

| Symbol | Part Number | Manufacturer Part Number | Description | Package | Stock | Price | Application | Diagram |
| --- | --- | --- | --- | --- | --- | --- | --- | --- |
| **D1** | **[C8678](https://jlcpcb.com/partdetail/C8678)** | **SS34** | 3A 40V Schottky | SMA | **1,859,655** | **$0.012** | U2 Freewheeling | [D2](/docs/inbox/circuit-diagrams#diagram2-usb-pd-15v--135v-buck-converter-lm2596s-adj-1)  |
| **D2** | **[C8678](https://jlcpcb.com/partdetail/C8678)** | **SS34** | 3A 40V Schottky | SMA | **1,859,655** | **$0.012** | U3 Freewheeling | [D3](/docs/inbox/circuit-diagrams#diagram3-15v--75v-buck-converter-lm2596s-adj-2-u3) |
| **D3** | **[C8678](https://jlcpcb.com/partdetail/C8678)** | **SS34** | 3A 40V Schottky | SMA | **1,859,655** | **$0.012** | U4 Freewheeling | [D4](/docs/inbox/circuit-diagrams#diagram4-15v---135v-inverting-buck-boost-lm2596s-adj-u4) |

#### Feedback Resistors (Basic Parts)

| Symbol | Part Number | Value | Description | Package | Price | Application | Diagram |
| --- | --- | --- | --- | --- | --- | --- | --- |
| **R1** | **[C25804](https://jlcpcb.com/partdetail/C25804)** | **10kΩ**  | ±1% 100mW | 0603 | **$0.0005** | U2 FB Upper | [D2](/docs/inbox/circuit-diagrams#diagram2-usb-pd-15v--135v-buck-converter-lm2596s-adj-1)  |
| **R2** | **[C21190](https://jlcpcb.com/partdetail/C21190)** | **1kΩ** | ±1% 100mW | 0603 | **$0.0005** | U2 FB Lower | [D2](/docs/inbox/circuit-diagrams#diagram2-usb-pd-15v--135v-buck-converter-lm2596s-adj-1)  |
| **R3** | **[C23186](https://jlcpcb.com/partdetail/C23186)** | **5.1kΩ** | ±1% 100mW | 0603 | **$0.0005** | U3 FB Upper | [D3](/docs/inbox/circuit-diagrams#diagram3-15v--75v-buck-converter-lm2596s-adj-2-u3) |
| **R4** | **[C21190](https://jlcpcb.com/partdetail/C21190)** | **1kΩ** | ±1% 100mW | 0603 | **$0.0005** | U3 FB Lower | [D3](/docs/inbox/circuit-diagrams#diagram3-15v--75v-buck-converter-lm2596s-adj-2-u3) |
| **R5** | **[C25804](https://jlcpcb.com/partdetail/C25804)** | **10kΩ**  | ±1% 100mW | 0603 | **$0.0005** | U4 FB Upper | [D4](/docs/inbox/circuit-diagrams#diagram4-15v---135v-inverting-buck-boost-lm2596s-adj-u4) |
| **R6** | **[C21190](https://jlcpcb.com/partdetail/C21190)** | **1kΩ** | ±1% 100mW | 0603 | **$0.0005** | U4 FB Lower | [D4](/docs/inbox/circuit-diagrams#diagram4-15v---135v-inverting-buck-boost-lm2596s-adj-u4) |

#### Electrolytic Capacitors

| Symbol  | Part Number | Specification | Package | Stock | Price | Application | Diagram |
| --- | --- | --- | --- | --- | --- | --- | --- |
| **C3**  | **[C2983319](https://jlcpcb.com/partdetail/C2983319)** | **470µF 25V** | D8xL10.5mm  | **46,748** | **$0.04**  | U2 Output Filter | [D2](/docs/inbox/circuit-diagrams#diagram2-usb-pd-15v--135v-buck-converter-lm2596s-adj-1)  |
| **C4**  | **[C46550400](https://jlcpcb.com/partdetail/C46550400)** | **470µF 16V ±20%** | D6.3xL7.7mm | **23,331** | **$0.02**  | U3 Output Filter | [D3](/docs/inbox/circuit-diagrams#diagram3-15v--75v-buck-converter-lm2596s-adj-2-u3) |
| **C5**  | **[C22383804](https://jlcpcb.com/partdetail/C22383804)** | **100µF 25V ±20%** | D6.3xL7.7mm | **43,359** | **$0.019** | U2 Input Bulk | [D2](/docs/inbox/circuit-diagrams#diagram2-usb-pd-15v--135v-buck-converter-lm2596s-adj-1)  |
| **C7**  | **[C22383804](https://jlcpcb.com/partdetail/C22383804)** | **100µF 25V ±20%** | D6.3xL7.7mm | **43,359** | **$0.019** | U3 Input Bulk | [D3](/docs/inbox/circuit-diagrams#diagram3-15v--75v-buck-converter-lm2596s-adj-2-u3) |
| **C9**  | **[C22383806](https://jlcpcb.com/partdetail/C22383806)** | **100µF 50V** | D6.3xL7.7mm | **8,337**  | **TBD** | U4 Input Bulk | [D4](/docs/inbox/circuit-diagrams#diagram4-15v---135v-inverting-buck-boost-lm2596s-adj-u4) |
| **C11** | **[C2983319](https://jlcpcb.com/partdetail/C2983319)** | **470µF 25V** | D8xL10.5mm  | **46,748** | **$0.04**  | U4 Output Filter | [D4](/docs/inbox/circuit-diagrams#diagram4-15v---135v-inverting-buck-boost-lm2596s-adj-u4) |

#### Ceramic Capacitors (DC-DC Stage)

| Symbol  | Part Number | Specification | Package | Stock | Price | Application | Diagram |
| --- | --- | --- | --- | --- | --- | --- | --- |
| **C6**  | **[C49678](https://jlcpcb.com/partdetail/C49678)** | **100nF 50V X7R** | 0805 | **23,309,869** | **$0.0021** | U2 Input Decoupling | [D2](/docs/inbox/circuit-diagrams#diagram2-usb-pd-15v--135v-buck-converter-lm2596s-adj-1)  |
| **C8**  | **[C49678](https://jlcpcb.com/partdetail/C49678)** | **100nF 50V X7R** | 0805 | **23,309,869** | **$0.0021** | U3 Input Decoupling | [D3](/docs/inbox/circuit-diagrams#diagram3-15v--75v-buck-converter-lm2596s-adj-2-u3) |
| **C10** | **[C49678](https://jlcpcb.com/partdetail/C49678)** | **100nF 50V X7R** | 0805 | **23,309,869** | **$0.0021** | U4 Input Decoupling | [D4](/docs/inbox/circuit-diagrams#diagram4-15v---135v-inverting-buck-boost-lm2596s-adj-u4) |
| **C31** | **[C1710](https://jlcpcb.com/partdetail/C1710)** | **22nF 50V X7R**  | 0805 | **Rich Stock** | **$0.002**  | U2 Feedback Compensation | [D2](/docs/inbox/circuit-diagrams#diagram2-usb-pd-15v--135v-buck-converter-lm2596s-adj-1)  |
| **C32** | **[C1710](https://jlcpcb.com/partdetail/C1710)** | **22nF 50V X7R**  | 0805 | **Rich Stock** | **$0.002**  | U3 Feedback Compensation | [D3](/docs/inbox/circuit-diagrams#diagram3-15v--75v-buck-converter-lm2596s-adj-2-u3) |
| **C33** | **[C1710](https://jlcpcb.com/partdetail/C1710)** | **22nF 50V X7R**  | 0805 | **Rich Stock** | **$0.002**  | U4 Feedback Compensation | [D4](/docs/inbox/circuit-diagrams#diagram4-15v---135v-inverting-buck-boost-lm2596s-adj-u4) |

**Note on C31/C32/C33:** These capacitors are not available in EasyEDA's symbol database. Use KiCad's built-in `Device:C` symbol paired with the `C0805.kicad_mod` footprint. This is standard practice for passive components in JLCPCB PCBA projects.

**Stage 2 Subtotal: TBD** (pending inductor/capacitor selection)

### Stage 3: Linear Regulators (LM7812/7805/7912)

#### Regulator ICs

| Symbol | Part Number | Manufacturer Part Number | Description | Package | Stock | Price | Application | Diagram |
| --- | --- | --- | --- | --- | --- | --- | --- | --- |
| **U6** | **[C13456](https://jlcpcb.com/partdetail/C13456)** | **[L7812CD2T-TR](./l7812cv)** | +12V 1.5A | TO-263-2  | **40,204**  | **$0.11** | +12V Output | [D5](/docs/inbox/circuit-diagrams#diagram5-135v--12v-linear-regulator-l7812-u6) |
| **U7** | **[C86206](https://jlcpcb.com/partdetail/C86206)** | **[L7805ABD2T-TR](./l7805abd2t)** | +5V 1.5A | TO-263-2  | **272,379** | **$0.11** | +5V Output  | [D6](/docs/inbox/circuit-diagrams#diagram6-75v--5v-linear-regulator-l7805-u7) |
| **U8** | **[C94173](https://jlcpcb.com/partdetail/C94173)** | **[CJ7912](./cj7912)** | -12V 1.5A | TO-252-2L | **3,386** | **$0.11** | -12V Output | [D7](/docs/inbox/circuit-diagrams#diagram7--135v---12v-linear-regulator-cj7912-u8) |

#### Input Capacitors (470nF) - Basic Parts

| Symbol  | Part Number | Specification | Package | Stock | Price | Application | Diagram |
| --- | --- | --- | --- | --- | --- | --- | --- |
| **C15** | **[C1623](https://jlcpcb.com/partdetail/C1623)** | **470nF 25V X7R** | 0603 | **1,100,473** | **$0.0036** | U7 Input Filter | [D6](/docs/inbox/circuit-diagrams#diagram6-75v--5v-linear-regulator-l7805-u7) |
| **C16** | **[C1623](https://jlcpcb.com/partdetail/C1623)** | **470nF 25V X7R** | 0603 | **1,100,473** | **$0.0036** | U8 Input Filter | [D7](/docs/inbox/circuit-diagrams#diagram7--135v---12v-linear-regulator-cj7912-u8) |

#### Output Capacitors (0.1µF) - Basic Parts

| Symbol  | Part Number | Specification | Package | Stock | Price | Application | Diagram |
| --- | --- | --- | --- | --- | --- | --- | --- |
| **C17** | **[C49678](https://jlcpcb.com/partdetail/C49678)** | **100nF 50V X7R** | 0805 | **23,309,869** | **$0.0021** | U6 Output Filter | [D5](/docs/inbox/circuit-diagrams#diagram5-135v--12v-linear-regulator-l7812-u6) |
| **C18** | **[C49678](https://jlcpcb.com/partdetail/C49678)** | **100nF 50V X7R** | 0805 | **23,309,869** | **$0.0021** | U7 Output Filter | [D6](/docs/inbox/circuit-diagrams#diagram6-75v--5v-linear-regulator-l7805-u7) |
| **C19** | **[C49678](https://jlcpcb.com/partdetail/C49678)** | **100nF 50V X7R** | 0805 | **23,309,869** | **$0.0021** | U8 Output Filter | [D7](/docs/inbox/circuit-diagrams#diagram7--135v---12v-linear-regulator-cj7912-u8) |
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

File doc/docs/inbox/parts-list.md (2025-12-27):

---
sidebar_position: 4
---

# Bill of Materials (BOM)

Complete parts configuration using JLCPCB SMT service.

## Power Supply Specifications

- **+12V**: 1200mA (actual 1.2A support)
- **-12V**: 800mA (actual 1A support)
- **+5V**: 500mA (actual 1.2A support)
- **Input**: USB-C PD 15V 3A
- **Efficiency**: Approximately 75-80%
- **Ripple**: \<1mVp-p (final output)

## Complete Parts Configuration by Stage
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

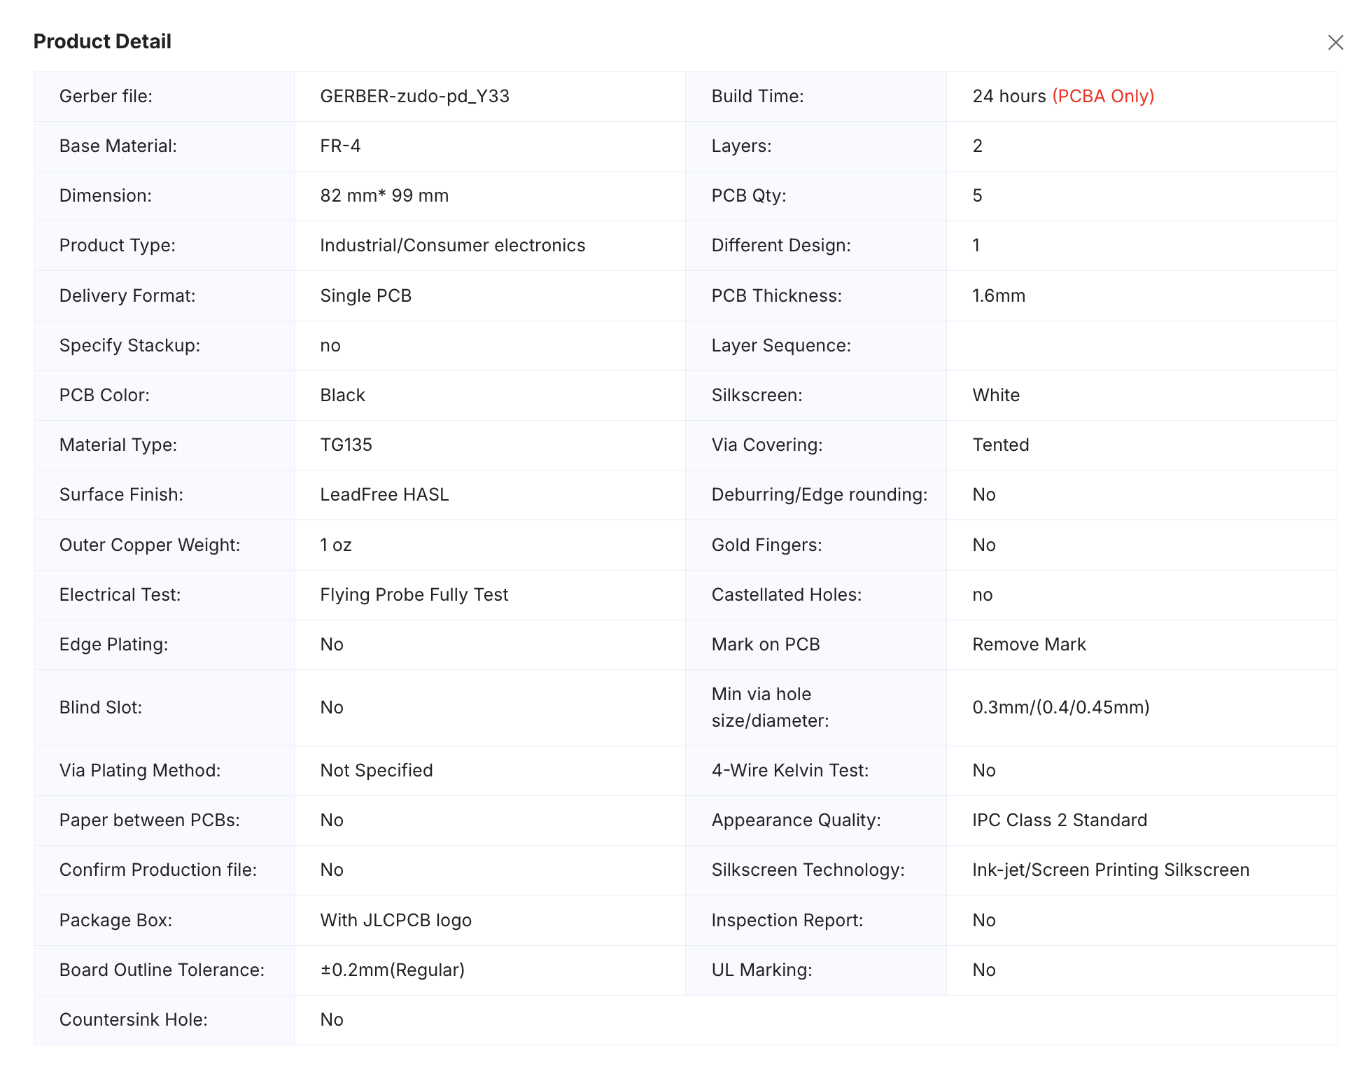
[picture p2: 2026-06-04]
jlcpcb-order-snapshots/v0_3_0/from-order-detail/product-detail.png

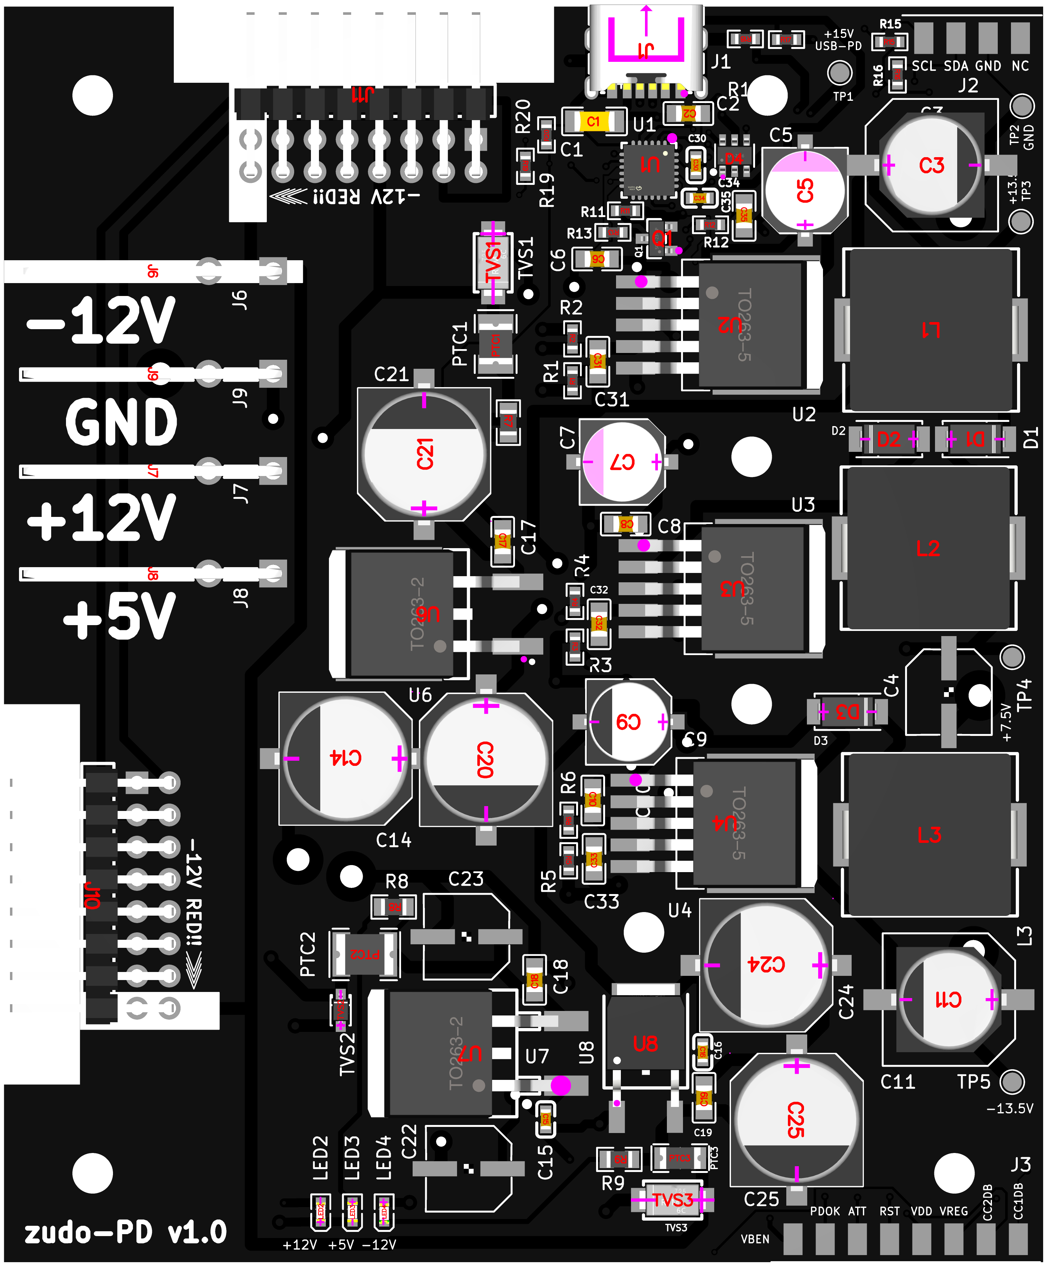
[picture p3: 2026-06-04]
jlcpcb-order-snapshots/v0_3_0/from-order-detail/layout.png

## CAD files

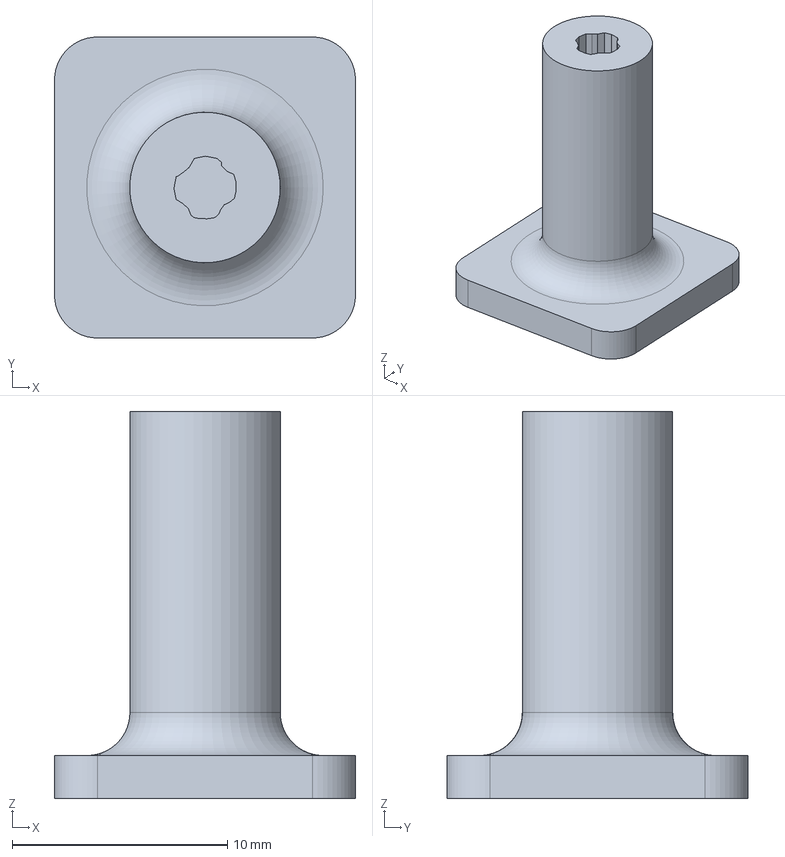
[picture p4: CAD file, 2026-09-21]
3dp-files/adhesive-leg/generated/adhesive-leg-18mm-m3.step
14.0 x 14.0 x 18.0 mm

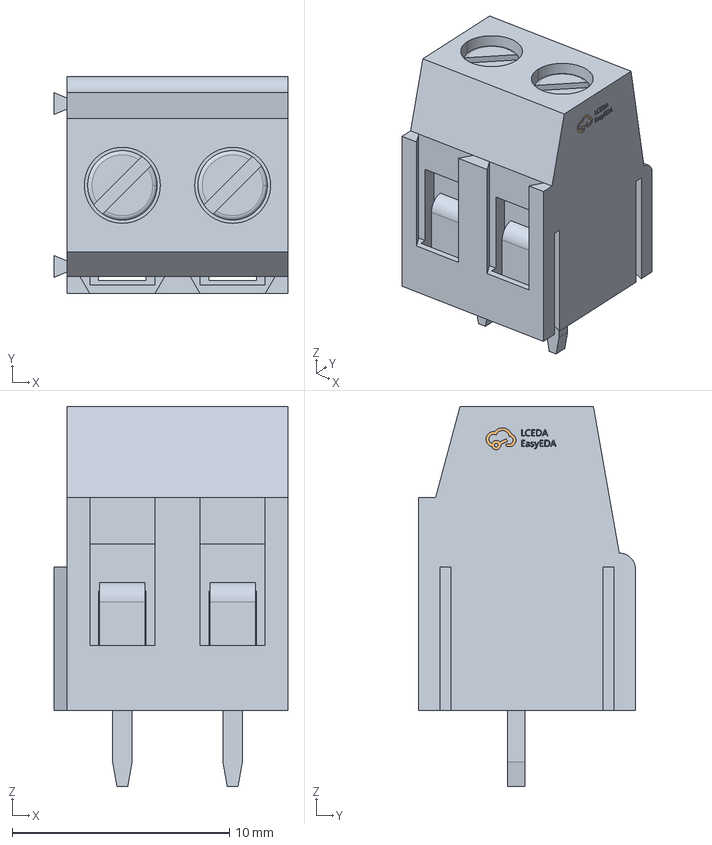
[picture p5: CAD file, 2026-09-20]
manufacturing/releases/corner-support-review/mechanical/assembly/models/WJ500V-5.08-2P_C8465.step
10.8 x 10.0 x 17.5 mm

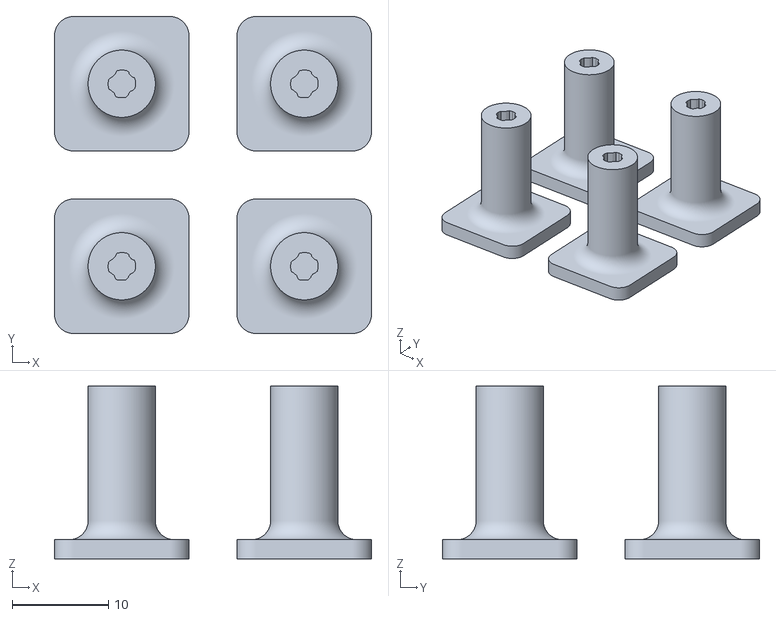
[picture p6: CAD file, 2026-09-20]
3dp-files/adhesive-leg/generated/adhesive-leg-18mm-m3-4x.stl
33.0 x 33.0 x 18.0

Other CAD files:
3dp-files/adhesive-leg/generated/adhesive-leg-18mm-m3.stl

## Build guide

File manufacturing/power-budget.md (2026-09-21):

# Renewal power-chain screening

The machine-readable report is `power-budget.json`; regenerate it with
`python3 scripts/pcb/calculate-power-budget.py`. It separates the rated output target
(26.5 W total) from prototype qualification. The negative divider selects R5 RT0603BRD0710K5L (C861077) and R6 RT0603BRD071KL
(C110776), both 0.1%. The report retains the earlier alternatives for comparison and
checks whether those exact identities have reached the current schematic spec. The
positive converter selects AP63201; its high-duty low-line operation and whole-chain
qualification remain open.

For the retained inverting LM2596 stage, a 10.5 kΩ / 1 kΩ divider with both resistors
at 0.1% gives a nominal −14.145 V intermediate rail. Full-temperature reference and
opposed resistor tolerances give magnitudes of 13.545–14.747 V. U8 is now the adjustable LT3015 (the fixed −12 V orderables were out of stock), programmed by
R26 8.2 kΩ + R27 680 Ω over R28 1 kΩ, all 0.1%, to a nominal −12.054 V. Its full-temperature
−1.196 to −1.244 V reference, 0.35% opposed resistor tolerance/TCR and the 25 °C-only 200 nA
ADJ-bias limit give an output magnitude screen of 11.741–12.370 V, so the input requirement is
13.050 V including the 0.68 V maximum dropout. That leaves 0.495 V before rail ripple and wiring
loss. Including a 25 ppm/°C resistor TCR over a 100 °C excursion expands the
negative range to 13.484–14.814 V, retaining 0.433 V before ripple and wiring loss. The initial-tolerance comparison using a 10.6 kΩ top resistor (also 0.1%,
without the TCR addition) gives a nominal magnitude of 14.268 V and a lower bound
of 13.663 V, with slightly more dissipation.

The exact 100 µH inductor has a 4.5 A heat-rating current and an 8.5 A saturation
criterion; those are distinct manufacturer test conditions. The report evaluates
minimum inductance and oscillator frequency, maximum switch saturation and the new
SDT5A60SA-13 diode's 0.52 V maximum at 5 A / 25 °C, and a 14 V input screening
point. The catalog's 0.46 V is typical and is not used as the maximum. The updated
CCM duty calculation includes the inductor's maximum 25 °C winding resistance;
ripple copper loss is also included in the input-power screen. It includes both the
0.8 A load alone and a more conservative load with the LDO ground-current bracket,
sense current and feedback-divider current. At 14 V with the 0.883913 A intermediate-load screen, inductor RMS current is
2.040 A and peak current is 2.395 A, leaving 1.005 A below the 3.4 A minimum
switch-current limit. The conduction model gives 1.146 A input current and losses
of 0.770 W in the winding, 1.718 W in the switch and 0.460 W in diode forward
conduction. It omits hot winding resistance, core/switching/quiescent losses,
bias-dependent inductance, diode reverse leakage and measured transients, so these
figures are not upper bounds or measured efficiency. D3's 0.5 mA reverse-leakage
maximum is specified at 60 V / 25 °C; the 50 mA figure at 60 V / 125 °C is only
typical. Actual hot reverse loss requires measurement.

For the selected 10.5 kΩ divider, use the report's full-chain thermal screen:
14.814410 V negative intermediate magnitude includes the TCR allowance, and the
0.813875 A LDO output load includes the indicator and the 1.22 mA-class feedback divider. Against the
programmed LT3015's 11.741 V minimum output magnitude screen, series-pass loss is about 2.502 W. Its published
1.5 A/dropout ground-current maximum of 70 mA contributes another 1.037 W as a
conservative screening bracket, not an interpolated guarantee at the target load.
The resulting 3.539 W requires effective junction-to-ambient thermal resistance
below 24.020 °C/W at 40 °C ambient to remain below 125 °C.

The simpler initial-tolerance-only, 0.8 A load comparison remains in the JSON at
3.422 W and 24.841 °C/W; it omits the TCR and indicator additions and must not be
substituted for the full-chain screen. Filled copper areas are not thermal
qualification; actual layout, shared heat paths and temperature rise must be
verified. The 14 °C/W headline DD-Pak value uses a specific 2500 mm² test board
with copper on both sides.

The new regulator selection must satisfy output-capacitor requirements with exact
part evidence: LT3015 requires at least 10 µF effective capacitance and ESR no more
than 0.5 Ω; LT1963A requires at least 10 µF and ESR no more than 3 Ω. A nominal
capacitor value alone does not close ESR, bias, temperature or load-step stability.

The current protection pair is Board P D5 **Littelfuse SMAJ16A (C74561)** and
Board B D3 **Diodes SDT5A60SA-13 (C3024223)**. The prototype permits normal source
input of **15 V ±5%**, or 14.25–15.75 V. The TVS's 16 V standoff leaves only 0.25 V
above that normal high endpoint. **20 V is unsupported.**

First power and programming must use a current-limited **5 V-only source**, with
Board B disconnected. Resolve programming-jig voltage and VREG_2V7 pull-up loading,
then program and retain readback of the 15 V-only NVM policy before connecting any
15 V-capable PD source. An unknown factory configuration must not be allowed to
request 20 V from that source.

The new TVS's maximum 26 V clamp is specified at 15.4 A, a 10/1000 µs waveform and
25 °C. Adding the 14.814410 V negative-rail screen gives 40.814410 V. The resulting
conditioned margins are:

| Limit being compared | Margin at that table point |
| --- | ---: |
| STUSB4500 28 V absolute maximum | 2.000 V |
| Q1 30 V drain-source magnitude | 4.000 V |
| U4 45 V absolute maximum | 4.186 V |
| D3 60 V reverse rating | 19.186 V |
| C9 50 V bridge-capacitor rating | 9.186 V |
| 35 V / 50 V input-capacitor ratings | 9.000 V / 24.000 V |

The STUSB limit retains its documented mirror-source trust limitation. U4's 40 V
operating ceiling is exceeded at this conditioned event; the comparison does not
claim regulation through it. The ideal asserted Q1 gate voltage is −10.4 V at
26 V, but its transient waveform is not established. The 26 V table point is not
a universal ceiling at elevated temperature or in the installed circuit. The
published VBR temperature coefficient describes breakdown, not a formula for VC.
Clamp current, temperature, wiring inductance, switch-node ringing and actual
waveforms remain prototype qualification work.

The former SMAJ20A 32.4 V / SS34 40 V comparison is retained as **retired** evidence.
At the nominal 14.145 V negative rail it gave 46.545 V, exceeding the old U4/D3
limits; that historical arithmetic has not been reclassified as passing. The
current parts remove that specified table-point rating mismatch. They do not
establish complete surge qualification.

The LM2596 inverting startup can still demand about 4.5 A for at least 2 ms against
a 3 A PD contract. Neither the revised conduction model nor clean DRC demonstrates
that the assembled source starts and sustains the rated loads.

The positive AP63201 divider targets 13.44 V. With the published 0.792–0.808 V
reference, 158 kΩ/10 kΩ resistors, initial 0.1% tolerance and respective 50/25 ppm/°C
TCR over 65 °C, the arithmetic range is 13.220–13.662 V. At an assumed 14.0 V
board input the upper setpoint leaves 0.338 V for switch, winding and wiring drop.
This is a useful low-line acceptance constraint, not a guaranteed converter dropout
claim; the actual high-duty behavior and path losses must be checked.

The full-chain report also includes indicator and feedback-divider loads. Using
conservative higher-load ground-current brackets, the intermediate rails require
about 35.7 W before converter losses. At the assumed 14 V board input and 3 A
contract, this needs a weighted converter efficiency above about 85%. It is an
acceptance budget, not a proven efficiency. LDO dissipation screens are approximately
4.23 W on +12 V, 1.95 W on +5 V, and 3.52 W on −12 V; these include the ground-current
brackets and conditional output-voltage corners. At 40 °C ambient, the corresponding
effective θJA limits are approximately 20.1, 43.5, and 24.2 °C/W. Actual normal
losses may be lower; qualification must measure them with all rails loaded together.

The filled-layout report, `power-layout.json`, records the PCB hash, all 48 thermal
vias and the dedicated output traces. Its `negative_filled_zone_areas` entries give the actual U4/U8 areas for the
current PCB hash. Use those values when reviewing this report; footprint and
routing revisions can change filled area even when the zone rectangles are
unchanged. The earlier 1,280 mm²-per-side proposal is not an achieved-area claim.

U6 and U7 share the connected system-ground copper. That shared area cannot be
credited independently to each regulator as an isolated heatsink. The report
checks polygon connectivity, specified ground stitches, aggregate sampled ground
width and the largest individual run. Aggregate width is not one continuous strip;
neither area nor via count
establishes thermal resistance. Re-run the filled-layout check before regenerating
the budget after any PCB change; stale PCB hashes are rejected.

The current screw-terminal board retains the 110 × 85 mm outline and the same
rail targets. Its two top-side terminal blocks replace the four Fastons and printed
guard. This mechanical change does not establish electrical or thermal performance.
Use the current source-locked filled areas in the JSON reports; earlier layouts and
manufacturer single-device test boards cannot qualify this assembly's coupled
temperatures. Repeat full-load measurements with Board B front-down on its legs,
Board P in the front-side stack, and the final wiring and enclosure. Earlier
orientations do not establish cooling in this installed configuration.
The current PD translation and fourth independent corner support do not resolve
the HC-11 floor-height conflict: an 11 mm support is shorter than P's 12.7 mm
back substrate plane and the terminal drawing's 14.2 mm maximum. See
[the retained support record](../boards/board-b/supports/README.md). The selected
[18 mm printed-leg prototype](../3dp-files/adhesive-leg/README.md) addresses that
nominal height conflict. Its separate CAD verification does not qualify printing,
adhesive retention or thermal behavior. Check the actual accessory and enclosure
before treating the installed configuration as a thermal-test setup.

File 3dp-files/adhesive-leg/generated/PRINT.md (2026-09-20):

# Print the straight adhesive PCB legs

Units: mm. Import at 100% scale.

- adhesive-leg-18mm-m3.stl: one leg; print four copies.
- adhesive-leg-18mm-m3-4x.stl: four separate legs on one plate.

Place the broad flat bases on the bed, with the screw openings upward. Use the
material and hole-compensation settings that worked for the tested rail.
No supports are needed.

Each leg is 18 mm high, with a 14 × 14 × 2 mm base and a straight Ø7 mm pole.
The hole preserves the exact 27-vertex rail profile, stopping at 4.5 mm depth.
There is no lower cavity and no top taper. Material below the hole is solid.

Use M3 × 5 mm non-countersunk screws from the PCB back. A 1.6 mm PCB leaves
3.4 mm insertion and 1.1 mm nominal space to the blind floor. Alternatively,
M3 × 6 mm with a washer at least 0.5 mm thick gives at most 3.9 mm insertion.
The previous M3 × 8 mm screws are too long for this revision.

Fit all four legs before applying adhesive to the flat undersides. Existing PCB
holes remain nominally 3.0 mm; confirm the actual M3 screws pass freely through
them. The four bases need 116 × 91 mm of mounting space, extending 3 mm beyond
each PCB edge. Printed retention and adhesive grip need the actual hardware check.

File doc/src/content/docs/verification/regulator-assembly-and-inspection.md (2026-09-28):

---
title: Regulator Assembly, Soldering, and Inspection
sidebar_position: 103
description: Assembly-critical warnings, soldering profiles, inspection points and a pre-power checklist for the Board B linear regulator stage - including the negative-rail capacitor polarity trap.
---

<Note title="Historical board procedure">

This procedure describes the previous hardware and may name retired parts, nets,
pin assignments or export assumptions. Use the [current architecture](/docs/architecture/),
[prototype bring-up procedure](/docs/verification/renewal-bring-up/) and
[current manufacturing workflow](/docs/project/jlcpcb-package/) for renewed boards.

</Note>

Assembly procedure for the Board B linear regulator stage: U6 (L7812CD2T-TR, C13456),
U7 (L7805ABD2T-TR, C86206) and U8 (CJ7912, C94173), plus their surrounding
capacitors.

Two of the traps below have destroyed hardware in other people's projects and will
destroy it here. Read them before touching a soldering iron.

## Trap 1: CJ7912 pin 1 is GND, not INPUT

<Danger title="Pin 1 = GND, not INPUT">
Negative regulators do **not** share the 78xx pin order. On the CJ7912 in TO-252-2L:

- **Pin 1 = GND (common)**
- **Pin 2 = INPUT (-13.5V), at the tab position**
- **Pin 3 = OUTPUT (-12V)**

This is recorded as `fact-cj7912-pinout`, primary-source confirmed against the
datasheet package figure and typical-application figure, and it matches the Board B
baseline (`U8.1` on `GND`, `U8.2` on `/DC-DC Conversion/-13.5V OUT`, `U8.3` on
`Net-(U8-OUT)`) with no remapping.

Assuming pin 1 is the input - the reflex if you have only ever wired 78xx positives -
gets you wrong connections and no output.
</Danger>

Prevention:

- Label the pins explicitly on the schematic: write "Pin 1 = GND", not just "Pin 1".
- Keep a reference-designator-to-pin table next to the symbol.
- Use a distinct schematic symbol for negative regulators so the eye does not
  auto-complete the 78xx layout.

Note that the tab is the pin 2 position, so the U8 tab is at **-13.5V**, not at
ground and not at the -12V output. See
[Linear Regulator PCB Layout and Thermal Design](../project/linear-regulator-layout.md#terminal-functions).

## Trap 2: negative-rail electrolytic polarity is reversed

<Danger title="On the -12V chain, the capacitor's positive terminal goes to GND">
For the capacitors on the negative rail, ground is the **more positive** node. So:

- **Positive terminal to GROUND (0V)**
- **Negative terminal to the negative voltage**

This is the opposite of every capacitor on the +12V and +5V chains.
</Danger>

```
Correct polarity for the negative rail:

C24 (input, 470µF 35V):
         ┌─────────┐
  GND ───┤+       -├─── -13.5V
         └─────────┘

C25 (output, 470µF 35V):
         ┌─────────┐
  GND ───┤+       -├─── -12V
         └─────────┘
```

Installing one of these backwards causes immediate capacitor failure, possibly a
burst electrolytic, regulator damage, and board contamination.

Prevention:

1. Put clear polarity markings on the silkscreen, and make the negative-rail parts
   visually distinct from the positive-rail parts.
2. Carry an assembly note in the BOM for C24 and C25.
3. Check polarity with a DMM before applying power.

The ceramics on the same nets - C16 (470 nF, input) and C19 (100 nF, output) - are
non-polarized, so they carry no orientation risk. The distances still matter: keep
the ceramic within 5 mm of the pin it decouples and the electrolytic within 10 mm.

## Trap 3: TVS3 orientation on the -12V rail

TVS3 (SMAJ15A, unidirectional) sits on the -12V output. Its orientation is locked by
`dec-tvs3-orientation-lock` in `scripts/schgen/decisions.json`:

- **Cathode to GND (0V)**
- **Anode to the -12V rail**

Fit it the other way round and the part is forward-biased at -12V - a dead short
through one diode drop across the rail.

<Warning title="Older project pages state the opposite">
The legacy CJ7912 component page tells you to wire the negative-rail TVS with the
cathode to the negative voltage and the anode to GND. That contradicts the locked
decision and is not carried forward here. The locked orientation above is the one to
build. The Board B net table agrees: it places `TVS3.1` on `GND` and `TVS3.2` on the
`-12V rail`, annotated in the spec module as the locked cathode-to-GND orientation.
On the physical part, `fact-smaj15a-polarity` records that the colour band marks the
cathode end.
</Warning>

## Soldering

### Reflow (recommended for production)

- Peak temperature: 260 °C maximum
- Time above 220 °C: 60-90 seconds
- Solder paste: SAC305 or a comparable lead-free alloy
- Stencil thickness: 0.125 mm (5 mil)

### Hand soldering

- Iron temperature: 350 °C maximum
- **U8 (CJ7912)**: solder pin 1 (GND) first as a mechanical reference, then pin 2
  (INPUT), then the tab.
- **U6, U7 (D2PAK)**: solder the two leads first, then the tab.
- Apply solder to the tab from the component side.
- Get real thermal contact between the tab and its pad - the tab is the entire heat
  path on these packages, and a partly-wetted tab turns a working thermal budget into
  a failing one.

## Inspection

After assembly, check:

1. **Electrolytic capacitor polarity** - critical on the negative rail; verify the
   positive terminal is at GND for C24 and C25.
2. **Pin solder joints** - smooth fillet, no bridges.
3. **Tab solder joint** - full coverage, no visible voids.
4. **Component alignment** - centred on the pads.
5. **No cold joints** - a good joint is shiny and smooth.
6. **Thermal via filling** - solder should wick into the vias.

## Pre-power checklist

- [ ] C24 polarity: positive terminal to GND, negative terminal to -13.5V
- [ ] C25 polarity: positive terminal to GND, negative terminal to -12V
- [ ] C20, C21 polarity: positive terminal to the positive rail (the normal case)
- [ ] U8 orientation: pin 1 to GND, pin 2 (tab) to -13.5V, pin 3 to the -12V output
- [ ] TVS3 orientation: cathode to GND, anode to -12V
- [ ] Visual inspection complete
- [ ] Continuity test: GND to U8 pin 1
- [ ] Resistance test: no short between -12V and GND
- [ ] Resistance test: no short between -13.5V and GND
- [ ] Resistance test: no short between +12V and GND, or +5V and GND

## Common mistakes

### Reversed electrolytic capacitors

**Problem**: installing a negative-rail electrolytic (C24 or C25) with the polarity
that would be correct on a positive rail.
**Consequence**: capacitor failure or rupture, regulator damage.
**Prevention**: large silkscreen warnings, DMM check before power-up, and the
checklist above.

### Confusing positive and negative regulator pinouts

**Problem**: assuming pin 1 is the INPUT because that is how the 78xx positives are
laid out.
**Consequence**: wrong connections, no output.
**Prevention**: see [Trap 1](#trap-1-cj7912-pin-1-is-gnd-not-input).

### Insufficient dropout voltage

**Problem**: feeding the regulator an input that is not far enough from the output -
for example -12V in for a -12V out.
**Consequence**: no regulation; the output simply follows the input.
**Prevention**: the magnitude of VIN must exceed the magnitude of VOUT by the
dropout voltage plus margin. `fact-cj7912-vi-guarantee-band` records that the CJ7912
output band is only guaranteed for an input between -14.5V and -27V, and the design
runs it at **-13.5V** - already outside the guaranteed band, which is why
`fact-cj7912-rail-headroom` carries a **NEEDS BENCH** verdict. Confirm the DC-DC
setpoint on the bench and treat a marginal -12V as a headroom problem before
suspecting the regulator.

### Shared copper pour between rails

**Problem**: letting the -12V copper touch the +12V copper.
**Consequence**: a direct short between rails, catastrophic.
**Prevention**: a separate pour per rail, at least 2 mm of clearance between pours at
different potentials, and a DRC run to prove it. The U8 tab island at -13.5V is the
easiest one to get wrong, because it looks like a ground pour and is not.

## Related

- [Linear Regulator PCB Layout and Thermal Design](../project/linear-regulator-layout.md)
- [Power Rail Bench Test Procedure](./power-rail-bench-test.md)
- [Board B - synth power conversion](../overview/board-b-synth-power.md)

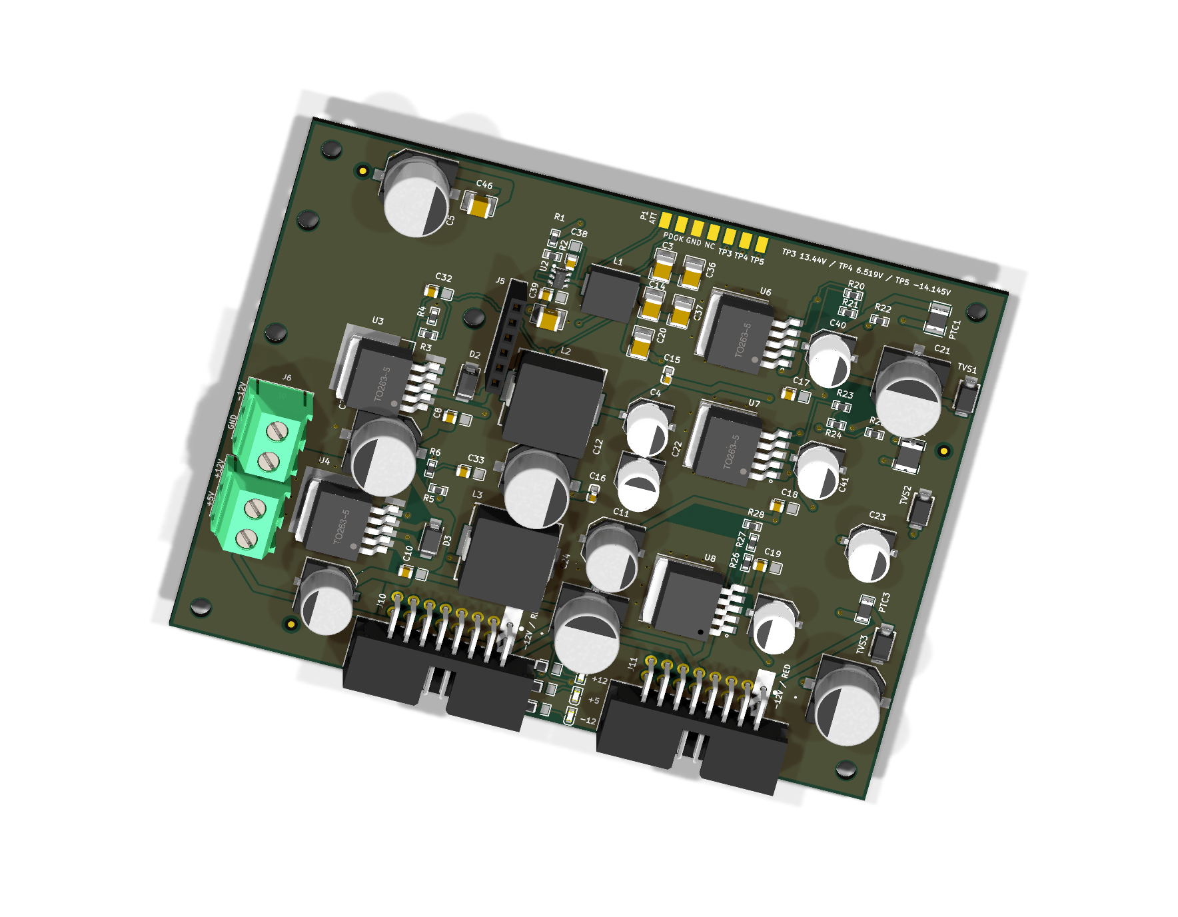
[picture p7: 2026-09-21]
manufacturing/releases/corner-support-review/board-b/3d-top.png

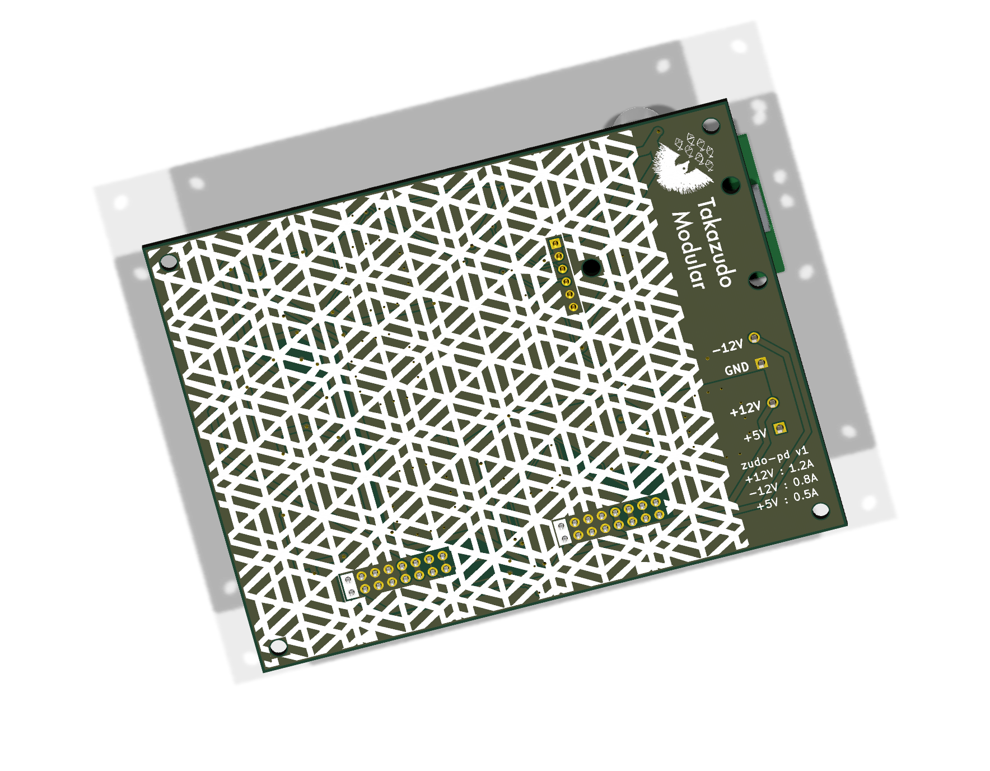
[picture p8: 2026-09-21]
manufacturing/releases/corner-support-review/mechanical/assembly/bottom.png

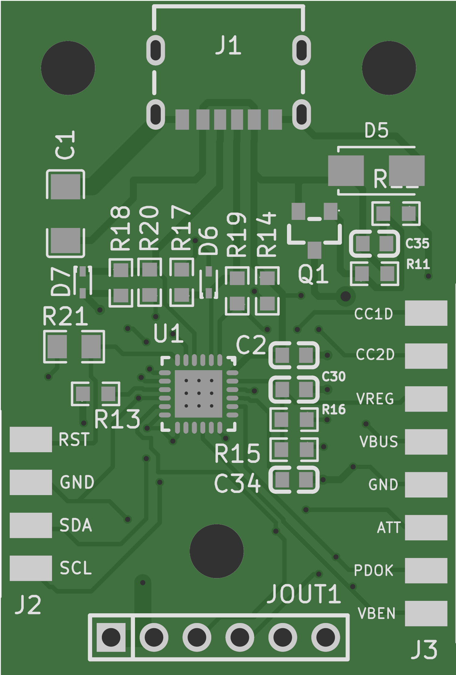
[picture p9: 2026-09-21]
manufacturing/releases/corner-support-review/board-p/gerber-top.png

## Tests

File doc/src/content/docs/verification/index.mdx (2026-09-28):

---
title: Verification
sidebar_position: 1
description: Bring-up, assembly and bench procedures with explicit evidence limits.
---

These pages document procedures for current bring-up and earlier Board B hardware.
Use [release readiness](../architecture/release-readiness.md) to check current
manufacturing status. A procedure by itself does not establish measured
qualification.

## Procedures

- [Renewal prototype bring-up](./renewal-bring-up.md) covers staged checks for the
  current Board P and redesigned Board B.
- [Regulator assembly and inspection](./regulator-assembly-and-inspection.md)
  documents the earlier linear-regulator stage assembly checklist.
- [Power rail bench test](./power-rail-bench-test.md) describes bench tests for the
  earlier Board B regulator stage.

<CategoryNav category="verification" />

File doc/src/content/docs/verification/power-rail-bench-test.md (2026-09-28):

---
title: Power Rail Bench Test Procedure
sidebar_position: 104
description: Pre-power inspection, staged power-up, load regulation, thermal, ripple and transient tests for the +12V, +5V and -12V linear regulator outputs.
---

<Note title="Historical board procedure">

This procedure describes the previous hardware and may name retired parts, nets,
pin assignments or export assumptions. Use the [current architecture](/docs/architecture/),
[prototype bring-up procedure](/docs/verification/renewal-bring-up/) and
[current manufacturing workflow](/docs/project/jlcpcb-package/) for renewed boards.

</Note>

Bench procedure for validating the Board B linear regulator stage once a board is
assembled: U6 (+12V, L7812CD2T-TR), U7 (+5V, L7805ABD2T-TR) and U8 (-12V, CJ7912).

Run [Regulator Assembly, Soldering, and Inspection](./regulator-assembly-and-inspection.md)
first. Everything below assumes that checklist has passed.

<Note>
This page covers the regulator stage only. For the full board bring-up sequence
including the USB-PD negotiation, see the
[bring-up test procedure](../inbox/v3-bringup-test-procedure.md).
</Note>

## 1. Pre-power inspection

Before applying any power:

1. **Capacitor polarity**

   - Check C24 and C25 (the -12V chain electrolytics) with a DMM in diode mode.
   - The positive terminal must sit at GND potential; the negative terminal goes to
     the negative rail. This is reversed relative to C20/C21 on the +12V chain.

2. **Visual inspection**

   - No solder bridges
   - Good solder coverage on every tab
   - Correct IC orientation, especially U8 (pin 1 = GND)
   - All components present

3. **Resistance checks** - with the board unpowered, confirm no short from any of
   +13.5V, +12V, +7.5V, +5V, -13.5V or -12V to GND.

## 2. Staged power-up

Bring each rail up gradually rather than switching the supply on at the target
voltage.

1. Start below the regulation threshold - for the -12V chain, around -10V in.
2. Increase to the design input in steps: +13.5V (U6), +7.5V (U7), -13.5V (U8).
3. Watch for smoke or smell at every step.
4. Feel for a package heating faster than the load explains - that is thermal
   runaway, and it means stop.

## 3. No-load output check

| Position | Input  | Expected output | Source |
| --- | --- | --- | --- |
| U6 | +13.5V | 11.4V - 12.6V | `fact-l7812cd2t-vout-band` |
| U7 | +7.5V  | 4.8V - 5.2V | `fact-l7805abd2t-vout-band`|
| U8 | -13.5V | -11.4V to -12.6V | `fact-cj7912-vi-guarantee-band` |

Also measure the quiescent current at no load. The CJ7912 specifies 3 mA maximum at
25 °C (`fact-cj7912-iq-max`); a reading well above that points at a fault, not at
normal quiescent draw.

<Warning title="U8 is running outside its guaranteed input band">
`fact-cj7912-vi-guarantee-band` records that the CJ7912 output band is guaranteed
only for an input between -14.5V and -27V. The design feeds it **-13.5V**, which is
1.0V short of that, and only 0.4V above the 1.1V typical dropout at 1A. So a -12V
reading that drifts under load is a **headroom** result, not necessarily a bad part.
Record the actual DC-DC output voltage alongside every -12V measurement, and treat
`fact-cj7912-rail-headroom` (verdict NEEDS BENCH) as the thing this test is
answering.
</Warning>

## 4. Load regulation

For each rail, connect a variable load and sweep it.

**+12V (U6)** - sweep 0 to 1.2A:

| Load  | Expect |
| ----- | --- |
| 0 mA  | within the 11.4V - 12.6V band |
| 600 mA| within the band |
| 1.2 A | within the band |

**+5V (U7)** - sweep 0 to 0.5A:

| Load | Expect |
| --- | --- |
| 0 mA | within the 4.8V - 5.2V band |
| 250 mA | within the band |
| 500 mA | within the band |

Verify the total drop from no-load to full-load stays under 50 mV.

**-12V (U8)** - sweep 0 to 0.8A:

| Load | Expect |
| --- | --- |
| 0 mA | within the -11.4V to -12.6V band  |
| 400 mA | within the band |
| 800 mA | within the band |

Verify the variation from no-load to full-load stays under 120 mV.

Record the input voltage at every point. A rail that sags at high current when its
input has also sagged is a DC-DC stage problem, not an LDO problem.

## 5. Thermal

<Warning title="Do not test against an assumed junction temperature">
Older project pages quoted expected case temperatures ("should be about 69 °C",
"should be about 73 °C") derived from thermal resistances that do not match the
recorded datasheet facts. Those predictions are wrong and are not carried forward.
Measure the case temperature, convert it to a junction estimate, and compare that
against the junction limit - do not compare it against a predicted number.
</Warning>

Procedure, per position:

1. Apply the rated load - 1.2A on +12V, 0.5A on +5V, 0.8A on -12V - for 30 minutes.
2. Measure the case temperature with a thermal camera or a thermocouple on the tab.
3. Record the ambient temperature at the same time.
4. Convert to a junction estimate: `Tj ≈ Tcase + P_diss × thetaJC`.
5. Compare against the junction limit.

| Position | P_diss | thetaJC | Tj estimate | Tcase limit for Tj ≤ 125 °C |
| --- | --- | --- | --- | --- |
| U6 | 1.80 W | 3 °C/W (`fact-l7812cd2t-rthjc`)  | Tcase + 5.4 °C  | 119.6 °C |
| U7 | 1.25 W | 3 °C/W (`fact-l7805abd2t-rthjc`) | Tcase + 3.8 °C  | 121.2 °C |
| U8 | 1.20 W | **not published** | not derivable | see below |

`fact-cj7912-rthja` is the only thermal-resistance figure the CJ7912 datasheet
publishes - **there is no junction-to-case value**, so no case-to-junction conversion
is available for U8. Treat the measured case temperature as the raw datum, keep it
well clear of the 125 °C junction limit, and record it as the bench evidence that
`fact-cj7912-tj-rise-full-load` (verdict NEEDS BENCH) is waiting on.

Also record the measured case temperature and ambient for U6 and U7. Together with
the dissipation they give the **effective thetaJA of the actual board**, which is the
number the [thermal budget](../project/linear-regulator-layout.md#thermal-budget) needs and
which the datasheet does not supply for either part.

Finally: confirm thermal shutdown does not trigger during the 30-minute soak.

## 6. Ripple and noise

1. Set the oscilloscope to AC coupling with the 20 MHz bandwidth limit on.
2. Use a short ground spring or a coax probe - a long ground lead manufactures
   ripple that is not there.
3. Measure each output against GND at its rated load.
4. Target: under 5 mVp-p, with under 1 mVp-p as the design goal for the two-stage
   DC-DC plus LDO architecture.
5. Watch for oscillation or instability rather than just ripple amplitude.

<Note>
On the -12V rail, `fact-cj7912-esr-window-not-specified` records that the CJ7912
datasheet gives no output-capacitor ESR bounds, minimum capacitance, or stability
window at all. Stability of U8 with the C19/C25 output network therefore cannot be
predicted from the datasheet - this measurement is the only evidence that exists.
</Note>

## 7. Transient response

For each rail, drive a step with an electronic load and watch the output:

| Rail | Step | Dip limit | Recovery |
| ---- | --- | --- | --- |
| +12V | 0 to 1.2A | 250 mV | 100 µs |
| +5V  | 0 to 0.5A | 250 mV | 100 µs |
| -12V | 0 to 0.8A | 200 mV | 100 µs |

Check for ringing or overshoot on the recovery edge, not just the dip depth.

The +5V and -12V limits are carried over from the per-part procedures on the legacy
component pages. No separate figure was ever recorded for +12V, so that row applies
the same criterion as +5V; tighten it if the downstream load turns out to care.

## 8. Rail matching

For a bipolar analog supply, the two 12V rails should be symmetric:

- Measure +12V and -12V simultaneously at the same load.
- Compute the imbalance: the difference between the magnitudes should be under 0.5V.
- If it is not, adjust the upstream DC-DC feedback divider rather than the LDO.

## Recording results

Every measurement here feeds a fact carrying a **NEEDS BENCH** verdict:
`fact-cj7912-rail-headroom`, `fact-cj7912-tj-rise-full-load`,
`fact-cj7912-stability-project-network`, `fact-l7812cd2t-headroom`,
`fact-l7805abd2t-headroom`, `fact-lm2596-thermal`. Log the measured value, the load,
the input voltage and the ambient temperature for each, so the results can be folded
back into the component records rather than staying in a notebook.

## Related

- [Regulator Assembly, Soldering, and Inspection](./regulator-assembly-and-inspection.md)
- [Linear Regulator PCB Layout and Thermal Design](../project/linear-regulator-layout.md)
- [DC-DC Converter Stage Design (LM2596S-ADJ)](../project/dcdc-converter-design.md)

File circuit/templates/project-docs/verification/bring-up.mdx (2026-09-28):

---
title: "Verification and bring-up report"
description: "A revision-specific test plan and execution record with evidence, results, and remaining limits."
sidebar_position: 10
---

Duplicate this page for a bounded verification or a specific hardware run. The initial state is **plan only; no procedure has been performed**. A new project must define its own sequence, operating limits, and acceptance criteria.

## Test identity

| Field | Entry |
|---|---|
| Report ID | Not assigned |
| Question or behavior being tested | Not entered |
| Plan or execution state | Plan only; not run |
| Date, operator and location | Not entered |
| Physical unit or specimen ID | Not entered |
| Schematic and PCB revision | Not entered |
| Firmware and stored configuration | Not entered |
| Assembly deviations or rework | Not entered |
| Related requirements and open questions | Not entered |

If no hardware is available, record the work as a proposed procedure, document review, simulation, or other appropriate activity. Do not report a calculated prediction as a measurement.

## Scope and prerequisites

State what this activity can establish and what it cannot. Identify the actual setup, instruments, source, loads, fixtures, connection mapping, and relevant environmental conditions. Record instrument mode and measurement method where they change the meaning of a result.

List prerequisites in the order needed for this project. Link the evidence that defines initial configuration and allowable conditions. Identify any unresolved prerequisite before execution; limits and sequences from another project or a reference design are not defaults for this circuit.

## Acceptance criteria and observations

| Check ID | Setup and action | Expected criterion and basis | Observation or raw evidence | Outcome |
|---|---|---|---|---|
| Not assigned | Not planned | Not defined | Not recorded | Not run |

Define each criterion before evaluating the result. A useful outcome distinguishes pass, fail, inconclusive, blocked, and not run, keeping it separate from the evidence verdicts listed in `circuit/WORKFLOW.md`. A check can pass within its scope while a broader design question remains open.

Where a staged sequence is necessary, state which result permits the next stage, why that dependency exists, and what action follows an unexpected result. Select the actual limits from this project's evidence and engineering review.

## Captured evidence

| Evidence reference | What it contains | Capture conditions | Revision or configuration association |
|---|---|---|---|
| None recorded | Not entered | Not entered | Not entered |

Examples include meter readings, scope captures, logs, photographs, configuration readback, or dimensional measurements. Preserve raw observations and link them from the component evidence bundle or verification records. A filename alone does not establish what setup produced it.

## Result and interpretation

No result is recorded. Once executed, write what was directly observed, what was inferred, and what remains unresolved. Describe any unexpected behavior before proposing its cause. If a test changes the setup or the hardware partway through, preserve that transition and identify which observations belong to which state.

## Follow-up and affected claims

List claims, calculations, decisions, or next actions that this result supports or reopens. Update the canonical evidence coverage only for the scope actually demonstrated. Link a separate report for a repeated test or another physical revision.

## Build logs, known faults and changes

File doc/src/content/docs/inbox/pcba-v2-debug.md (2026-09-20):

---
title: PCBA v2 Debug Report — STUSB4500 CC1DB Failure
sidebar_position: 7
---

<Note title="Historical reference">

This page is retained from the previous design documentation. Parts, geometry,
status and numerical claims may be superseded. Start with the
[current architecture](/docs/architecture/) and verify exact components in the
[catalog](/docs/components/catalog/). See the [archive guide](/docs/archive/) for context.

</Note>

<Note title="Superseded by the 2-board split / v4 diagnosis (2026-07)">

The "v3 design fix" documented on this page — external 5.1 kΩ Rd on CC1/CC2 plus
CC1DB/CC2DB grounded (disabling dead-battery mode) — is the topology reversed by
[decision A1](./board-split-decision.md) in the Board Split Decision. The
[v4 USB-PD Failure Diagnosis](./v4-pd-failure-diagnosis.md) found this topology puts the
CC line **out of the USB Type-C sink Rd spec the moment the chip powers up** (external Rd
∥ the STUSB4500's own non-disableable internal Rd ≈ 2.55 kΩ, below the 5.1 kΩ ±20%
window) — a design defect on every board, independent of whether any chip's CC1DB pin
was ever actually shorted. Board A restores `CC1DB↔CC1` / `CC2DB↔CC2` (ST's reference
dead-battery wiring) with the external Rd DNP'd. This page's diagnostic sequence and
root-cause analysis for the specific v2 chip-internal-short symptom remain useful
historical record; its *design recommendation* (the v3 fix) is superseded.

</Note>

Debug analysis of the second PCBA prototype (v2) for the USB-PD modular synthesizer power supply. The STUSB4500 was successfully programmed via NVM, but the chip's **CC1DB pin is internally shorted to GND on every assembled board**, preventing USB-C source detection and blocking PD negotiation entirely. This page documents the failure mode, diagnostic sequence, root cause analysis, and the v3 design fix.

## Symptoms

After PCBA v2 was assembled by JLCPCB and the STUSB4500 NVM was successfully programmed:

| Observation | Detail |
| --- | --- |
| Charger plugged in | **0V on USB-C VBUS pin at the connector itself** |
| STUSB4500 detected on I2C | ✅ Yes — chip responds at address 0x28, NVM read/write works |
| NVM written with target PDOs | ✅ Yes — `SNK_PDO_NUMB = 2`, PDO2 = 15V/3A confirmed via read-back |
| GUI "Dashboard" tab | **"No device attached"** — chip sees nothing on its CC pins |
| Multimeter at D4 (ESD diode) | **CC1 net = 0 Ω to GND** (shorted), CC2 net = 5.1 kΩ to GND (correct) |
| Both PCBAs (2 boards from same JLCPCB order) | **Identical fault** |

## Root Cause

**The STUSB4500's CC1DB pin (pin 1) is internally shorted to GND.**

CC1DB provides "dead battery mode" termination — a passive 5.1 kΩ Rd pulldown that the USB-C source detects in order to apply VBUS. Since CC1DB is internally shorted to 0 Ω instead of presenting 5.1 kΩ Rd, the source sees an invalid CC termination and refuses to enable VBUS.

The v2 schematic correctly ties **CC1DB → CC1 net** (the standard ST-recommended dead-battery wiring). With the chip's internal short, this wiring drags the entire CC1 net to GND.

## Diagnostic Sequence That Isolated the Fault

### Step 1: GUI Dashboard ruled out NVM and software

The STSW-STUSB002 GUI's Dashboard tab showed **"No device attached"** even with a USB-C cable plugged into a working PD charger. NVM-level settings cannot influence the chip's hardware CC detection — this proved the issue was at the physical CC pin level, not software.

### Step 2: Multimeter measurements at D4 (USBLC6-2SC6)

D4 sits between the USB-C connector and the STUSB4500 on both CC lines. With board unpowered:

| Probe | Reading | Conclusion |
| --- | --- | --- |
| D4 pin 1 (J1-CC1 side) to GND | **0 Ω** | CC1 net shorted to GND |
| D4 pin 6 (U1-CC1 side) to GND | **0 Ω** | Confirms short propagates through diode (D4 passes signal correctly) |
| D4 pin 3 (J1-CC2 side) to GND | **5.1 kΩ** | CC2 net correctly terminated |
| D4 pin 4 (U1-CC2 side) to GND | **5.1 kΩ** | CC2 chip-internal Rd works |
| D4 pin 1 to D4 pin 6 (across diode) | **0 Ω** | Diode passes signal — D4 is healthy |

The asymmetry (CC1 shorted, CC2 fine) ruled out a generic short and pointed to a chip-side issue at pin 1 (CC1DB).

### Step 3: Hot-air removal of U1 isolated the source

To definitively localize the short to the chip or the PCB:

1. Applied flux + hot air to U1 (STUSB4500), removed the chip
2. With chip off, measured pad 1 (CC1DB position on the empty footprint) to GND: **OPEN circuit**
3. PCB pads were visually clean — no solder bridges remained under the chip area

**Conclusion**: the chip was the source of the short. The PCB itself has no design or assembly defect on the CC1 net.

### Step 4: Both PCBAs show identical fault

Two boards from the same JLCPCB order exhibited the exact same CC1DB short with the exact same chip placement orientation. This rules out:

- ❌ Random ESD damage (would affect chips randomly)
- ❌ Single-chip manufacturing defect
- ❌ Initial 20V overvoltage during testing (the second board was always programmed with a 5V-only charger first — confirmed by sequence of operations)

## What We Ruled Out Through Investigation

| Hypothesis | Status | How |
| --- | --- | --- |
| Wrong USB-C cable | Ruled out | Multiple cables tested |
| Wrong charger | Ruled out | Multiple chargers (all with 15V/3A support) tested |
| Chip damaged from initial 20V exposure | Ruled out | Second PCBA never saw 20V — same fault |
| Schematic error | Ruled out | Wiring matches SparkFun reference + ST datasheet typical app |
| USB-C connector footprint wrong | Ruled out | 6-pin SMD USB-C correctly maps B5 to CC2 internally |
| D4 (USBLC6) ESD diode dead | Ruled out | 0 Ω across pin 1↔6 confirms diode passes |
| CC1 trace touching GND on PCB | Ruled out | DRC clean on all layers; net visually clean in KiCad layout |
| STUSB4500 chip rotation wrong | Ruled out | I2C works on pins 7/8 → pin numbering is mapped correctly |
| NVM corruption | Ruled out | NVM read/write works; Dashboard says "No device attached" which is hardware-level |
| Footprint pad mapping wrong in PCB | Ruled out | PCB net assignments confirmed (pin 1 → Net-(U1-CC1), pin 6 → GND, etc.) |
| Counterfeit chip | Likely but unconfirmed | Both chips from same LCSC batch (C2678061) |

## Why v2 Design Is Vulnerable

The v2 schematic ties **CC1DB ↔ CC1** and **CC2DB ↔ CC2** — the standard ST-recommended dead-battery mode wiring used by:

- **SparkFun Power Delivery Board** ([schematic](https://cdn.sparkfun.com/assets/9/2/6/8/6/SparkFun_PowerDeliveryBoardSchematic.pdf))
- **ST STEVAL-ISC005V1** evaluation board
- **STUSB4500 datasheet "typical application" (Figure 10)**

This design relies **entirely on the chip's internal Rd** for CC termination. There's no external fallback. If any chip ships with internally-damaged CC1DB or CC2DB pins, **the entire board is bricked** with no rework option short of chip replacement.

## ST Datasheet Reference

Per the STUSB4500 datasheet (DS12499 Rev 5), pin description for CC1DB / CC2DB (page 4, Table 1):

> Pin 1 CC1DB: "Dead battery enable on CC1 pin" — Typical connection: **"To CC1 pin if used or ground"**
>
> Pin 5 CC2DB: "Dead battery enable on CC2 pin" — Typical connection: **"To CC2 pin if used or ground"**

And from §2.2.2 (page 5):

> "CC1DB and CC2DB are used for dead battery mode. This mode is enabled by connecting CC1DB and CC2DB respectively to CC1 and CC2. Thanks to this connection, the pull-down terminations on the CC pins are present by default even if the device is not supplied."
>
> ⚠️ **Warning: "CC1DB and CC2DB must be connected to ground when dead battery mode is not supported."**

**Both wiring options — "to CC1/CC2" (dead-battery) and "to ground" (no dead-battery) — are explicitly ST-supported.** The v3 fix uses the second option.

## v3 Design Fix

### Topology change

```
v2 (vulnerable):                          v3 (robust):

USB-C CC1 ─┬─ D4 ─ STUSB4500 pin 2 (CC1)  USB-C CC1 ─┬─ D4 ─ STUSB4500 pin 2 (CC1)
           │                                          │
           └─────── STUSB4500 pin 1 (CC1DB)           R_CC1 (5.1 kΩ)   ← NEW
                                                      │
                                                     GND

                                          STUSB4500 pin 1 (CC1DB) ─── GND   ← CHANGED

(symmetric for CC2)                       (symmetric for CC2)
```

### Schematic changes

| Change | Detail |
| --- | --- |
| **Add R_CC1 = 5.1 kΩ (0603, 1%)** | From CC1 net (USB-C connector side) to GND |
| **Add R_CC2 = 5.1 kΩ (0603, 1%)** | From CC2 net (USB-C connector side) to GND |
| **Disconnect U1 pin 1 (CC1DB) from CC1 net** | Tie pin 1 directly to GND |
| **Disconnect U1 pin 5 (CC2DB) from CC2 net** | Tie pin 5 directly to GND |

### Why 5.1 kΩ (and not 10 kΩ)?

5.1 kΩ is the **USB-C spec Rd value** (±20%, valid range 4.08–6.12 kΩ). Every USB-C sink uses this.

An earlier draft of this fix proposed 10 kΩ as a hedge in case a future chip batch ships with working internal Rd (so external + internal in parallel wouldn't drop too far below spec). That reasoning was rejected:

| Scenario | Effective Rd | USB-C spec window: 4.08–6.12 kΩ |
| --- | --- | --- |
| Broken chip (current batch, CC1DB → GND, internal Rd dead) + ext 5.1 kΩ | **5.1 kΩ** | ✅ In spec |
| Broken chip + ext 10 kΩ | **10 kΩ** | ⚠️ Above spec — marginal on strict sources |
| Good chip (hypothetical, internal Rd works) + ext 5.1 kΩ | **2.55 kΩ** | ❌ Below spec |
| Good chip + ext 10 kΩ | **3.4 kΩ** | ❌ Below spec |

**10 kΩ is out of spec in every scenario.** 5.1 kΩ is in spec for our actual reality (broken chips, external Rd carries the load alone).

The "good chip" parallel-resistance failure mode is **not** solved by picking a compromise external value — the proper fix is to **remove the external Rd entirely** (board respin, or a populate/DNP jumper) once you know the chip's internal Rd is healthy. So for v3 we use the spec value and don't try to compromise across two failure scenarios.

**Sensitivity on 3 A USB-C sources:** sources advertising 3 A use Rp = 22 kΩ (tightest detection). The CC line voltage with Rp pull-up:

- 5.1 kΩ Rd → 5 V × 5.1 / (5.1 + 22) ≈ **0.94 V** — comfortably below the ~1.7 V "sink connected" threshold
- 10 kΩ Rd → 5 V × 10 / (10 + 22) ≈ **1.56 V** — borderline; some compliant sources will fail to detect

### Why disconnect CC1DB / CC2DB from CC1 / CC2?

**This is the critical change.** If CC1DB stays on the CC1 net (v2 wiring), then a chip with internally-shorted CC1DB still drags the entire CC1 net to 0 Ω, and the external 5.1 kΩ is overpowered (a 0 Ω short wins against any finite resistor). The fault persists.

By routing CC1DB and CC2DB to GND directly:

- The broken pin's internal short is isolated to the GND net (harmless)
- The CC1 / CC2 nets see only the external R_CC1 / R_CC2 and the chip's main CC pins (pin 2, pin 4) for termination

### What we give up: Dead-battery mode

In v3, the chip cannot present passive Rd before being powered. The chicken-and-egg is solved by the external R_CC1 / R_CC2 — these are always present and always provide valid Rd, so the source detects the sink, applies 5V VBUS, which powers the chip via VDD, which then takes over CC handling actively.

Dead-battery mode is only needed when the chip is being powered from a separate depleted battery and needs to advertise itself before that battery recovers. **For VBUS-only powered designs like zudo-pd, dead-battery mode provides no benefit and creates the single-point-of-failure we hit.**

## Additional v3 Improvements (Recommended)

### EPAD F.Paste aperture (footprint fix)

The current QFN-24 footprint defines pad 25 (the EPAD) with a single solid 2.8 × 2.8 mm F.Paste aperture. Standard QFN best practice is to **window the EPAD paste** into a grid of smaller apertures (e.g., 4×4 sub-squares of ~0.5 × 0.5 mm each, ~50-60% area coverage). This:

- Controls solder paste volume on the EPAD
- Prevents excess solder from squeezing out at the EPAD corners during reflow
- Reduces risk of solder bridging to corner pins (CC1DB is at one corner, RESET at the opposite corner)
- Is JLCPCB-recommended for thermal pad SMT assembly

### EPAD GND vias (footprint fix)

The current EPAD has 16 GND vias in a 4×4 grid. Standard QFN recommendation is **4–9 vias** for thermal/electrical GND connection. Excessive vias can wick solder away from the joint during reflow, contributing to solder migration and uneven joint quality.

**Recommendation**: Reduce to a 3×3 grid (9 vias) or 5 vias (4 corners + center). Use solder-mask plug on via-in-pad to prevent paste loss.

### External Rd resistor placement

Place R_CC1 and R_CC2 **physically close to the USB-C connector**, before D4. This ensures the source's first measurement (at first cable plug) sees the external Rd directly, even if D4 or downstream traces have issues.

## v3 Schematic Fix Checklist

- [x] Add R17 = R_CC1 (5.1 kΩ, 0603, 1%, C23186) from USB-C CC1 to GND
- [x] Add R18 = R_CC2 (5.1 kΩ, 0603, 1%, C23186) from USB-C CC2 to GND
- [x] Disconnect U1 pin 1 (CC1DB) from CC1 net; tie to GND via **R19 (0 Ω, 0603, C21189)** — uses a 0 Ω jumper instead of a direct GND tie so the chip-side net keeps the name `CC1DB`. That preserves a uniquely-named test point on the J3 pogo block (pin 1) for verifying chip-pin continuity, and lets us lift R19 for chip-isolation measurement during future debug
- [x] Disconnect U1 pin 5 (CC2DB) from CC2 net; tie to GND via **R20 (0 Ω, 0603, C21189)** — same rationale, J3 pogo pin 2
- [ ] Update QFN-24 footprint: window the EPAD F.Paste into a 4×4 grid of 0.5 mm² apertures
- [ ] Update QFN-24 footprint: reduce EPAD GND vias from 16 to 9 (or 5)
- [ ] Add via tenting / mask-plug on EPAD via-in-pad
- [ ] Run DRC and ERC
- [ ] Bench test on first v3 board: cold-plug a USB-C source, confirm VBUS appears (proves external Rd bootstrap works)

## Reference Designs Compared

| Design | CC1DB wiring | External Rd on CC | Notes |
| --- | --- | --- | --- |
| **zudo-pd v2** (current) | CC1DB ↔ CC1 (dead-battery) | None | ❌ Fails when chip ships with CC1DB internally shorted |
| **SparkFun Power Delivery Board** | CC1DB ↔ CC1 (dead-battery) | None | Standard ST design; works when chips are good |
| **ST STEVAL-ISC005V1** | CC1DB ↔ CC1 (dead-battery) | None | ST's own eval design; works with controlled chip sourcing |
| **STUSB4500 datasheet Fig. 10** | CC1DB ↔ CC1 (dead-battery) | None | "Typical application" — same vulnerability |
| **Instructables DIY Hotplate** | CC1DB ↔ CC1 (dead-battery) | R3 = 10 kΩ on CC1 only | Confirmed working JLCPCB build; asymmetric ext Rd |
| **zudo-pd v3** | CC1DB → GND via R19 (0 Ω), CC2DB → GND via R20 (0 Ω) | **5.1 kΩ on both CC1 and CC2** (R17/R18) | Defensive against chip-side failures; USB-C spec Rd value; symmetric. 0 Ω jumper preserves named `CC1DB`/`CC2DB` nets for J3 pogo testing and chip-isolation rework |

## References

- [STUSB4500 Datasheet DS12499 Rev 5](https://www.st.com/resource/en/datasheet/stusb4500.pdf) — pages 4, 5, 14, 23, 25, 26 referenced
- [STUSB4500L Datasheet](https://www.st.com/resource/en/datasheet/stusb4500l.pdf) — variant with similar CC pin scheme
- [STEVAL-ISC005V1 Schematic Pack](https://www.st.com/resource/en/schematic_pack/steval-isc005v1_schematic.pdf) — ST eval board reference
- [STEVAL-ISC005V1 User Manual UM2547](https://www.st.com/resource/en/user_manual/dm00493783-getting-started-with-the-stevalisc005v1-evaluation-board-for-stusb4500-stmicroelectronics.pdf)
- [SparkFun Power Delivery Board Schematic (PDF)](https://cdn.sparkfun.com/assets/9/2/6/8/6/SparkFun_PowerDeliveryBoardSchematic.pdf)
- [SparkFun Power Delivery Board product page](https://www.sparkfun.com/products/15801)
- [DIY Smart Hotplate (Instructables)](https://www.instructables.com/DIY-Smart-Hotplate-Powered-by-STM32-USB-C-Power-De/) — working JLCPCB design with 10 kΩ external Rd on CC1
- [GitHub: usb-c/STUSB4500](https://github.com/usb-c/STUSB4500) — official ST reference code
- [USB Type-C 2.0 Specification](https://www.usb.org/document-library/usb-type-cr-cable-and-connector-specification-release-22) — Rd termination requirements (§4.11.2)
- [PCBA v1 Debug Report](/docs/inbox/pcba-v1-debug) — v1 issues (different failure mode: pin 18 and pin 22 wiring)
- [NVM Programming Setup](/docs/inbox/nvm-programming) — how to program the chip via STSW-STUSB002 GUI

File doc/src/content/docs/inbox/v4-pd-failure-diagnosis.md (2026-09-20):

---
title: v4 USB-PD Failure Diagnosis (front-end datasheet review)
sidebar_position: 12
description: Ranked root-cause candidates for the v4 (0.4.0) PD failure, verified against the real netlist and the ST datasheets, plus a bench discrimination procedure for the dead v4 boards.
---

<Note title="Historical reference">

This page is retained from the previous design documentation. Parts, geometry,
status and numerical claims may be superseded. Start with the
[current architecture](/docs/architecture/) and verify exact components in the
[catalog](/docs/components/catalog/). See the [archive guide](/docs/archive/) for context.

</Note>

The v4 (0.4.0) board still fails USB-PD even though the v3 pin-18 bug is fixed and the
NVM is programmed for 15 V. This page ranks root-cause candidates for the v4 failure
from a datasheet-aware review of the USB-PD front end (`usb-pd-input.kicad_sch`), and
gives a bench procedure that discriminates between the candidates on the dead v4 boards.

**Method.** Every connectivity claim below was generated from the real KiCad netlist
(`kicad-cli sch export netlist --format kicadxml`, exported 2026-07-05 from this repo),
never from symbol screen positions. Datasheet claims cite ST DS12499 Rev 4 (STUSB4500)
and the ST USBLC6-2 datasheet; USB Type-C spec values are labeled for verification where
the primary table could not be fetched.

<Note>

Findings in this page are **leads to verify on the bench, not verdicts**. A static
netlist review cannot measure voltages, observe protocol timing, or prove which of
several stacked defects actually produced the observed failure. The discrimination
procedure below exists precisely because more than one verified defect can explain the
symptoms.

</Note>

## The v4 symptom set collapses to one observable

Reported v4 symptoms: no PD negotiation, VBUS_EN_SNK never asserts, all rails dead.

The NVM on the v4 boards was programmed with `POWER_ONLY_ABOVE_5V = 1`
(see [NVM Programming Setup](./nvm-programming.md)). Per DS12499 Rev 4 Table 10
("VBUS_EN_SNK pin behavior"), with `POWER_ONLY_ABOVE_5V = 1b` the VBUS_EN_SNK pin stays
**Hi-Z at 5 V even in Attached.SNK**, and only asserts (open-drain pulls **low**) when
VBUS operates under PDO2 or PDO3. VBUS_EN_SNK is **active-low open-drain**
(DS12499 Table 1, pin 16): asserted = pulled low = Q1 P-FET on.

Therefore "VBUS_EN_SNK never asserts" and "rails dead" are the *expected downstream
consequences* of a single failure: **no 15 V contract is ever established (or never
survives)**. The diagnosis only has to explain the missing/collapsing 15 V contract.

<Warning>

A fast contract-then-collapse is indistinguishable from "no negotiation" on a DMM. A PD
contract, the 5 V to 15 V transition, an overcurrent event, and the source's protective
shutdown all complete within a few hundred ms. Only a scope on VBUS_IN and CC (procedure
below) can tell these apart.

</Warning>

## Verified front-end topology (from the 2026-07-05 netlist export)

<Note>

In this export the ground net is named `RST`: the `RST` label on U1 pin 6 (RESET,
active-high input, correctly strapped to ground) was absorbed as the name of the whole
GND net. Everywhere `RST` appears below, read **GND**.

</Note>

### Net table — USB-PD Input sheet (front-end nets)

| Net | Connected pins (Ref.Pin) | Value/Note |
|-----|---|---|
| `VBUS_IN` | `J1.A9 J1.B9 U1.24 D4.5 Q1.2 R11.2 R14.1 C1.2 C2.2 J3.4` | Receptacle VBUS. U1.24 = VDD (direct). **D4.5 = USBLC6-2 VBUS pin — candidate 2.** C1 10 µF, C2 100 nF decoupling |
| `Net-(J1-CC1)` | `J1.A5 D4.1 R17.1` | Connector-side CC1. R17 5.1 kΩ external Rd to GND |
| `Net-(U1-CC1)` | `D4.6 U1.2` | Chip-side CC1. **Only joined to the connector through D4's internal 1↔6 flow-through — candidate 3** |
| `Net-(J1-CC2)` | `J1.B5 D4.3 R18.1` | Connector-side CC2. R18 5.1 kΩ external Rd to GND |
| `Net-(U1-CC2)` | `D4.4 U1.4` | Chip-side CC2, via D4 internal 3↔4 |
| `CC1DB` | `U1.1 R19.1 J3.1` | Dead-battery pin, R19 (0 Ω) to GND — dead-battery mode disabled |
| `CC2DB` | `U1.5 R20.1 J3.2` | Dead-battery pin, R20 (0 Ω) to GND |
| `VBUS_VS_DISCH` | `U1.18 R14.2 TP6.1` | Pin-18 sense/discharge node; R14.1 is on `VBUS_IN` → **the v3 fix is present** (470 Ω series from VBUS_IN) |
| `VBEN` | `U1.16 R12.1 J3.8` | VBUS_EN_SNK, active-low open-drain, series R12 56 kΩ to gate node |
| `Net-(Q1-G)` | `Q1.1 R11.1 R12.2 C35.1` | Q1 gate. R11 100 kΩ pull-up to VBUS_IN (gate off = FET off), C35 100 nF to GND |
| `VBUS_OUT` | `Q1.3 R13.1 TP1.1 C5.1 C7.1 C9.1 C6.1 C8.1 C10.1 U2.1 U3.1 U4.1` | Switched rail feeding the DC-DC stage |
| `Net-(U1-DISCH)` | `U1.9 R13.2` | DISCH pin → R13 470 Ω → VBUS_OUT (power-system-side discharge) |
| `VREG_2V7` | `U1.23 C30.2 R15.2 R16.2 J3.3` | 2.7 V regulator, 1 µF decap, I2C pull-up rail |
| `Net-(U1-VREG_1V2)` | `U1.21 C34.1` | 1.2 V regulator, 1 µF decap |
| `SCL-pin1` / `SDA-pin2` | `U1.7 R15.1 J2.1` / `U1.8 R16.1 J2.2` | I2C to J2 pogo pads |
| `RST` (= GND) | `U1.6 U1.10 U1.12 U1.13 U1.22 U1.25 D4.2 J1.A12 J1.B12 J1.7 R17.2 R18.2 R19.2 R20.2 C30.1 C34.2 C35.2 J2.3 J3.5` (front-end members) | RESET, GND, ADDR0/1 (I2C 0x28), VSYS, EP all correctly strapped |

### Block diagram

```mermaid
flowchart TD
  J1["J1 USB-C receptacle"] -->|"Net-(J1-CC1) / Net-(J1-CC2)"| D4["D4 USBLC6-2SC6\nCC flow-through 1-6 / 3-4\nVBUS pin 5 on VBUS_IN"]
  J1 -->|"VBUS_IN"| VDD["U1.24 VDD (direct)"]
  D4 -->|"Net-(U1-CC1) / Net-(U1-CC2)"| U1["U1 STUSB4500\nPD sink controller"]
  RD["R17 / R18 5.1k external Rd\n(connector side, to GND)"] --- J1
  DB["CC1DB / CC2DB via R19 / R20 (0 ohm) to GND\n(dead-battery mode disabled)"] --- U1
  J1 -->|"VBUS_IN"| R14["R14 470 ohm"] -->|"VBUS_VS_DISCH"| P18["U1.18 sense/discharge"]
  U1 -->|"VBEN (active-low OD)"| R12["R12 56k"] --> GATE["Q1 gate node\nR11 100k pull-up to VBUS_IN\nC35 100n to GND"]
  GATE --> Q1["Q1 AO3401A P-FET\nS = VBUS_IN, D = VBUS_OUT"]
  Q1 -->|"VBUS_OUT"| DCDC["DC-DC stage U2/U3/U4"]
```

## Ranked root-cause candidates

### 1. External Rd in parallel with the powered chip's internal Rd — CC termination out of spec the moment U1 boots

**Severity: blocker (design defect, present on every board). Symptom fit: high, charger-dependent.**

**Net evidence.** `Net-(J1-CC1) = J1.A5 D4.1 R17.1` with `R17.2` on GND (5.1 kΩ), and
`Net-(U1-CC1) = D4.6 U1.2` — the external Rd and U1's CC1 pin sit on the same electrical
node (through D4's flow-through). Same for CC2 via R18. `CC1DB`/`CC2DB` are grounded
through R19/R20 (0 Ω), so dead-battery mode is disabled and the external resistors are
the **only** termination while U1 is unpowered.

**Datasheet basis.** DS12499 Rev 4 §7.3 Table 22: the STUSB4500 presents
**Rd = 5.1 kΩ ±10% pull-down on the CC pins** in operation (`RINCC` = 200 kΩ applies only
with "Terminations off", i.e. during reset — §2.2.1 "CC1 and CC2 are HiZ during reset").
The STUSB4500 is an auto-run sink controller; internal Rd cannot be disabled by NVM.
So once VBUS powers VDD (U1.24 is tied to VBUS_IN directly) and the chip loads its NVM
(TLOAD = 30 ms, Table 22), the source sees **5.1 kΩ ∥ 5.1 kΩ ≈ 2.55 kΩ** — below the
USB Type-C sink Rd window of 5.1 kΩ ±20% (4.08–6.12 kΩ; verify against USB Type-C
spec R2.0 §4.11.2 / Table 4-33). The v2 debug page itself computed this case and marked
it "below spec" — see the re-examination section below.

**Failure mechanism.** Source-perspective CC detection windows (USB Type-C R2.0
Table 4-36 — values below reconstructed from implementation datasheets, e.g. onsemi
FUSB3307 places its source-side Ra-vs-Rd comparator for 3 A Rp between 0.75 and 0.85 V;
label: verify against the spec table):

| Source Rp | Rp current | V(CC) with 5.1 kΩ (chip unpowered) | V(CC) with 2.55 kΩ (chip powered) | Rd-detect floor (vRd-Connect min) |
|---|---|---|---|---|
| Default USB | 80 µA ±20% | 0.41 V — valid | **0.20 V — below the 0.25 V floor, reads as Ra/undefined** | 0.25 V |
| 1.5 A | 180 µA ±8% | 0.92 V — valid | **0.46 V — barely above the 0.45 V floor** | 0.45 V |
| 3.0 A | 330 µA ±8% | 1.68 V — valid | **0.84 V — inside the 0.75–0.85 V undefined band** | 0.85 V |

Sequence on every cold plug: the unpowered board presents a clean 5.1 kΩ → the source
debounces, attaches, applies vSafe5V → U1's VDD comes up, and ~30–50 ms later the
internal Rd lands in parallel → the source's CC voltage drops by half, **right when the
source is about to send Source_Capabilities**. A source whose comparator now reads
"Rd removed / Ra" treats the sink as detached or invalid: it never negotiates, or
removes VBUS — which unpowers U1, restores 5.1 kΩ, and re-attaches in a loop. Because
0.84 V sits inside a 100 mV undefined band, resistor and Rp tolerances make the outcome
**charger-dependent and even board-dependent** — consistent with a design that fails
across multiple revisions while looking "almost right".

Note the sink side is marginal too: U1's own attach threshold VTH0.2 (min CC voltage
for a connected sink) is 0.15–0.25 V (Table 22), so on a default-Rp charger (0.20 V at
the chip) even U1's source-detection is a coin flip.

**Why v3's "stable 5 V + live I2C" does not contradict this.** The programming sessions
used USB-A-to-C or dumb 5 V chargers (per the NVM setup page), which supply VBUS without
sink-detection gymnastics. The failure window only opens on a spec-compliant PD source.

### 2. D4 (USBLC6-2SC6) VBUS pin on the 15 V rail — absolute-rating violation at the exact moment a contract succeeds

**Severity: blocker (hard datasheet violation). Symptom fit: high *if* negotiation ever completes; also explains permanently-dead boards afterward.**

**Net evidence.** `VBUS_IN = ... D4.5 ...` — the USBLC6-2's VBUS pin (pin 5) sits
directly on the receptacle VBUS rail, which carries **15 V after a successful contract**.

**Datasheet basis.** ST USBLC6-2 datasheet (Rev 2 text verified; later revisions list
5.25 V): reverse stand-off voltage **VRM = 5 V**, breakdown **VBR = 6 V min at 1 mA
between VBUS and GND**, clamping 12 V at 1 A (8/20 µs). The functional diagram
(Figure 1) shows a zener between pin 5 (VBUS) and pin 2 (GND). This part is designed for
5 V USB — it is never rated for a 15 V rail.

**Failure mechanism.** The instant the source transitions VBUS to 15 V, D4's VBUS-GND
zener goes into hard breakdown (15 V ≫ 6 V), sinking whatever the source can deliver
(up to 3 A). The source hits overcurrent protection within ms and shuts down, hiccups,
or hard-resets the port. On a DMM this reads as "no negotiation, rails dead" (see the
warning above). Depending on the energy delivered, D4 dies short (VBUS_IN then loaded
even at 5 V → the board looks completely dead on subsequent plugs) or survives to repeat
the cycle. **Boards already tested against a 15 V charger may therefore carry a damaged
D4 right now** — the bench procedure checks this first.

Note the interaction with candidate 1: if candidate 1 blocks negotiation on a given
charger, 15 V never arrives and D4 survives — the two candidates mask each other, which
is why the bench order below lifts D4 pin 5 *before* any test that could produce 15 V.

### 3. CC continuity through D4's internal flow-through — the netlist relies on a part-internal join

**Severity: blocker if broken (as-built defect, not a schematic defect). Symptom fit: complete if present.**

**Net evidence.** `Net-(U1-CC1) = D4.6 U1.2` and `Net-(U1-CC2) = D4.4 U1.4` — two-pin
nets. The only path from connector CC to U1's CC pins runs through D4's package-internal
pin 1↔6 and 3↔4 connections. The USBLC6-2 datasheet Figure 1 (functional diagram) does
show pins 1/6 and 3/4 as internally common nodes (flow-through routing), so the
**schematic is electrically valid** — but any substitution, rotation, or footprint
mismatch at D4 silently opens both CC lines to the chip while leaving the connector-side
external Rd intact.

**Failure mechanism.** With the flow-through open: the source still sees R17/R18
(connector side) → attaches → applies 5 V → U1 powers via VDD and I2C works — but U1's
CC pins float, it never sees the source's BMC signaling, never answers
Source_Capabilities, and the source falls back to Type-C 5 V-only. Every v3/v4
observation (stable 5 V, live I2C, no contract, VBUS_EN_SNK stays Hi-Z because
`POWER_ONLY_ABOVE_5V = 1`) is reproduced exactly. The v2 boards measured 0 Ω across
D4 pins 1↔6 (see [PCBA v2 Debug Report](./pcba-v2-debug.md)), but v4 is a different
assembly run — re-verify. (The as-built part-substitution audit is a separate task;
here only the electrical validity and the bench check are in scope.)

### 4. NVM configuration on the failed boards — `SNK_PDO_NUMB` / `POWER_ONLY_ABOVE_5V` read-back

**Severity: marginal (shapes symptoms rather than blocking PD). Symptom fit: partial but cheap to eliminate.**

**Evidence.** Not a netlist item. The intended configuration is `SNK_PDO_NUMB = 2`,
PDO2 = 15 V/3 A, `POWER_ONLY_ABOVE_5V = 1` ([NVM Programming Setup](./nvm-programming.md)).
Two failure shapes worth eliminating by read-back on the *dead* boards:

- The setup page itself warns `POWER_ONLY_ABOVE_5V` "sometimes doesn't save on the first
  write". Other bits can fail the same way. A partial write (e.g. `SNK_PDO_NUMB` still 1,
  or PDO2 voltage not 15 V) produces a sink that negotiates a **5 V-only PD contract** —
  with `POWER_ONLY_ABOVE_5V = 1` the result is symptom-identical to "no negotiation"
  on a DMM (VBUS_EN_SNK stays Hi-Z per DS12499 Table 10).
- VBUS monitoring windows (DS12499 §3.4.1, Table 22: VMONUSBH/VMONUSBL, default
  −20%/+15% at attach) are NVM-programmable; a corrupted shift coefficient could make
  the chip reject valid VBUS. Default values are safe — verify they are still default.

### 5. Re-confirmed items — verified OK in this pass (no action)

| Item | Net evidence (this export) | Verdict |
|---|---|---|
| Pin-18 network (the v3 root cause) | `VBUS_VS_DISCH = U1.18 R14.2 TP6.1`, `R14.1` on `VBUS_IN`, R14 = 470 Ω | **OK.** Matches DS12499 Table 1 pin 18 "From VBUS, receptacle side". Table 22 (IDISUSB) specifies discharge "through external resistor connected to VBUS_VS_DISCH pin", ≤50 mA: 15 V / 470 Ω ≈ 32 mA — inside the rating. The v3 fix is present and correctly valued |
| Q1 gate drive | `Net-(Q1-G) = Q1.1 R11.1 R12.2 C35.1`; R11 100 kΩ → VBUS_IN, R12 56 kΩ → VBEN | **OK.** VBEN asserted (low): V(gate) = VBUS × 56/156 → Vgs ≈ −0.64 × VBUS = −3.2 V at 5 V, −9.6 V at 15 V — both enhance the AO3401A well and stay inside its ±12 V Vgs limit (verify against the AOS AO3401A datasheet). VBEN released: R11 pulls Vgs to 0 V, FET off |
| RESET / ADDR / VSYS / EP | `U1.6 U1.12 U1.13 U1.22 U1.25` all on GND | **OK.** RESET is active-high (DS12499 §2.2.3) so ground = run; ADDR = 0x28; VSYS grounded is correct for VDD-only supply (Table 1) |
| Decoupling | VDD: C1 10 µF + C2 100 nF on `VBUS_IN`; VREG_2V7: C30 1 µF; VREG_1V2: C34 1 µF | **OK.** Matches DS12499 Table 1 typical connections (1 µF typ. on each regulator) |
| VDD rating | U1.24 direct on `VBUS_IN` (15 V contract) | **OK.** VDD range 4.1–22 V (DS12499 Features/§7); 15 V is fine. U1's CC pins carry 22 V short-to-VBUS protection — U1 itself does not need D4 to survive CC faults |
| I2C | `SCL-pin1`/`SDA-pin2` with 4.7 kΩ pull-ups to VREG_2V7 | **OK.** Proven working on v3 hardware |

## Re-examination of the v2 "CC1DB chip-internal short" conclusion

The entire external-Rd topology (candidate 1) exists because of the v2 diagnosis
([PCBA v2 Debug Report](./pcba-v2-debug.md)): CC1 measured 0 Ω to GND on two boards,
the empty pad measured open after hot-air removal of U1, and the conclusion was
"CC1DB internally shorted — batch defect", fixed by grounding the DB pins and adding
external Rd. Re-reading that evidence against DS12499:

**What holds up.** The asymmetry was real on those chips: CC2 (wired CC2DB↔CC2 in v2)
measured 5.1 kΩ unpowered while CC1 measured 0 Ω, and removing U1 removed the short.
Something genuinely differed between pin 1 and pin 5 on those two v2 chips.

**What does not hold up.**

- The 5.1 kΩ read on CC2 was **not** "chip-internal Rd works" as the v2 page says — an
  unpowered STUSB4500 presents no Rd on CC2 itself. What was measured was the
  **dead-battery termination through CC2DB behaving exactly as designed**
  (DS12499 §3.5: the DB path "presents a pull-down termination on its CC pins ... even
  if the device is not supplied").
- A dead-battery termination is an unpowered depletion-type pull-down, characterized
  only by its behavior at Rp currents (80–330 µA). Its small-signal resistance under a
  DMM's test current is **not specified** by ST — a low-ohms reading on an unpowered DB
  pin is not, by itself, proof of a defect. The v2 measurement never recorded DMM test
  polarity or current, never compared a known-good reference chip measured the same
  way, and never confirmed the "short" at operating conditions. "0 Ω" on an autoranging
  DMM can be anything below tens of ohms.
- Even granting a genuine CC1DB defect on that one LCSC batch, the v3 response traded an
  unproven single-batch defect for a **permanent spec violation**: the v2 page's own
  table computes "good chip + ext 5.1 kΩ → 2.55 kΩ — below spec" and even states the
  proper fix is to remove the external Rd once the chip's Rd is known healthy. The v3/v4
  chips demonstrably run (I2C alive, NVM programmable), so their internal Rd is active,
  and 2.55 kΩ is the operating condition on every powered attach — candidate 1.
- DS12499 §3.5 says dead-battery mode "is also used in systems that are powered through
  the VBUS only" — i.e. ST's intended topology for exactly this board is CCxDB↔CCx with
  **no** external Rd (as used by the SparkFun board, STEVAL-ISC005V1, and datasheet
  Figure 10). For a VBUS-only sink, "ground the DB pins" (the no-dead-battery option)
  plus external Rd is structurally self-contradictory: the external Rd is mandatory for
  the unpowered attach, but out of spec the moment the chip runs.

**Verdict: the v2 chips may or may not have been defective — the evidence is
inconclusive — but the redesign built on that conclusion is itself a defect.** The v5
fix should return to the ST reference wiring (CC1DB↔CC1, CC2DB↔CC2, no external Rd,
optionally keeping DNP footprints for R17/R18 as rework insurance), pending the bench
result of test B4 below.

## Bench discrimination procedure (dead v4 boards, cheapest first)

Equipment: DMM with diode mode, fine probes, soldering iron + hot air, a scope
(≥10 MHz is plenty for attach dynamics; CC BMC bursts just need to be *seen*, not
decoded), the 15 V/3 A PD charger that failed, a USB-A-to-C cable, the NVM programming
rig ([NVM Programming Setup](./nvm-programming.md)).

<Warning>

Do all Stage A checks before ever plugging the PD charger in again, and do the D4
pin-5 lift (test C1) **before** any test that could let a 15 V contract succeed.
Candidates 1 and 2 mask each other: fixing the CC termination without lifting D4 pin 5
feeds the first successful 15 V contract straight into a 6 V zener.

</Warning>

### Stage A — unpowered continuity and damage survey (DMM only, 10 minutes)

| # | Test | Expected if OK | Outcome branches |
|---|---|---|---|
| A1 | Continuity `J1.A5` ↔ `U1.2` (probe at R17 pad 1 vs D4 pin 6 or the U1.2 QFN edge) and `J1.B5` ↔ `U1.4` (R18 pad 1 vs D4 pin 4) | ≈ 0 Ω both lines | Open or high on either line → **candidate 3 confirmed as the blocker** (as-built D4 issue: wrong variant, rotation, bad joint). Stop, fix D4, retest attach. Both ≈ 0 Ω → candidate 3 eliminated on this board |
| A2 | Diode-mode D4 pin 5 (`VBUS_IN`) to GND, both polarities | One direction ≈ 0.6–1.1 V drop (zener forward), other direction open below the DMM test voltage | Short both ways → **D4 already destroyed → strong evidence a 15 V contract DID complete at least once** (negotiation works; candidate 2 is the killer, candidates 1/3 were not blocking on this charger). Replace/remove D4 before further tests |
| A3 | Resistance CC1→GND and CC2→GND at the connector (board unpowered) | ≈ 5.1 kΩ each (external Rd only; DB pins are grounded so no chip termination) | ≈ 2.5 kΩ → unexpected unpowered termination, investigate U1/D4 damage. ≈ 0 Ω → damaged D4 or U1 CC pin, or solder fault |
| A4 | Resistance `VBUS_IN` (J3 pad 4) ↔ TP6 | ≈ 470 Ω (R14) | Open or ≫ 470 Ω → pin-18 path broken as-built despite correct schematic — would gate VBUS_EN_SNK even after a good contract (DS12499 Table 10 conditions run on the VBUS_VS_DISCH pin) |
| A5 | Continuity J3 pad 1 (`CC1DB`) → GND and J3 pad 2 (`CC2DB`) → GND | ≈ 0 Ω (R19/R20) | Open → R19/R20 missing; a floating DB pin is out of ST's two sanctioned options (DS12499 §2.2.2 warning) |

### Stage B — powered observation (USB-A-to-C first, then scope the PD attach)

| # | Test | Expected / branches |
|---|---|---|
| B1 | USB-A-to-C 5 V source (no CC negotiation involved): J3 pad 4 ≈ 5 V, J3 pad 3 ≈ 2.7 V, I2C detect at 0x28 | Fails → chip supply problem, stop and fix first (see decision tree in the NVM page). Passes → chip runs; proceed |
| B2 | While on the 5 V source, **read back the full NVM** and diff against target (`SNK_PDO_NUMB = 2`, PDO2 = 15 V/3 A, `POWER_ONLY_ABOVE_5V`, monitor coefficients at default) | Any mismatch → **candidate 4**: rewrite, verify, retest attach before any hardware surgery |
| B3 | Scope CC1 (at R17 pad 1) and CC2 (R18 pad 1) plus `VBUS_IN`, then plug the failing 15 V/3 A PD charger. Watch the first 2 s | See branch table below — this single capture separates candidates 1, 2, 3 |
| B4 | Repeat B3 on the *other* CC line if the cable orientation put activity on CC2 | Same branches |

**B3 branch table** (assuming the charger idles with 3 A Rp; scale by the table in
candidate 1 for other Rp values):

| Observation on the active CC line | Reading |
|---|---|
| CC ≈ 1.68 V after plug, drops to ≈ 0.84 V within ~100 ms of VBUS rising, then VBUS cycles off/on at roughly 0.5–2 Hz | **Candidate 1 confirmed on this charger**: internal Rd landed in parallel, source read "Rd removed", detached, chip lost power, loop |
| CC ≈ 1.68 V, drops to ≈ 0.84 V, VBUS stays 5 V, BMC bursts visible but no 15 V step | Source tolerates 2.55 kΩ but PD exchange dies — look for missing GoodCRC (candidate 3 partially open? U1 dead to PD?); capture longer, and observe `ATTACH` on J3 pad 6 — note it is open-drain with **no pull-up on this board** (net `ATT` = `U1.11 J3.6` only), so first add a temporary 10 kΩ pull-up from J3 pad 6 to VREG_2V7 (J3 pad 3); asserted = pulled low |
| CC ≈ 1.68 V and **stays** ≈ 1.68 V after VBUS rises (no halving), no PD | U1's Rd never appeared on the connector: chip-side CC is disconnected (**candidate 3**) even though A1 passed at DC — re-probe A1 warm, inspect D4 joints |
| VBUS steps toward 15 V then collapses hard, possibly with an audible/thermal event at D4, charger retries or latches off | **Negotiation works; candidate 2 is the blocker.** Confirm with A2 afterward (D4 likely now damaged) |
| CC attach fine, VBUS solid 5 V, `ATTACH` asserts low, BMC visible both directions, contract to 15 V never requested | Re-check B2 (NVM) — this is the candidate-4 shape |

### Stage C — bodge tests (only after A/B, in this order)

| # | Bodge | Validity condition | Expected |
|---|---|---|---|
| C1 | **Lift D4 pin 5** from its pad (leave pins 1/2/3/4/6 soldered — flow-through and GND stay intact, only the 6 V zener rail disconnects). Alternative: remove D4 entirely and bridge pads 1↔6 and 3↔4 with fine wire | Valid on its own — removes candidate 2 without touching CC continuity. ESD protection on CC is degraded at the bench (acceptable: U1's CC pins are rated 22 V short-to-VBUS, DS12499 features) | If B3 showed the 15 V-collapse branch: retest now brings full 15 V and live rails → **done, candidate 2 was the (final) blocker**. Otherwise proceed to C2 |
| C2 | **Restore the ST reference termination**: remove R17 and R18 (kills the external Rd) **and** remove R19 and R20 **and** wire CC1DB↔CC1 (J3 pad 1 → R17 pad 1) and CC2DB↔CC2 (J3 pad 2 → R18 pad 1) | **Removing R17/R18 alone is NOT a valid test** — with DB pins grounded there would be no unpowered Rd at all, the source would never apply VBUS, and the board would look dead for an unrelated reason. The DB rewire must be part of the same bodge so the dead-battery termination replaces the external Rd (DS12499 §2.2.2/§3.5) | Plug the PD charger (with C1 already done): attach via DB termination, CC sits at single-Rd voltage (≈ 1.68 V at 3 A Rp) with **no halving step**, PD negotiates, VBUS → 15 V, VBUS_EN_SNK pulls low, rails live → **candidate 1 confirmed as the v4 blocker and the v5 fix is validated** |
| C3 | If C2 instead shows CC1 dragged to ≈ 0 V and no attach | This is the one outcome that would **rehabilitate the v2 "bad CC1DB" conclusion for this batch too** | Swap U1 with a known-good STUSB4500 (e.g. from a SparkFun breakout) and repeat C2; also measure the removed chip's CC1DB/CC2DB to GND with recorded polarity/current for the record |
| C4 | After any success: verify the full chain at 15 V — TP6 ≈ 15 V, VBUS_OUT ≈ 15 V, Q1 gate ≈ 5.4 V (Vgs ≈ −9.6 V), +12/−12/+5 rails up | Confirms no second-order blockers downstream of the front end |

## What this pass can and cannot catch

This was a static netlist-plus-datasheet review. It **can** catch: wrong-net wiring,
missing/parallel terminations, component ratings violated by design voltages, pin-role
misunderstandings, and invalid bench tests. It **cannot** catch: as-built substitutions
or rotations (only bench A1/A2 and the separate assembly-audit task can), solder
defects, whether the NVM on the dead boards actually contains what the docs say it does
(B2), actual charger behavior inside the CC undefined bands (implementation-specific by
definition), chip authenticity, or dynamic/protocol-timing failures. The USB Type-C
Table 4-36 window values above were cross-checked only against implementation
datasheets, not the spec text itself — verify before treating a marginal reading as
in- or out-of-window. Candidates 1 and 2 are verified *defects*; whether each is *the*
defect that produced the observed v4 symptoms is exactly what Stages A–C decide.

## References

- ST DS12499 Rev 4, STUSB4500 datasheet — Table 1 (pin list; pin 16 "active low";
  pin 18 "From VBUS, receptacle side"), §2.2.1/§2.2.2 (CC HiZ during reset; DB warning),
  §3.4.1–3.4.3 + Table 10 (VBUS monitoring, discharge, VBUS_EN_SNK behavior vs
  `POWER_ONLY_ABOVE_5V`), §3.5 (dead-battery mode, VBUS-only systems), §7.3 Table 22
  (Rd 5.1 kΩ ±10%, RINCC, VTH0.2, IDISUSB 50 mA via external resistor, VMONUSB, TLOAD)
  — [st.com PDF](https://www.st.com/resource/en/datasheet/stusb4500.pdf)
- ST USBLC6-2 datasheet — Table 3 (VRM 5 V, VBR 6 V min at 1 mA VBUS-GND, VCL 12 V at
  1 A; later revisions list VRWM 5.25 V), Figure 1 (functional diagram: 1↔6 / 3↔4
  flow-through, VBUS-GND zener) — [st.com PDF](https://www.st.com/resource/en/datasheet/usblc6-2.pdf)
- USB Type-C Cable and Connector Specification R2.0 — §4.11.2 (Rd 5.1 kΩ ±20%),
  Table 4-36 (source-perspective CC windows; verify — reconstructed here via the onsemi
  FUSB3307/FUSB301 datasheets' source comparator bands)
- [PCBA v2 Debug Report](./pcba-v2-debug.md) — the original CC1DB evidence re-examined above
- [v3 USB-PD Failure Diagnosis](./v3-pd-failure-diagnosis.md) — pin-18 root cause, fixed in v4 and re-confirmed here
- [NVM Programming Setup](./nvm-programming.md) — programmed values, read-back procedure
- [STUSB4500 pinout guide](./stusb4500-pinout.md) — pin-by-pin reference

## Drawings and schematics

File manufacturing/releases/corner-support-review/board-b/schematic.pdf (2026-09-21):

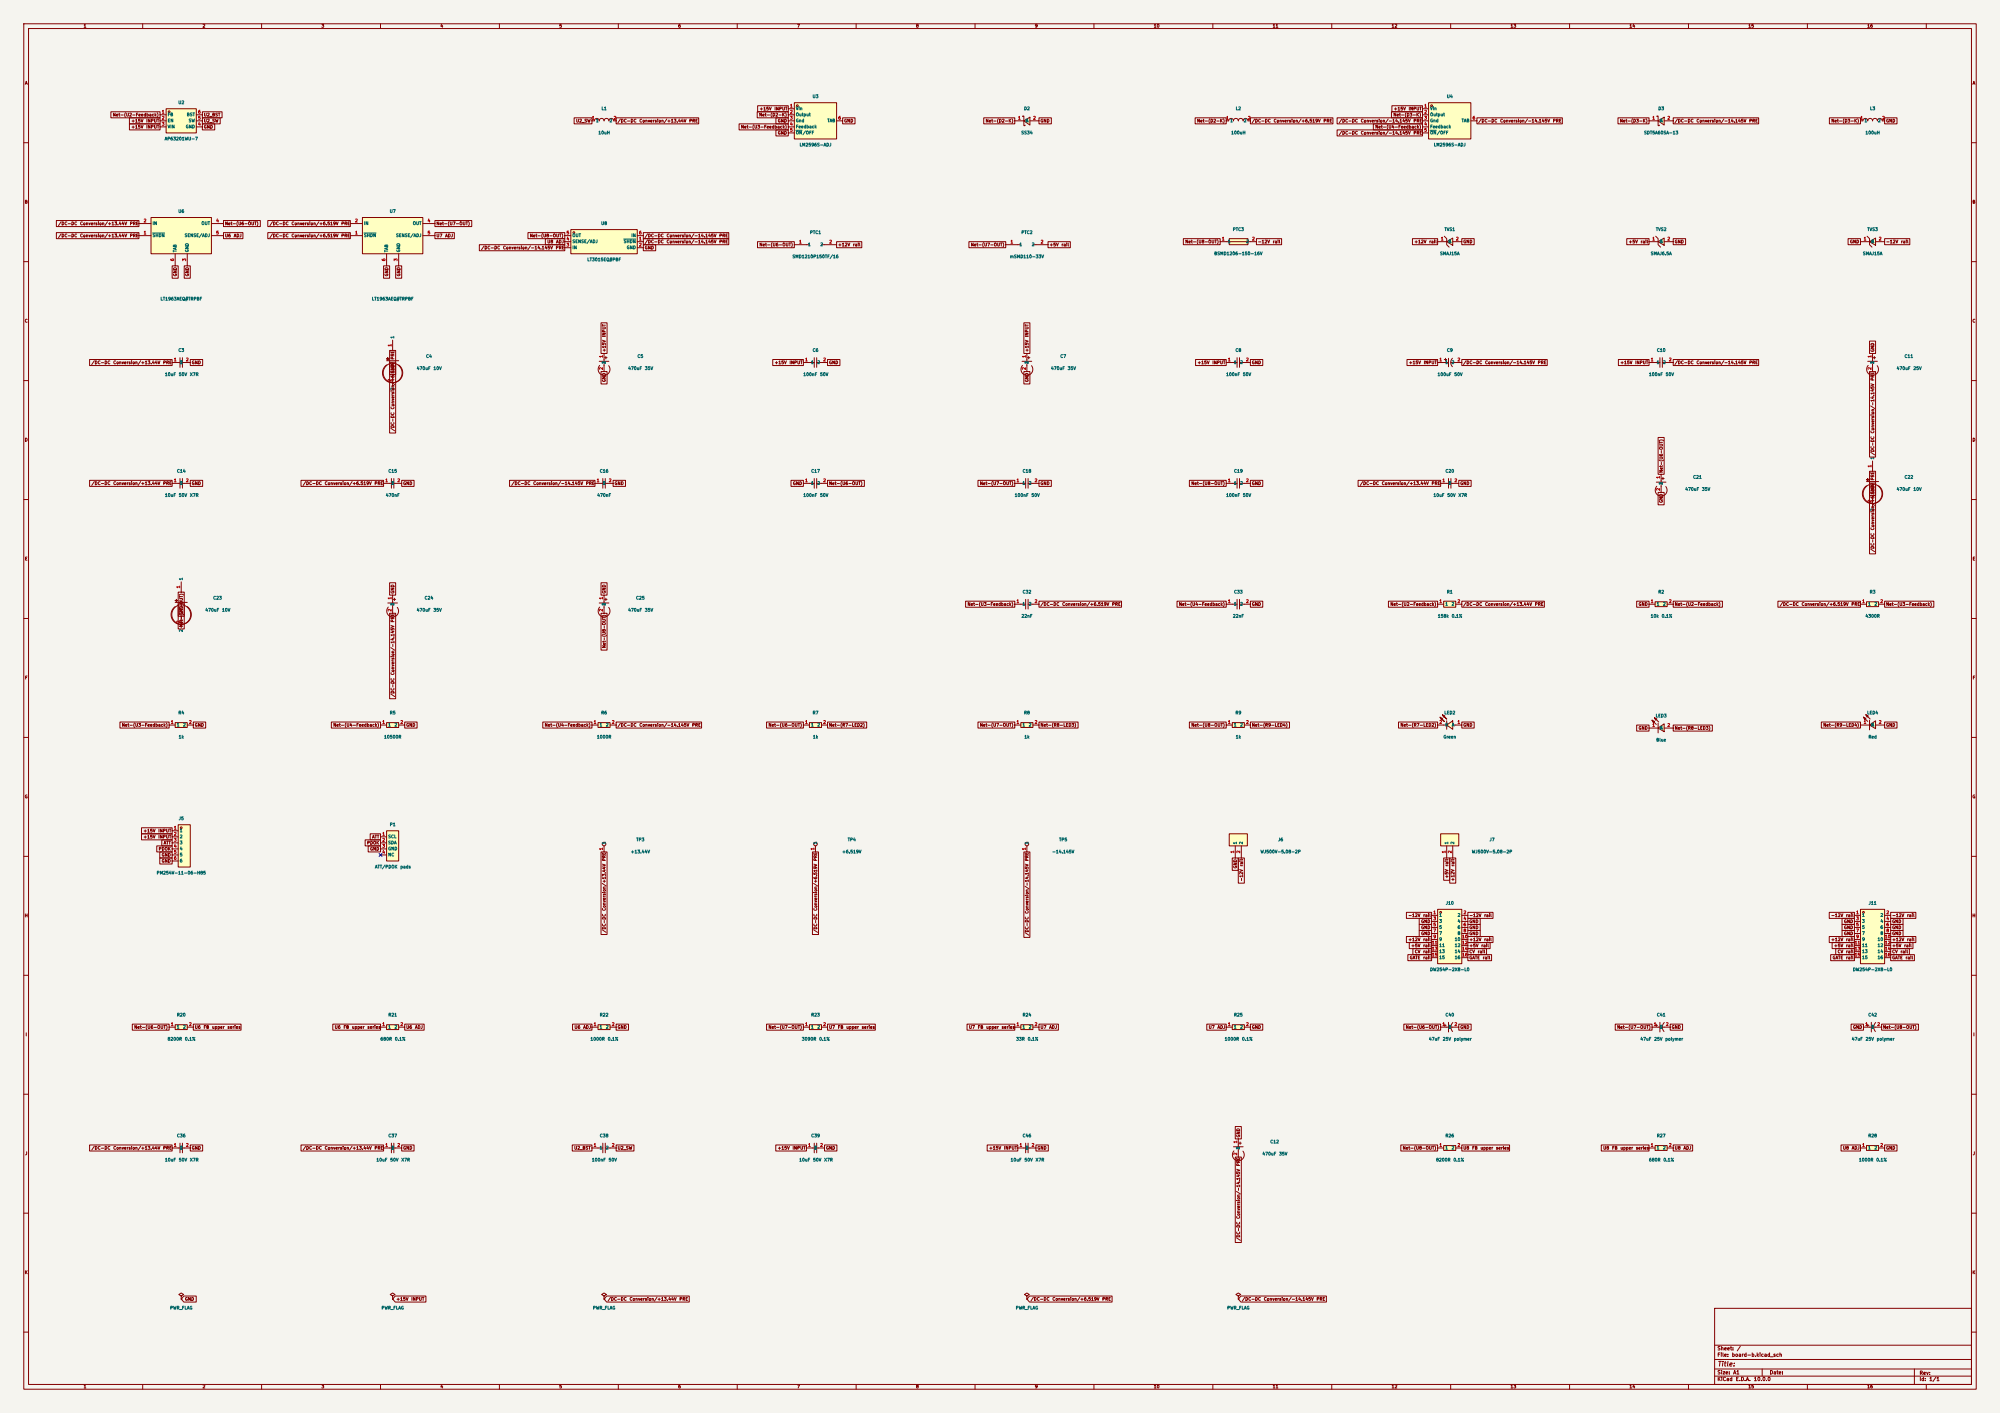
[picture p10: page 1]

GND /DC-DC Conversion/+13.44V PRE /DC-DC Conversion/-14.145V PRE /DC-DC Conversion/-14.145V PRE Net-(U8-OUT)

/DC-DC Conversion/-14.145V PRE GND GND /DC-DC Conversion/+6.519V PRE GND

/DC-DC Conversion/-14.145V PRE

GND /DC-DC Conversion/-14.145V PRE

/DC-DC Conversion/-14.145V PRE Net-(U8-OUT)

/DC-DC Conversion/+13.44V PRE

GND /DC-DC Conversion/+13.44V PRE

+5V rail /DC-DC Conversion/+13.44V PRE

GATE rail /DC-DC Conversion/+6.519V PRE

GND -12V rail GATE rail GND
GND

Size: A1 | Rev:
KiCad E.D.A. 10.0.0 | Id: 1/1

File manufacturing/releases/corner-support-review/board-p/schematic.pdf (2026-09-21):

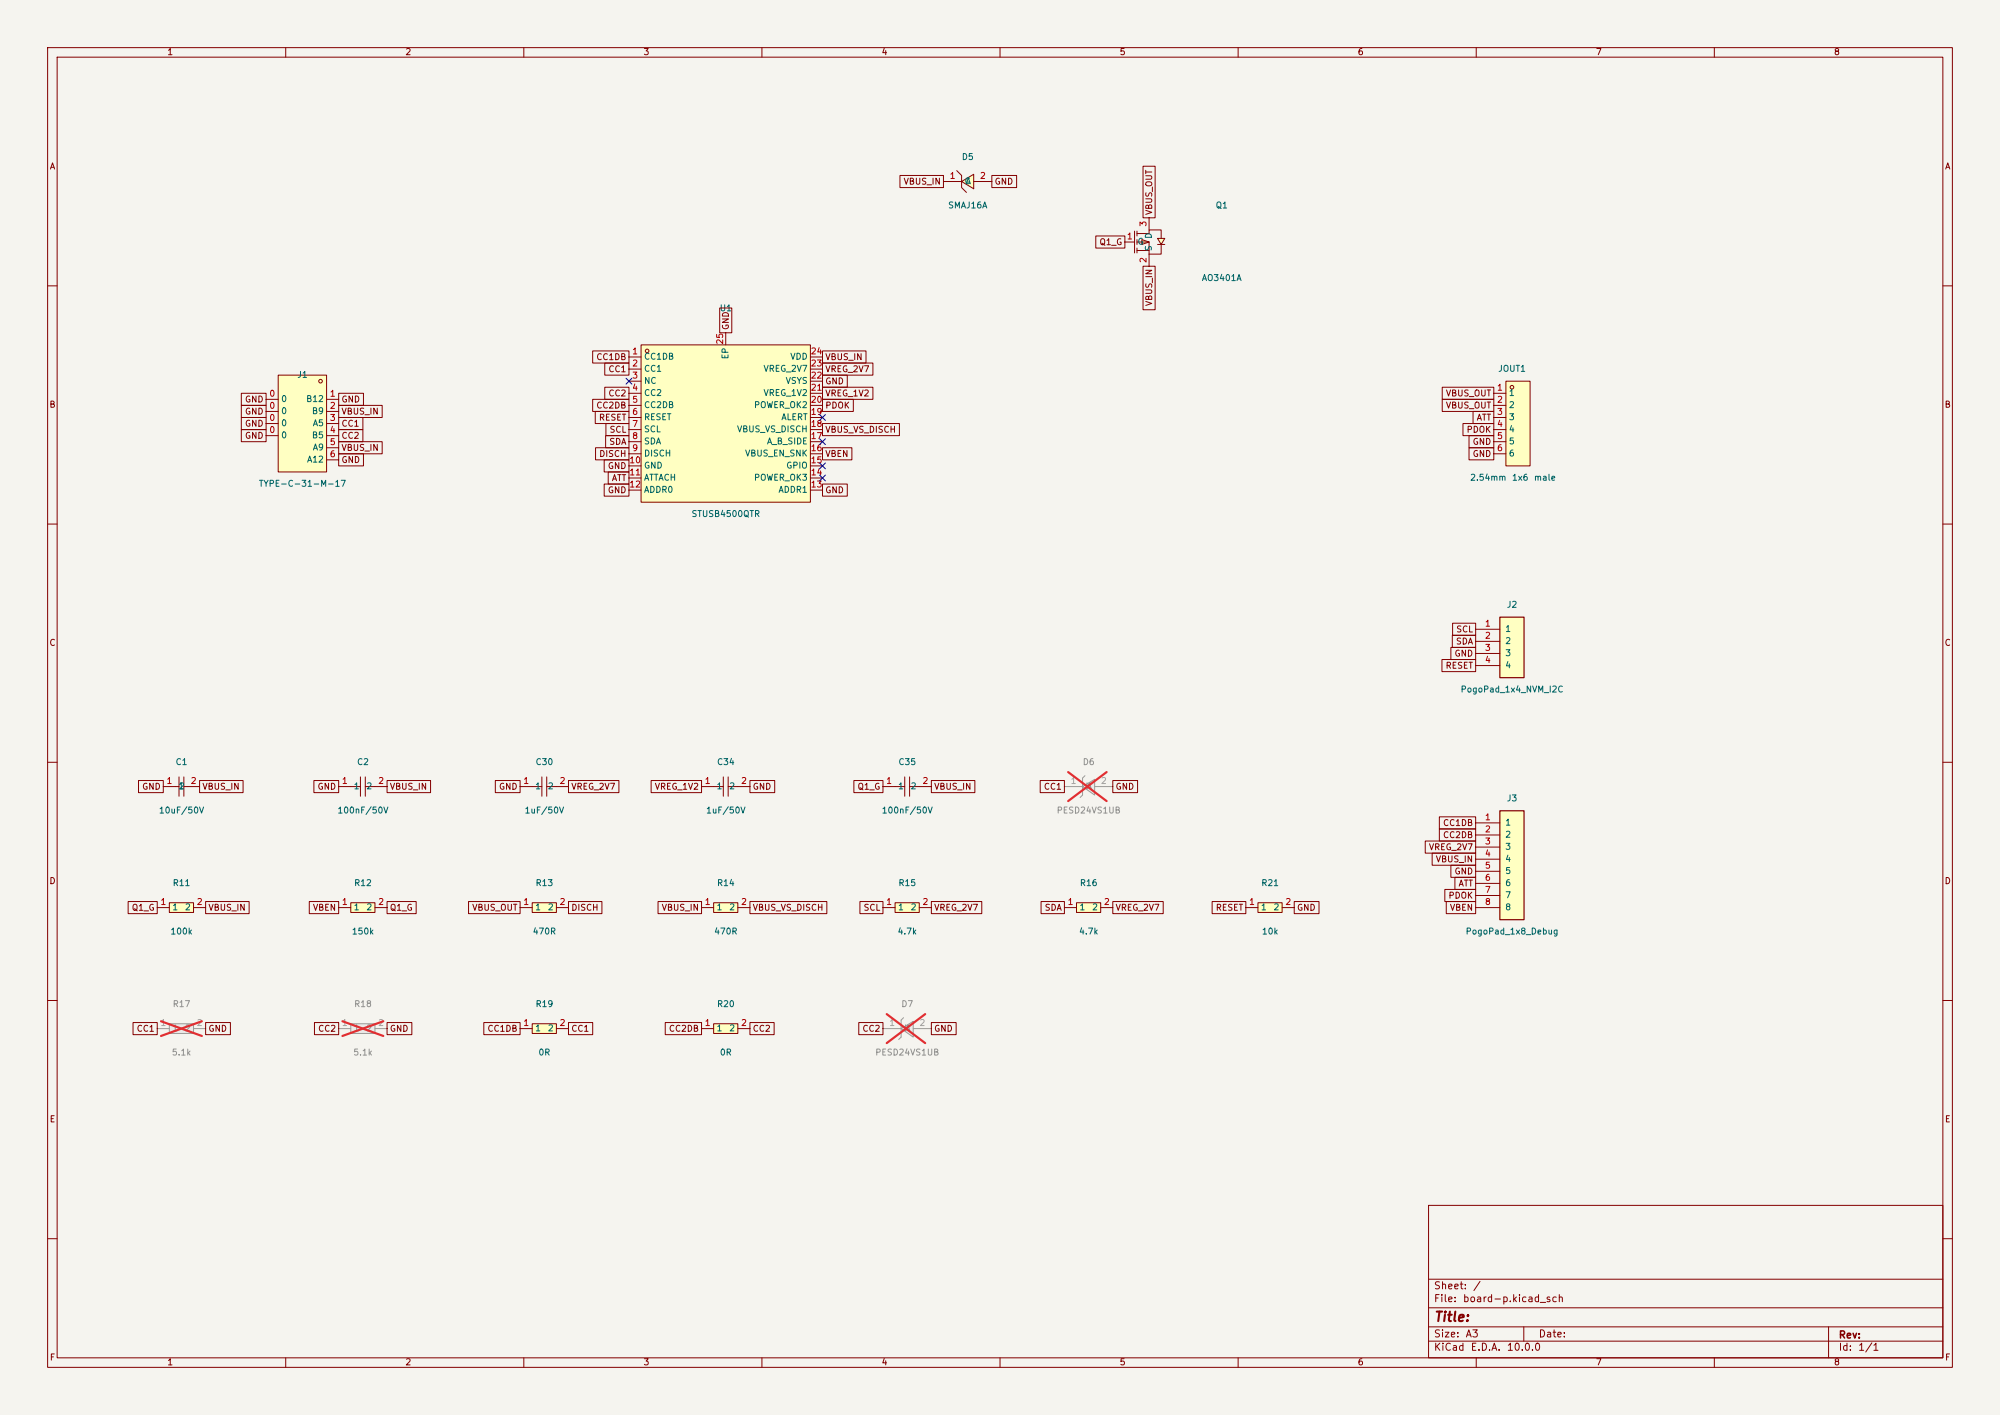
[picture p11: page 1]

SCL SDA RESET ATT GND

SCL SDA RESET GND

Size: A3 | Rev: | F Date:
KiCad E.D.A. 10.0.0 | Id: 1/1

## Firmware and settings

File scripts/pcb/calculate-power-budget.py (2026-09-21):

#!/usr/bin/env python3
"""Reproduce renewal electrical screening; no simulation or bench qualification."""
import argparse
import hashlib
import json
import math
import runpy
import sys
from pathlib import Path

ROOT = Path(__file__).resolve().parents[2]
sys.path.insert(0, str(ROOT/'scripts/schgen'))
from sexp import atom, find_all, load


def require_pcb_part(board, reference, expected_lcsc):
    path = ROOT/'boards'/board/(board+'.kicad_pcb')
    found = []
    for footprint in find_all(load(path), 'footprint'):
        properties = {atom(item[1]): atom(item[2]) for item in find_all(footprint, 'property')}
        if properties.get('Reference') == reference:
            found.append(properties.get('LCSC'))
    if found != [expected_lcsc]:
        raise ValueError(f'{board}/{reference}: current PCB must contain {expected_lcsc} before calculating')
    return hashlib.sha256(path.read_bytes()).hexdigest()


def divider(top, bottom, tolerance):
    return {
        'minimum_v': 1.18 * (1 + top * (1 - tolerance) / (bottom * (1 + tolerance))),
        'nominal_v': 1.23 * (1 + top / bottom),
        'maximum_v': 1.28 * (1 + top * (1 + tolerance) / (bottom * (1 - tolerance))),
    }


def inverter(vin, vout, iout, vf):
    # Approximate CCM volt-second/charge balance including 25C winding DCR.
    # z=1-D: (A+B)*z^2-A*z+Iout*R=0, A=Vin-Vsat, B=|Vout|+Vf.
    vsat, inductance, frequency, dcr = 1.5, 80e-6, 117000, 0.185
    a, b = vin - vsat, vout + vf
    discriminant = a*a - 4*(a+b)*iout*dcr
    if a <= 0 or discriminant <= 0:
        raise ValueError('No feasible low-current CCM solution in this screen')
    off_fraction = (a + math.sqrt(discriminant)) / (2*(a+b))
    duty = 1 - off_fraction
    average = iout / off_fraction
    ripple = (a - average*dcr) * duty / (inductance * frequency)
    rms = math.sqrt(average**2 + ripple**2 / 12)
    copper_loss = rms**2 * dcr
    switch_loss, diode_loss = vsat * average * duty, vf * iout
    modeled_input_power = vout*iout + copper_loss + switch_loss + diode_loss
    return {
        'vin_v': vin, 'vout_magnitude_v': vout, 'output_current_a': iout,
        'duty_cycle': duty, 'inductor_average_a': average,
        'inductor_ripple_pp_a': ripple, 'inductor_peak_a': average + ripple / 2,
        'inductor_rms_a': rms, 'inductor_copper_loss_w_at_25c_max_dcr': copper_loss,
        'switch_conduction_loss_w': switch_loss,
        'diode_conduction_loss_w': diode_loss,
        'input_current_charge_balance_a': duty * average,
        'input_current_including_ripple_copper_loss_a': modeled_input_power/vin,
        'modeled_input_power_w': modeled_input_power,
        'modeled_conduction_efficiency': vout*iout/modeled_input_power,
        'model_limits': '25C DCR and diode maximum at 5A/25C are screening assumptions at this waveform, not a full-temperature guarantee. Switching/core/quiescent/hot-copper/reverse-leakage losses and parasitic overshoot are omitted; predicted input current is not an upper bound.',
        'minimum_switch_current_limit_margin_a': 3.4 - average - ripple / 2,
        'inductor_heat_rating_margin_a': 4.5 - rms,
        'inductor_saturation_rating_margin_a': 8.5 - average - ripple / 2,
    }


def main():
    parser = argparse.ArgumentParser(description=__doc__)
    parser.add_argument('--output', type=Path, default=ROOT/'manufacturing/power-budget.json')
    args = parser.parse_args()
    protection_path = ROOT/'.claude/skills/component-renewal-input-protection/facts.json'
    protection_facts = {fact['fact_id']: fact for fact in json.loads(protection_path.read_text())['facts']}
    vf_fact = protection_facts['fact-c3024223-vf-max-5a-25c']
    vf = vf_fact['value']
    clamp = protection_facts['fact-c74561-clamp']['value']
    diode_reverse = protection_facts['fact-c3024223-vrrm']['value']
    standoff = protection_facts['fact-c74561-standoff']['value']
    ldo_facts = {fact['fact_id']: fact for fact in json.loads((ROOT/'.claude/skills/component-renewal-ldos/facts.json').read_text())['facts']}
    negative_reference = ldo_facts['fact-c666306-reference-band']['value']
    negative_bias_a = ldo_facts['fact-c666306-adj-bias-max']['value']['max'] * 1e-9
    negative_dropout = ldo_facts['fact-c666306-dropout-max-1a5']['value']
    negative_top, negative_bottom, negative_resistor_hot_tolerance = 8200 + 680, 1000, .0035
    # Adjustable LT3015: |VOUT| = |VADJ| * (1 + Rtop/Rbottom) +/- IADJ * Rtop; the bias limit is a 25 C-only figure.
    out_negative = {
        'minimum_magnitude_v': -negative_reference['max'] * (1 + negative_top * (1 - negative_resistor_hot_tolerance) / (negative_bottom * (1 + negative_resistor_hot_tolerance))) - negative_bias_a * negative_top * (1 + negative_resistor_hot_tolerance),
        'nominal_magnitude_v': 1.22 * (1 + negative_top / negative_bottom),
        'maximum_magnitude_v': -negative_reference['min'] * (1 + negative_top * (1 + negative_resistor_hot_tolerance) / (negative_bottom * (1 - negative_resistor_hot_tolerance))) + negative_bias_a * negative_top * (1 + negative_resistor_hot_tolerance),
        'divider': {'top_refs': ['R26', 'R27'], 'top_ohm': negative_top, 'bottom_ref': 'R28', 'bottom_ohm': negative_bottom, 'tolerance_plus_tcr_fraction': negative_resistor_hot_tolerance},
        'conditions': 'Full-temperature ADJ reference band with opposed 0.35% resistor tolerance/TCR and the 25°C-only 200 nA ADJ-bias limit; not a guaranteed full-temperature output band.',
    }
    scenarios = []
    for top, tolerance in [(10600, .01), (10500, .001), (10600, .001), (10500, .0035)]:
        bounds = divider(top, 1000, tolerance)
        high = bounds['maximum_v']
        pass_loss = (high - out_negative['minimum_magnitude_v']) * .8
        # 70 mA is a published 1.5 A/dropout test maximum, not an interpolated
        # guaranteed 0.8 A normal-operation value. Both cases stay explicitly open.
        ground_loss_screen = high * .07
        thermal_screen = pass_loss + ground_loss_screen
        scenarios.append({
            'divider_top_ohm': top, 'divider_bottom_ohm': 1000,
            'resistor_tolerance_fraction': tolerance, 'bounds': bounds,
            'resistor_temperature_note': '0.35% combines initial 0.1% and 25 ppm/°C over 100 °C; other rows use initial tolerance only' if tolerance == .0035 else 'Initial tolerance only; see combined TCR case for hot-operation screening',
            'formula': 'Vref * (1 + Rtop/Rbottom); reference 1.18/1.23/1.28 V, resistor extrema opposed',
            'reference_conditions': 'UMW LM2596S-ADJ full-temperature limits; reference test at VOUT=3V, 0.2..3A load; application regulation/ripple still requires verification',
            'headroom_to_max_programmed_output_plus_dropout_v': bounds['minimum_v'] - out_negative['maximum_magnitude_v'] - negative_dropout,
            'negative_ldo_pass_loss_w': pass_loss,
            'negative_ldo_ground_loss_screen_w': ground_loss_screen,
            'negative_ldo_total_thermal_screen_w': thermal_screen,
            'maximum_effective_theta_ja_at40c_ambient_c_per_w': (125 - 40) / thermal_screen,
            'thermal_status': 'SCREENING ONLY: 70 mA is the 1.5 A/dropout test-point bound, not a guaranteed interpolated 0.8 A normal-operation value; copper/coupling/ambient validation open',
            'inductor_screen_load_only': inverter(14, high, .8, vf),
            'inductor_screen_with_ground_current_bracket': inverter(14, high, .8 + .07 + .00013 + high/(top + 1000), vf),
            'normal_high_line_effective_voltage_v': 15.75 + high,
            'normal_high_line_u4_operating_margin_v': 40 - (15.75 + high),
            'normal_high_line_d3_vrrm_margin_v': diode_reverse - (15.75 + high),
            'tvs_table_point_effective_voltage_v': clamp + high,
            'tvs_table_point_u4_absmax_margin_v': 45 - (clamp + high),
            'tvs_table_point_d3_vrrm_margin_v': diode_reverse - (clamp + high),
            'tvs_table_point_c9_50v_margin_v': 50 - (clamp + high),
            'nominal_output_capacitor_energy_j': .5 * 1410e-6 * bounds['nominal_v']**2,
        })
    spec = runpy.run_path(str(ROOT / 'scripts/schgen/board_b_spec.py'))
    pd_spec = runpy.run_path(str(ROOT / 'scripts/schgen/board_p_spec.py'))
    if spec['COMPONENTS']['D3'][2] != 'C3024223' or pd_spec['COMPONENTS']['D5'][2] != 'C74561':
        raise ValueError('Protection screen requires the selected D3/D5 identities in both current specs')
    protected_pcbs = {'board-b': require_pcb_part('board-b','D3','C3024223'),
                      'board-p': require_pcb_part('board-p','D5','C74561')}
    selected_negative = {
        'top': {'ref': 'R5', 'mpn': 'RT0603BRD0710K5L', 'lcsc': 'C861077', 'resistance_ohm': 10500, 'tolerance_fraction': .001},
        'bottom': {'ref': 'R6', 'mpn': 'RT0603BRD071KL', 'lcsc': 'C110776', 'resistance_ohm': 1000, 'tolerance_fraction': .001},
        'initial_tolerance_scenario_index': 1,
        'temperature_screen_scenario_index': 3,
        'tcr_assumption_ppm_per_c': 25,
        'maximum_delta_from25c': 100,
        'spec_identity_matches': spec['COMPONENTS']['R5'][2] == 'C861077' and spec['COMPONENTS']['R6'][2] == 'C110776',
    }
    five_pre = divider(4300, 1000, .01)
    positive_pre = {'minimum_v': .792 * (1 + 15.8 * (1 - .00425) / (1 + .002625)), 'nominal_v': .8 * 16.8, 'maximum_v': .808 * (1 + 15.8 * (1 + .00425) / (1 - .002625))}
    # Wider rail/load cases include fitted indicator and feedback overhead.
    resistor_hot_tolerance = .0035
    def adjusted_output(top):
        low = 1.174 * (1 + top * (1 - resistor_hot_tolerance) / (1000 * (1 + resistor_hot_tolerance)))
        high = 1.246 * (1 + top * (1 + resistor_hot_tolerance) / (1000 * (1 - resistor_hot_tolerance))) + 10e-6 * top * (1 + resistor_hot_tolerance)
        return {'minimum_v': low, 'maximum_v': high, 'conditions': 'Full-temperature reference and resistor/TCR screen combined with a 25°C-only 10µA ADJ-bias ceiling and assumed nonnegative bias; not a guaranteed full-temperature output band.'}
    out12, out5 = adjusted_output(8200 + 680), adjusted_output(3090 + 33)
    pre5_hot = divider(4300, 1000, .02)
    pre_negative_hot = scenarios[3]['bounds']
    led12, led5, led_negative = out12['maximum_v']/980, out5['maximum_v']/980, out_negative['maximum_magnitude_v']/980
    load12 = 1.2 + led12 + 1.246 / (1000 * (1 - resistor_hot_tolerance))
    load5 = .5 + led5 + 1.246 / (1000 * (1 - resistor_hot_tolerance))
    load_negative = .8 + led_negative + out_negative['maximum_magnitude_v'] / (negative_top + negative_bottom)
    input12 = load12 + .12 + positive_pre['maximum_v']/(168000 * .997375)
    input5 = load5 + .12 + pre5_hot['maximum_v']/(5300 * .98)  # conservative 1.5 A table bracket; fitted load exceeds 0.5 A
    input_negative = load_negative + .07 + .00013 + pre_negative_hot['maximum_v']/(11500 * .9965)
    stage_power12 = positive_pre['maximum_v'] * input12
    stage_power5 = pre5_hot['maximum_v'] * input5
    stage_power_negative = pre_negative_hot['maximum_v'] * input_negative
    stage_total = stage_power12 + stage_power5 + stage_power_negative
    thermal12 = (positive_pre['maximum_v'] - out12['minimum_v']) * load12 + positive_pre['maximum_v'] * .12
    thermal5 = (pre5_hot['maximum_v'] - out5['minimum_v']) * load5 + pre5_hot['maximum_v'] * .12
    thermal_negative = (pre_negative_hot['maximum_v'] - out_negative['minimum_magnitude_v']) * load_negative + pre_negative_hot['maximum_v'] * .07
    negative_screens = [inverter(vin,pre_negative_hot['maximum_v'],input_negative,vf) for vin in (14,14.25,15,15.75)]
    for screen in negative_screens:
        remaining = screen['vin_v']*3 - screen['modeled_input_power_w']
        screen['remaining_positive_converter_input_budget_w'] = remaining
        screen['minimum_positive_weighted_efficiency_for_3a_screen'] = (stage_power12+stage_power5)/remaining
    data = {
        'schema_version': 1,
        'status': '15V-ONLY RENEWAL PROTOTYPE SCREEN; selected parts and conditioned margins are not full-chain qualification',
        'selected_negative_divider': selected_negative,
        'positive_pre_regulator_screen': {'selected_converter':'AP63201', 'selected_lcsc':'C2071044', 'top_ohm':158000, 'bottom_ohm':10000, 'top_tolerance_plus_tcr_fraction':.00425, 'bottom_tolerance_plus_tcr_fraction':.002625, 'temperature_delta_c':65, 'reference_bounds_v':[.792,.808], 'bounds':positive_pre, 'screening_vin_after_front_end_v':14, 'minimum_high_duty_drop_allowance_v':14-positive_pre['maximum_v'], 'status':'Reference/resistor/TCR screen only; real high-duty operation, switch+inductor voltage drop, capacitor DC-bias derating, ripple and low-line behavior require exact-part evidence and qualification'},
        'five_volt_pre_regulator_screen': {'selected_r3_lcsc':'C23159', 'r3_ohm':4300, 'r4_ohm':1000, 'tolerance_fraction':.01, 'bounds':five_pre, 'spec_identity_matches':spec['COMPONENTS']['R3'][2] == 'C23159', 'maximum_ldo_pass_loss_w_assuming_output_min4v8':(five_pre['maximum_v'] - 4.8) * .5, 'status':'Initial-tolerance upstream screen; the whole-chain section includes wider TCR and conditional LT1963A reference/divider/bias output bounds. Actual ripple and full-temperature behavior remain open.'},
        'rated_targets': {'plus12': {'voltage_v':12,'current_a':1.2}, 'minus12': {'voltage_v':-12,'current_a':.8}, 'plus5': {'voltage_v':5,'current_a':.5}},
        'nominal_output_power_w': 26.5,
        'whole_chain_current_thermal_screen': {
            'plus12_output_band_conditional':out12, 'plus5_output_band_conditional':out5, 'minus12_output_band_conditional':out_negative,
            'plus5_pre_hot_tolerance_bounds':pre5_hot,
            'led_current_upper_bounds_a':{'plus12':led12,'plus5':led5,'minus12':led_negative},
            'led_assumption':'Zero LED forward drop and 1 kΩ resistor at 980 Ω deliberately overestimate indicator current; includes initial 1% plus 100 ppm/°C over 100°C.',
            'ldo_output_loads_including_indicators_feedback_a':{'plus12':load12,'plus5':load5,'minus12':load_negative},
            'converter_output_loads_with_ground_current_brackets_a':{'plus12':input12,'plus5':input5,'minus12':input_negative},
            'pre_regulator_power_w':{'plus12':stage_power12,'plus5':stage_power5,'minus12':stage_power_negative,'total':stage_total},
            'minimum_weighted_converter_efficiency_at14v_3a':stage_total/(14*3),
            'ldo_dissipation_screen_w':{'plus12':thermal12,'plus5':thermal5,'minus12':thermal_negative},
            'maximum_effective_theta_ja_at40c_ambient_c_per_w':{'plus12':85/thermal12,'plus5':85/thermal5,'minus12':85/thermal_negative},
            'negative_inductor_screen_with_all_overhead':inverter(14,pre_negative_hot['maximum_v'],input_negative,vf),
            'negative_input_screens': negative_screens,
            'status':'Conservative screening cases, not simultaneous guaranteed worst cases. Positive IADJ only bounded at 25°C; higher-load ground-current brackets are not exact target-load maxima. Converter switching/core/hot-resistance losses and actual source/board minimum voltage still require validation.'},
        'pd_contract': {'nominal_v':15,'current_a':3,'nominal_power_w':45,'minus5pct_source_power_w':42.75,'normal_source_range_v':[14.25,15.75],'scope':'Prototype permits 15V ±5% normal source input only; the 14V B-input loss screen is separate. 20V is unsupported, including accidental factory-NVM negotiation.','first_power':'Mandatory current-limited 5V-only source with B disconnected; resolve programming-jig voltage/pull-up load, program and read back the 15V-only NVM policy before using any 15V-capable PD source.'},
        'negative_stage_scenarios': scenarios,
        'inductor_screen_assumptions': {'vin_after_front_end_v':14,'minimum_l_h':80e-6,'minimum_frequency_hz':117000,'switch_saturation_v':1.5,'diode_forward_v':vf,'diode_forward_fact':vf_fact,'max_dcr_25c_ohm':.185,'heat_rating_a':4.5,'saturation_rating_a':8.5,'notes':'Approximate CCM including average winding DCR in duty balance and ripple copper loss in input power. Hot DCR, magnetic bias, switching/core/quiescent losses, PCB parasitics, component test-point conditions, and actual input minima remain open.'},
        'thermal_layout_requirement': {'historical_proposal_u8_copper_mm2_each_side':1280,'historical_expansion_goal_mm2':2500,'status':'Use current source-locked filled areas below; historical proposals are not achieved-area claims. Effective theta-JA is not inferred from area alone.','lt3015_ddpak_published_test_conditions':{'top2500_back2500_mm2_theta_ja':14,'top1000_back2500_mm2_theta_ja':16,'top225_back2500_mm2_theta_ja':19,'board_area_mm2':2500}},
        'capacitor_requirements': {'lt3015_output':{'minimum_effective_uf':10,'maximum_esr_ohm':.5},'lt1963a_output':{'minimum_effective_uf':10,'maximum_esr_ohm':3},'status':'Selected polymer parts have component evidence; installed effective capacitance/ESR over temperature and load-step stability remain qualification requirements.'},
        'open_qualification': [
            'AP63201 full high-duty low-line behavior, actual path voltage drop and final whole-chain input-current budget.',
            'Negative LM2596 startup may reach about 4.5 A for at least 2 ms versus 3 A PD contract; steady-state margins do not prove startup.',
            'SMAJ16A 26V is a 15.4A,10/1000us,25C table point, not a universal hot or installed-surge ceiling. Source/rail/switch/gate waveforms, clamp current and temperature remain unqualified; VBR temperature coefficient is not a VC correction formula.',
            'Mandatory 5V-only first power/programming with B disconnected, then verified 15V-only NVM image/readback/reload before a PD-capable source; 20V unsupported. Resolve VREG_2V7 programming pull-up loading.',
            'Actual thermal copper, heatsinking, ambient, coupled regulator losses, and full-load temperatures.',
            'Converter reference tolerance, ripple, inductor current waveform, and LDO output-capacitor ESR/stability.',
            'New D3 hot reverse leakage: maximum0.5mA at60V/25C and typical50mA at60V/125C do not provide a guaranteed leakage bound at the installed hot reverse waveform. Reverse-leakage heating is not included in the conduction model.',
            'PTC hot hold-current, output rail drop and fault trip/recovery tests.',
        ],
        'evidence': [
            {'owner':'component-lm2596s-adj-c347423','fact_ids':['fact-lm2596-fb-vref-min-full-temp','fact-lm2596-fb-vref-max-full-temp','fact-lm2596-current-limit','fact-lm2596-vsat-max','fact-lm2596-oscillator-frequency','fact-lm2596-inverting-startup-current']},
            {'owner':'component-cya1265-100uh-c19268674','fact_ids':['fact-cya1265-inductance','fact-cya1265-isat','fact-cya1265-idc-heat-rating','fact-cya1265-rdc-max']},
            {'owner':'component-ss34-c8678','scope':'Retained B D2 and retired old D3 comparison only','fact_ids':['fact-ss34-vrrm','fact-ss34-vf']},
            {'owner':'component-renewal-input-protection','fact_ids':['fact-c74561-standoff','fact-c74561-clamp','fact-c74561-vbr-tempco-typ','fact-c3024223-vrrm','fact-c3024223-vf-max-5a-25c','fact-c3024223-vf-max-5a-125c','fact-c3024223-leakage-max-25c','fact-c3024223-leakage-typ-125c']},
            {'url':'https://www.analog.com/media/en/technical-documentation/data-sheets/3015fb.pdf','locator':'printed pages 5, 16, 19: output guarantee/dropout/GND current, COUT ESR, DD-Pak thermal test boards','retrieved':'2026-09-20'},
            {'url':'https://www.analog.com/media/en/technical-documentation/data-sheets/1963aff.pdf','locator':'printed pages 14-15: output capacitor minimum and ESR; high-output-voltage minimum ESR','retrieved':'2026-09-20'},
        ],
        'source_generator': 'scripts/pcb/calculate-power-budget.py',
        'board_b_spec_sha256': hashlib.sha256((ROOT/'scripts/schgen/board_b_spec.py').read_bytes()).hexdigest(),
        'board_p_spec_sha256': hashlib.sha256((ROOT/'scripts/schgen/board_p_spec.py').read_bytes()).hexdigest(),
        'protection_pcb_source_sha256': protected_pcbs,
    }
    negative_high = pre_negative_hot['maximum_v']
    effective = clamp + negative_high
    data['input_protection_screen'] = {
        'selected_p_tvs': {'mpn':'SMAJ16A','lcsc':'C74561','standoff_v':standoff,'conditioned_clamp_v':clamp,'conditions':protection_facts['fact-c74561-clamp']['conditions']},
        'selected_b_d3': {'mpn':'SDT5A60SA-13','lcsc':'C3024223','reverse_rating_v':diode_reverse,'vf_screen_v':vf,'vf_conditions':vf_fact['conditions']},
        'normal_input_high_v':15.75, 'standoff_margin_over_normal_high_v':standoff-15.75,
        'negative_rail_hot_tcr_max_v':negative_high, 'conditioned_effective_u4_d3_c9_v':effective,
        'conditioned_margins_v':{'stusb_28v_abs':28-clamp,'q1_30v_vds_magnitude':30-clamp,'u4_45v_abs':45-effective,'u4_40v_operating':40-effective,'d3_60v_reverse':diode_reverse-effective,'c9_50v_bridge':50-effective,'35v_input_capacitors':35-clamp,'50v_input_capacitors':50-clamp},
        'ideal_q1_gate_vgs_v':-clamp*100000/(100000+150000),
        'q1_comparison_conditions':'VDS comparison assumes off-state output near0V; VGS assumes asserted VBEN near0V and the ideal100k/150k steady divider. Neither is a measured transient gate/drain/source waveform.',
        'status':'Conditioned arithmetic clears the listed absolute/rated limits. U4 operating range is not maintained at this table point; regulation and survival of a real transient are not certified. STUSB limit retains its mirror-source trust limitation.',
        'diode_hot_reverse_leakage_note':'0.5mA is a maximum at60V/25C;50mA at60V/125C is typical only. Neither is an established installed hot leakage limit, and the forward-conduction model excludes reverse-leakage heating.',
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

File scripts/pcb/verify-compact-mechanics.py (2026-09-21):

#!/usr/bin/env python3
"""Verify Board B screw terminals and top-edge pogo mechanics, without saving it.

Run with KiCad's Python. Import verify_compact_mechanics() to reuse the checks.
The plain rectangular outline follows board_b_layout. A temporary PCB can name its
intended project directory with --project-dir for ${KIPRJMOD} model resolution.
The check covers the terminal models, pin assignments and pogo contacts; actual
wire, screwdriver and programming-clip fit remain unmeasured.
"""
import argparse
from functools import lru_cache
import hashlib
import json
import math
import os
from pathlib import Path
import re
import sys
import wx
_KICAD_APP = wx.GetApp() or wx.App(False)
import pcbnew as p
from board_b_layout import WIDTH, HEIGHT, P1_CENTER, PLACEMENTS, edge_primitives
from pcb_common import pcb_net_name

ROOT = Path(__file__).resolve().parents[2]
TERMINAL_NETS = {'J6': {'1':'GND','2':'-12V rail'}, 'J7': {'1':'+5V rail','2':'+12V rail'}}
POGO_NETS = {'1': 'ATT', '2': 'PDOK', '3': 'GND', '4': None}
RAIL_CONTACTS = {'TP3': '+13.44V PRE', 'TP4': '+6.519V PRE', 'TP5': '-14.145V PRE'}
RAIL_LABEL_PINS = {'-12V':('J6','2'),'GND':('J6','1'),'+12V':('J7','2'),'+5V':('J7','1')}
BACK_RAIL_LABELS = {
    '-12V': {'center_mm':[12.2,46.0], 'size_mm':1.5, 'thickness_mm':.3, 'bold':True},
    'GND': {'center_mm':[11.6,50.5], 'size_mm':1.5, 'thickness_mm':.3, 'bold':True},
    '+12V': {'center_mm':[12.2,58.4], 'size_mm':1.5, 'thickness_mm':.3, 'bold':True},
    '+5V': {'center_mm':[11.8,63.8], 'size_mm':1.5, 'thickness_mm':.24, 'bold':True},
}
CONTRACT_PATH = ROOT / 'boards/board-b/mechanical.json'
TOL = .01


def xy(item):
    q = item.GetPosition()
    return p.ToMM(q.x), p.ToMM(q.y)


def bounds(item):
    b = item.GetBoundingBox()
    return tuple(p.ToMM(v) for v in (b.GetLeft(), b.GetTop(), b.GetRight(), b.GetBottom()))


def close(a, b, tol=TOL):
    return abs(a - b) <= tol


def angle(a):
    return a % 360


def outline_bounds(board):
    """Match all four straight rectangle edges; reject retained notches or extra cuts."""
    edges = [x for x in board.GetDrawings() if x.GetLayer() == p.Edge_Cuts]
    expected = edge_primitives()
    corners=[(0,0),(WIDTH,0),(WIDTH,HEIGHT),(0,HEIGHT),(0,0)]
    rectangle=[{'type':'line','start':list(a),'end':list(b)} for a,b in zip(corners,corners[1:])]
    if expected!=rectangle:
        raise ValueError('Current terminal revision requires the plain rectangular layout contract')
    if len(edges) != len(expected):
        raise ValueError('Edge.Cuts must contain exactly the four rectangle edges')
    def pt(v): return (p.ToMM(v.x), p.ToMM(v.y))
    def same(a,b): return len(a)==len(b) and all(close(x,y,.001) for x,y in zip(a,b))
    remaining = list(edges)
    for want in expected:
        shape = p.SHAPE_T_SEGMENT if want['type']=='line' else p.SHAPE_T_ARC
        matches = [e for e in remaining if e.GetShape()==shape
                   and ((same(pt(e.GetStart()),want['start']) and same(pt(e.GetEnd()),want['end']))
                        or (same(pt(e.GetStart()),want['end']) and same(pt(e.GetEnd()),want['start'])))
                   and (want['type']=='line' or same(pt(e.GetArcMid()),want['mid']))]
        if len(matches)!=1:
            raise ValueError('Missing, duplicate or changed Edge.Cuts primitive: '+str(want))
        remaining.remove(matches[0])
    return 0., 0., float(WIDTH), float(HEIGHT)


@lru_cache(maxsize=8)
def model_points(path):
    """The retained EasyEDA WRL uses KiCad's 0.1-inch model coordinate unit."""
    text = Path(path).read_text()
    result = []
    for block in re.findall(r'point\s*\[([^]]+)\]', text):
        nums = [float(v) for v in re.findall(r'[-+]?(?:\d*\.\d+|\d+)(?:[Ee][+-]?\d+)?', block)]
        if len(nums) % 3:
            raise ValueError('Malformed WRL coordinate triplets')
        result.extend(tuple(nums[i + k] * 2.54 for k in range(3)) for i in range(0, len(nums), 3))
    if not result:
        raise ValueError('No coordinates in the terminal model')
    return result


def model_local_points(fp, project_dir, reviewed):
    models=list(fp.Models())
    if len(models)!=1:raise ValueError('Terminal must carry one reviewed model')
    m=models[0]
    for actual,want,label in [(m.m_Rotation,reviewed['rotation_xyz_deg'],'rotation'),
                              (m.m_Offset,reviewed['offset_xyz_mm'],'offset'),
                              (m.m_Scale,reviewed['scale_xyz'],'scale')]:
        if not all(close(a,b,.001) for a,b in zip((actual.x,actual.y,actual.z),want)):
            raise ValueError('Terminal model '+label+' differs from its reviewed transform')
    # This exact model is installed without a model-node rotation or offset.
    if reviewed['rotation_xyz_deg']!=[0,0,0] or reviewed['offset_xyz_mm']!=[0,0,0] or reviewed['scale_xyz']!=[1,1,1]:
        raise ValueError('Unreviewed terminal model transform contract')
    raw_path=str(m.m_Filename).replace('${KIPRJMOD}',str(project_dir))
    path=Path(os.path.expandvars(raw_path))
    if not path.is_absolute():path=project_dir/path
    path=path.resolve()
    if path.name!=reviewed['file'] or not path.is_file():raise ValueError('Terminal model cannot be resolved: '+str(path))
    raw=model_points(str(path))
    actual=[[min(v[k] for v in raw) for k in range(3)],[max(v[k] for v in raw) for k in range(3)]]
    if any(not close(a,b,.025) for row,want in zip(actual,reviewed['raw_bounds_mm']) for a,b in zip(row,want)):
        raise ValueError('Terminal model geometry differs from the reviewed catalog asset')
    for center in (-2.54,2.54):
        leg=[v for v in raw if v[2]<-1.6 and abs(v[0]-center)<1]
        if not leg:raise ValueError('Terminal model solder leg is absent')
        xy_center=[(min(v[k] for v in leg)+max(v[k] for v in leg))/2 for k in (0,1)]
        if not (close(xy_center[0],center,.025) and close(xy_center[1],0,.025)):
            raise ValueError('Terminal model solder leg does not align with its PCB hole')
    # WRL is right-handed with Y up; footprint-local PCB Y points down.
    return [(v[0],-v[1],v[2]) for v in raw],str(path)
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

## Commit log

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2025-12-27 MDX構文エラーを修正
    MDXコンパイラが <1 をJSXタグとして解釈してエラーになっていた問題を修正。
    <1mVp-p の表記を \<1mVp-p にエスケープして正しく表示されるようにしました。
    修正箇所:
    - doc/docs/inbox/index.md
    - doc/docs/inbox/overview.md
    - doc/docs/inbox/parts-list.md
    エラー詳細:
    - MDX compilation failed: Unexpected character '1' (U+0031) before name
    - '<' 文字がJSX要素の開始として誤認識されていた
2025-12-27 Docusaurusドキュメントを整理・拡充
    - プロジェクト現状とプランドキュメントを追加
    - クイックリファレンスドキュメントを追加
    - INBOXインデックスにプロジェクト管理セクションを追加
    - サイドバー設定を更新（全ドキュメント表示）
    - README.mdを更新（プロジェクト概要を充実）
    - MDX構文エラーを修正（< 文字のエスケープ）
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2025-12-27 Complete English translation and documentation improvements
    - Translate all documentation from Japanese to English
    - Fix MDX compilation errors (replace <1mVp-p with &lt;1mVp-p)
    - Update CLAUDE.md language policy to English-first
    - Change Docusaurus locale from 'ja' to 'en'
    - Flatten sidebar structure for better UX
    - Adjust sidebar width to 240px for better readability
    All documentation is now in English for international accessibility.
    Technical specifications, circuit diagrams, and project status are
    fully translated while maintaining technical accuracy.
2025-12-27 Add documentation guidelines and improve project configuration
    - Create doc/CLAUDE.md with circuit diagram writing rules
    * Use ASCII art in code blocks for circuit diagrams
    * Always include full connection list under diagrams
    * Define component notation and best practices
    - Update root CLAUDE.md with URL reference guidelines
    * Map localhost:3000 URLs to markdown files in /doc/
    * Avoid fetching local URLs, read source files instead
    * Provide URL-to-filepath mapping examples
    - Add .playwright-mcp/ to .gitignore
    * Exclude temporary headless browser cache directory
    * Keep repository clean from testing artifacts
    These guidelines ensure consistent circuit documentation and
    effic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
2025-12-27 Fix LED indicator circuit: change to green LED and correct power source
    - Change LED1 from red to green for better "power good" indication
    - Fix undefined VDD 3.3V source → use +5V rail from Diagram7 output
    - Update LED current calculation: 7.6-8.5mA (safe range)
    - Correct circuit diagram, connection lists, and all documentation
    - Update BOM: C84256 (red) → C2286 (green LED)
    - Update resistor value: keep 330Ω (correct for +5V rail)
    The PG pin is open-drain and pulls LOW when power is good, completing
    the circuit: +5V → R1 → LED → PG(GND). Green LED indicates safe 15V.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
2025-12-27 Fix BOM to match circuit diagrams and add missing components
    Comprehensive BOM verification and correction to ensure all components
    match the circuit diagrams exactly.
    Critical fixes:
    1. LED1: Changed C84256 (Red) → C2286 (Green LED)
    - Better "power good" indication
    2. Added missing DC-DC input capacitors:
    - C5,C7,C9: 100µF 25V bulk input caps (C2907)
    - C6,C8,C10: 100nF 50V decoupling caps (C49678)
    3. Added missing output capacitor:
    - C11: 470µF 25V for -13.5V stage (C3351)
    4. Fixed capacitor designator conflicts:
    - ICL7660: C9,C10 → C12,C13
    - Linear regs: C11-C13 → C14-C25
    5. Reorganized capacitor tables for clarity:
    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
2025-12-27 Convert Diagram1 (USB-PD section) to ASCII-only characters
    Converted USB-C connector and CH224Q circuit diagram from Unicode
    box-drawing characters to ASCII for better compatibility:
    - Replaced Unicode arrows (→ ←) with ASCII (-> <-)
    - Replaced box-drawing characters with ASCII (+-|)
    - Maintained clear visual structure and readability
    - Consistent with other diagram updates in the project
2025-12-27 Update buck converter diagram with proper component leg representation
    - Show C5/C6 with 2 legs each: side connection (→ GND) and bottom (to +15V)
    - Fix C3 alignment with proper junction symbols (┴ top, ┬ bottom)
    - Remove useless connection point labels from feedback diagram
    - FB pin now correctly connects between R1 and R2
2025-12-28 Fix column alignment in buck converter diagram
    Auto-fixed 11 column sliding issues using fix-column-alignment script
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2025-12-28 Add click-to-enlarge functionality for circuit diagrams
    - Create CircuitDialog component for fullscreen SVG viewing
    - Add interactive hover and click handlers to CircuitSvg
    - Scale SVG to 90vw × 90vh with black background
    - Override fixed SVG dimensions with width/height props
    - Support keyboard (Enter/Space/ESC) and backdrop click to close
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2025-12-29 Replace L7812CV with L7812CD2T-TR for 100% SMD design
    Replace through-hole L7812CV (C2914, TO-220) with surface-mount
    L7812CD2T-TR (C13456, TO-263-2) to enable full PCBA assembly.
    Changes:
    - Update U6 regulator from TO-220 to TO-263-2 package
    - Download and integrate new footprint, SVG, and datasheet
    - Update documentation with SMD-specific thermal and layout specs
    - Remove all through-hole footprint and documentation files
    - Improve thermal performance: θJA 50°C/W → 35°C/W (30% better)
    - Junction temp at full load: 115°C → 88°C (27°C cooler)
    The design is now 100% surface-mount compatible with automated
    JLCPCB SMT assembly. All three voltage regulators (U6, U7, U8)
    now use SMD p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
2025-12-29 Fix ICL7660M pinout in Diagram3 - correct pin assignments
    ERROR FIXED: Previously showed pins 2 and 8 both as V+ (incorrect!)
    CORRECT PINOUT (verified from component datasheet):
    - Pin 1: NC (No Connection)
    - Pin 2: CAP+ (flying capacitor positive terminal)
    - Pin 3: GND
    - Pin 4: CAP- (flying capacitor negative terminal)
    - Pin 5: VOUT (negative voltage output -15V)
    - Pin 6: LV (low voltage mode, leave OPEN)
    - Pin 7: OSC (oscillator, leave OPEN)
    - Pin 8: V+ (positive input +15V) ← ONLY power input pin
    The ICL7660M has ONLY ONE V+ pin (pin 8), not two.
    Flying capacitor C12 connects between pins 2 and 4 only.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
2025-12-29 Fix ICL7660M diagram - remove line crossing and add capacitor symbol
    Fixed:
    - ✅ Removed line crossing over pin 3 (GND) - violates golden rule
    - ✅ Added capacitor box symbol for C12 between pins 2 and 4
    - ✅ Separated IC connections from capacitor diagram for clarity
    - Pins 2 and 4 now labeled as "Pin 2" and "Pin 4" (connection points)
    - Flying capacitor C12 shown separately below IC with box symbol
    - No ambiguous line crossings over labels
    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
2025-12-29 Remove connection lines from unused ICL7660M pins
    Removed lines from:
    - Pin 1 (NC - No Connection) - not used
    - Pin 6 (LV - Low Voltage) - left OPEN for normal mode
    - Pin 7 (OSC - Oscillator) - left OPEN for internal 10kHz
    Only pins with actual connections now show lines:
    ✓ Pin 3 (GND) - connected to ground
    ✓ Pin 8 (V+) - connected to +15V
    ✓ Pins 2, 4, 5 - charge pump and output
    Cleaner diagram - only shows actual connections!
    Note: NC = No Connection (N = No, C = Connection)
2025-12-29 Fix LM2596S-ADJ pinout in Diagram4 - CRITICAL ERROR CORRECTION
    MAJOR ERROR FIXED: Pinout was completely backwards!
    WRONG pinout (before):
    - Pin 5: VIN
    - Pin 4: VOUT
    - Pin 3: ON
    - Pin 2: FB
    - Pin 1: GND
    CORRECT pinout (verified from datasheet):
    - Pin 1: VIN (input voltage)
    - Pin 2: OUT (switching output)
    - Pin 3: GND (ground)
    - Pin 4: FB (feedback)
    - Pin 5: ON/OFF (enable/shutdown, left floating)
    ✓ -15V IN now connects to Pin 1 (VIN), not Pin 5
    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
2025-12-30 Fix Diagram1 to use 6-pin USB-C connector pinout
    - Update Diagram1-1 J1 connector to show 6-pin layout (pins 1-6)
    - Change pin labels from 24-pin format (A5, B5, A9, B9, etc.) to 6-pin format (1-6)
    - Add note explaining 6-pin connector (C2927029) pin assignments
    - Update Connection List to use 6-pin pin numbers:
    - VBUS: pins 2, 5 (was B9, A9)
    - CC1: pin 3 (was A5)
    - CC2: pin 4 (was B5)
    - GND: pins 1, 6 (was B12, A12)
    This matches the USB-C connector documentation update to 6-pin power-only design.
2025-12-30 Fix buck-u2-diagram.py output path to match documentation structure
    Update SVG output path from '../docs/_fragments/' to '../doc/static/circuits/' to align with the current documentation organization where circuit diagrams are stored in the static/circuits directory.
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2025-12-30 Add footprint SVGs to documentation fragments and update footprint files
    Reorganize footprint assets:
    - Add footprint SVGs to doc/docs/_fragments/footprints/ for React imports
    - Update footprint images with metadata corrections
    - Add new footprint files (F1210, LM7812_SMD, DIP-14, etc.)
    - Add footprint generation scripts
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2025-12-31 Fix duplicate SVG rendering in circuit diagrams
    Problem: Diagram2 and Diagram3 were rendering SVGs twice
    - Once in main circuit-diagrams.mdx file
    - Once inside fragment component
    Solution: Move SVG rendering to fragment files only
    - Remove duplicate CircuitSvg from circuit-diagrams.mdx (Diagram2, Diagram3)
    - Add CircuitSvg to buck-u3-diagram.mdx fragment
    - Update summary text: "Circuit Diagram" → "View ASCII art version"
    Result: Both diagrams now show one SVG + collapsible ASCII art
    Pattern: Main file imports fragments, fragments contain SVG + ASCII
    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
2025-12-31 Add LM7805 and LM7912 linear regulator diagrams (Diagram7/8)
    Diagram7 (ldo-u7): LM7805 +7.5V → +5V
    - Components: U7, C22/C15 (input), C18/C23 (output), PTC2, TVS2, R8, LED3
    - Blue status LED for +5V rail
    Diagram8 (ldo-u8): LM7912 -13.5V → -12V (Negative Voltage)
    - Components: U8, C24/C16 (input), C19/C25 (output), PTC3, TVS3, R9, LED4
    - Red status LED for -12V rail
    - Reversed polarity: electrolytic caps (C24, C25) and LED4
    - LM7912 pinout: pin 1=IN, pin 2=OUT, pin 3=GND
    Both diagrams refactored from Diagram6 with verified component values.
2025-12-31 Fix Mermaid diagram syntax following mermaid-generator guidelines
    - Remove HTML tags (no <br/> allowed in Mermaid)
    - Remove style directives (forbidden by Mermaid best practices)
    - Use multi-line labels with proper newline syntax
    - Clean, error-free flowchart following strict Mermaid syntax rules
    Generated following mermaid-generator skill guidelines for error-free diagrams.
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2026-01-01 fix: clarify COUT as shunt capacitor in diagram4
    Changed Output Filter ASCII diagram to clearly show COUT as a
    parallel/shunt capacitor between -15V output and GND, rather than
    intercepting the horizontal line.
    Before (ambiguous):
    C1/L2/D1 Junction ──┬─── COUT (100µF) ─── -15V OUT
    │ (To Diagram5)
    GND
    After (clear parallel connection):
    -15V OUT
    (To Diagram5)
    C1/L2/D1 Junction ─────────┤
    COUT
    (100µF)
    │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
2026-01-01 docs: use concrete component designators in diagram4 (U5 inverted SEPIC)
    Replace generic labels with actual PCB component designators:
    - CIN → C13 (input filter capacitor)
    - COUT → C14 (output filter capacitor)
    - L1 → L4 (input inductor)
    - L2 → L5 (output inductor)
    - C1 → C12 (coupling capacitor)
    - D1 → D4 (Schottky diode)
    - R1 → R7 (feedback upper resistor)
    - R2 → R8 (feedback lower resistor)
    This makes the ASCII diagram match the actual BOM and improves
    clarity when cross-referencing between circuit diagram and PCB
    component placement.
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2026-01-04 wip: Update DC-DC conversion schematic for Diagram4 (U4)
    Work in progress on inverting buck-boost circuit (U4) in KiCad:
    - LM2596S-ADJ symbol with TAB pin
    - Input capacitors C9 (100µF) and C10 (100nF) with correct values
    - Inductor L3 (100µH)
    - Diode D3 (SS34)
    - Output capacitor C11 (470µF 25V)
    - Feedback network R5 (10k), R6 (1k), C33 (22nF)
    - Component placement and routing
    Next steps:
    - Connect TAB pin to -13.5V OUT rail (IC GND)
    - Verify all connections match Diagram4 documentation
    - Complete PCB layout considerations
    [dc-dc-conversion.kicad_sch]
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2026-01-11 Improve PCB layout for JLCPCB v1.1 production
    - Fix via-in-pad issues for small passive components
    - Add thermal via arrays under IC thermal pads
    - Update trace widths to 0.7mm for 3A USB-PD input paths
    - Adjust component placements and routing
    - Remove unused output schematic elements
    [output.kicad_sch, zudo-pd.kicad_pcb]
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2026-01-20 fix: Change R12 from 22kΩ to 33kΩ to fix Vgs exceeding max rating
    The previous 22kΩ value resulted in Vgs = -12.3V at 15V VBUS, which
    exceeded the AO3401A's ±12V maximum rating. Changing to 33kΩ gives:
    - Gate voltage: 2.7V → 3.7V
    - Vgs: -12.3V → -11.3V (now within ±12V spec)
    - Margin to limit: 0.3V → 0.7V
    Updated files:
    - BOM: R12 part number C114065 → C4216 (33kΩ)
    - Circuit diagrams: All R12 references and soft-start calculations
    - Learning article: Voltage divider calculations and examples
    - Component docs: ao3401a.md, stusb4500.md
    - KiCad schematic: usb-pd-input.kicad_sch
    [usb-pd-input.kicad_sch]
2026-01-20 fix: Correct RESET pin configuration - active-HIGH, connect to GND
    RESET pin on STUSB4500 is active-HIGH (not active-low):
    - HIGH = device held in reset
    - LOW = normal operation
    - Remove R14 (10kΩ pull-up to VDD) from BOM and schematic
    - Connect RESET pin directly to GND
    - Update all documentation to reflect active-HIGH behavior
    - Mark R14 as DNP in KiCad schematic
    Previous design would have kept the IC in permanent reset state.
    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
    [usb-pd-input.kicad_sch]
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2026-02-01 fix: Correct project name in hierarchical schematic instances
    All sub-sheet instance blocks had inconsistent project names - some used
    (project "") while others used (project "zudo-pd"). This caused KiCad to
    display "?" for designators when opening sub-sheets.
    Changed all instances to use (project "zudo-pd") consistently across:
    - usb-pd-input.kicad_sch (16 → 31 fixed)
    - dc-dc-conversion.kicad_sch (14 → 49 fixed)
    - linear-regulation.kicad_sch (26 → 46 fixed)
    - output.kicad_sch (3 → 6 fixed)
    [dc-dc-conversion.kicad_sch, linear-regulation.kicad_sch, output.kicad_sch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]
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2026-02-14 fix: Update 470uF capacitor LCSC part C2992611 to C22387780
    The final JLCPCB order used C22387780 for capacitors C14, C20, C21,
    C24, C25. Update schematic, PCB layout, BOM, and footprint docs to
    match the actually ordered part.
    [linear-regulation.kicad_sch, zudo-pd.kicad_pcb]
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2026-02-14 fix: Disconnect VSYS from VREG_2V7 net in KiCad schematic
    Remove the incorrect wire connecting VSYS (pin 22) to VREG_2V7 (pin 23)
    on the STUSB4500. VSYS is now extended to GND and pin 18 (VBUS_VS_DISCH)
    has a no_connect marker added as a placeholder until the series resistor
    connection is implemented.
    [usb-pd-input.kicad_sch]
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2026-02-18 docs: Add NVM programming guide and fix LCSC part numbers in schematics
    Add comprehensive STUSB4500 NVM programming documentation covering
    hardware setup (NUCLEO-F072RB + pogo pin clip), target PDO configuration
    (15V/3A), and programming procedure. Fix LCSC part numbers in KiCad
    schematics: add missing parts to usb-pd-input components, correct C9
    voltage rating from 25V to 50V in dc-dc-conversion.
    [dc-dc-conversion.kicad_sch, usb-pd-input.kicad_sch]
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2026-02-18 fix: Add missing footprints and LCSC Part numbers to R15, R16, J2
    R15/R16: footprint zudo-pd:R0603, LCSC Part C25999 (4.7k 0603 Basic)
    J2: footprint zudo-pd:PogoPad_1x04_P2.54mm (no LCSC, bare copper pads)
    [usb-pd-input.kicad_sch]
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2026-05-17 feat(hardware): v3 CC pin fix — external 10k Rd on CC1/CC2, CC1DB/CC2DB to GND
    Fixed STUSB4500 USB-PD controller issue on v2 PCBAs where CC1DB was internally shorted to GND. Solution: added external 10kΩ pulldown resistors (R17/R18) on CC1/CC2 lines and rerouted U1 pins 1 (CC1DB) and 5 (CC2DB) directly to GND instead of CC1/CC2 nets. Updated BOM with all pulldown entries (R15/R16 existing, R17/R18 new for v3).
    [dc-dc-conversion.kicad_sch, linear-regulation.kicad_sch, output.kicad_sch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]
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2026-05-17 feat(usb-pd): add v3 test point pogo block (J3) + 1x8 pogo footprint
    Added a new test point header (J3) with 1x8 pogo pad footprint to enable chip-level
    debugging of STUSB4500 signals on v3. Pogo pads allow future signal access without
    hot-air rework (the painful v2 workaround). Includes:
    - New PogoPad_1x08_P2.54mm footprint for both master and KiCad library copies
    - J3 connector wired to key STUSB4500 signals in schematic
    - Planning doc (test-points-v3.md) with full signal mapping
    - Also bumped R17/R18 values in usb-pd-input.kicad_sch as part of v3 finalization
    [usb-pd-input.kicad_sch]
2026-05-17 fix(pcb): adjust v3 pogo pad diameter (0.6mm → 0.5mm) and place R18 5.1k Rd resistor
    Fine-tune pogo pad diameter for v3 test point block (J3) and place the external 5.1k Rd resistor
    in USB-PD input stage, matching the schematic update from commit 68b4e18.
    [zudo-pd.kicad_pcb]
2026-05-18 feat(usb-pd): add 0 Ω jumpers (R19/R20) on CC1DB/CC2DB → GND for v3 chip isolation & test point resilience
    Implements defensive v3 CC pin fix:
    - Add R19 (0 Ω, 0603) from STUSB4500 CC1DB pin to GND
    - Add R20 (0 Ω, 0603) from STUSB4500 CC2DB pin to GND
    - Preserves named `CC1DB`/`CC2DB` nets for J3 pogo probing and future chip-isolation debug
    - Net `GND` → `GND rail` for PCB copper pour clarity
    - Schematic cleanup: reorganize junctions to reflect actual net topology
    Documentation updated to reflect completed implementation steps and test point function.
    [usb-pd-input.kicad_sch, zudo-pd.kicad_pcb]
2026-05-18 fix(pcb): reposition test points, pogo header, and silkscreen labels for v3 layout
    Adjusts reference designators and labels on J3 pogo block, TP1/TP2/TP3 test points, and silkscreen text to match optimized component placement. Improves clarity for board assembly and debug probing access.
    [zudo-pd.kicad_pcb]
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2026-05-19 feat(usb-pd): apply JLCPCB pre-production LCSC part swaps for v3
    - C4/C22/C23 (470µF 16V): C46550400 → C970706 (DMBJ RVT1C471M0810, D8×L10.2mm)
    - C2/C6/C8/C10/C17/C18/C19/C35 (100nF 50V X7R 0805): C49678 → C1711 (Samsung CL21B104KBCNNNC)
    - R12 (56k 0603): align BOM C23168 → C23206 (Uniroyal) to match schematic
    Updated LCSC Part properties in dc-dc-conversion, linear-regulation, and usb-pd-input schematics.
    [dc-dc-conversion.kicad_sch, linear-regulation.kicad_sch, usb-pd-input.kicad_sch]
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2026-05-20 fix(usb-pd): swap C4/C22/C23 to D6.3 470µF cap to resolve JLCPCB footprint mismatch
    - C4/C22/C23: C970706 (D8×L10.2mm) → C2977552 (DMBJ RVT1C471M0607, D6.3×L7.7mm, 470µF/16V)
    - JLCPCB flagged the D8 part as not fitting the D6.3 pad pattern during pre-production review
    - Same DMBJ RVT series as the in-order C22383804 (C5/C7/C9), so land-pattern fit is empirically proven
    - Updated bom.md, footprint-preview.md (removed v3 trade-off note), and stale Datasheet URLs in schematics
    [dc-dc-conversion.kicad_sch, linear-regulation.kicad_sch]
2026-05-21 fix(usb-pd): re-swap C4/C22/C23 to ACMECON C22383803 (Economic-tier PCBA compatible)
    - C4/C22/C23: C2977552 (ROQANG, Standard-only) → C22383803 (ACMECON, Economic+Standard)
    - Same MPN RVT1C471M0607, same D6.3×L7.7mm case, same 470µF/16V — drop-in equivalent
    - C2977552 from prior commit 6a65444 was blocked by JLCPCB's PCBA-tier restriction (Standard Only)
    - Updated bom.md, footprint-preview.md, and schematic LCSC Part / Datasheet properties
    [dc-dc-conversion.kicad_sch, linear-regulation.kicad_sch]
2026-05-31 fix(usb-pd): wire STUSB4500 pin18 VBUS_VS_DISCH to VBUS_IN via R14 series resistor
    This fixes the root cause of v3 failing to negotiate USB-PD. Pin 18
    (VBUS_VS_DISCH) was left floating. Corrections:
    - Wire pin 18 to VBUS_IN through series resistor R14 (470Ω)
    - Add test point TP6 on VBUS_VS_DISCH net for diagnostics
    - Fix R14 footprint from unresolved easyeda2kicad:R0603 to zudo-pd:R0603
    - Remove incorrect divider-to-GND resistor network (now single series topology)
    - Update PCB layout to match schematic changes (R14 placement, TP6, routing)
    [usb-pd-input.kicad_sch, zudo-pd.kicad_pcb]
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2026-06-04 fix(usb-pd): v0.4.0 faston swap to C591344 + harmonize BOM comments
    - J6-J9 faston: C305825 (TE 1217754-1, out of stock) -> C591344
    (TE 63951-1, same physical tab/footprint, strip packaging)
    - Harmonize Comment/Value so duplicate-LCSC lines collapse to one
    BOM row each: 470ohm (R13,R14), 100nF 50V (8x), 470uF 16V (C4,C22,C23)
    - PCB synced from schematic (Update PCB from Schematic)
    [dc-dc-conversion.kicad_sch, linear-regulation.kicad_sch, output.kicad_sch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]
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2026-06-16 spike(ai-circuit-design): circuit-synth on linear-regulation (issue #75)
    Approach B timeboxed spike: model the three LDO stages (U6 L7812 +12V,
    U7 L7805 +5V, U8 7912 -12V) as hierarchical circuit-synth @circuit
    functions and emit a real KiCad project, validated headlessly.
    Results:
    - circuit-synth 0.12.1 installed cleanly on Python 3.14.4 (all cp314/pure
    wheels, no compile, no pyenv).
    - generate_kicad_project() produced a hierarchical project (root + 3
    sub-sheets, 27 parts); kicad-cli v10 (sch export netlist) parsed it
    cleanly. Emitted (version 20250114) [KiCad v9 token] vs repo v10
    (20260306) -- forward-compatible on read.
    - Placement is mechanical text-flow with ZERO drawn wires;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
    [linear_regulation.kicad_sch, neg_12v_stage.kicad_sch, pos_12v_stage.kicad_sch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]
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2026-06-16 fix(experiments): address deep-review findings (SPICE model, LED polarity, skill perms)
    Codex review (P2) fixes on the A–D trial artifacts:
    - SPICE value-sizing deck: the loop-closed check pinned FB to Vref via an ideal
    source, which floated VOUT (KCL forced VOUT==FB≈1.23V). Replaced with a
    high-gain error-amp behavioral source driving the real divider, so .op now
    genuinely solves VOUT=Vref*(1+Rtop/Rbot). Same fix in the sweep deck; FINDINGS
    method note updated.
    - circuit-synth spike: Device:LED pin1=cathode/pin2=anode, but the helper wired
    the positive rail to pin1 → reverse-biased +12V/+5V indicator LEDs. Added a
    rail-aware `negative` flag; positive stages now anode→rai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
    [linear_regulation.kicad_sch, neg_12v_stage.kicad_sch, pos_12v_stage.kicad_sch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]
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2026-09-20 feat(pcb): renew split power boards and component contracts
    Separate the PD module from the compact synth power board, preserve the
    three rail targets, and replace regulators and connectors with reviewed
    part selections. Include routed revisions, aligned local models, edge
    pogo contacts, front-down mounting geometry and source-bound checks.
    Retain earlier layout revisions and keep large assembly STEP previews
    local and outside Git. Preserve the validated project settings separately from a
    later local KiCad save.
    [ASPI-0630LR_MaxEnvelope_L7.5-W6.85-H3.0.step, C0603_L1.6-W0.8-H0.8.step, C0805_L2.0-W1.3-H1.3.step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]
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2026-09-21 fix(board-p): replace out-of-stock D5 TVS with Littelfuse SMAJ16A (C74561)
    Vishay SMAJ16A-E3/61 (C968650) was out of stock at JLCPCB. Footprint pads and package updated; schematic routing unchanged.
    [board-p.kicad_pcb, board-p.kicad_sch]
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2026-09-21 fix(board-b): replace out-of-stock LDOs, add U8 ADJ divider, correct LED2 polarity
    Replace U6/U7 LT1963AEQ#PBF (C107286) with LT1963AEQ#TRPBF (C459702);
    U8 fixed LT3015EQ-12#PBF (C666307) with adjustable LT3015EQ#PBF (C666306)
    and new R26/R27/R28 divider (nominal −12.054 V). Also: LED2 (C2289) symbol
    pin numbering corrected to pin 1 = cathode per LCSC library and footprint
    turned 180° with copper unchanged (JLCPCB preview showed it reversed);
    front/back silkscreen tidied; P1 label rule in verify-compact-mechanics.py relaxed
    to nearest-own-contact.
    [board-b.kicad_pcb, board-b.kicad_sch]
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
